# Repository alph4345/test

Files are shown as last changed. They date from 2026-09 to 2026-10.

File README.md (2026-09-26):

# Supercapacitor-powered gadgets

Small games, e-ink displays, blinky jewellery and music toys that charge from
USB-C in minutes and run from a **supercapacitor instead of a LiPo**. The
idea comes from the
[rechargeable supercapacitor Fibonacci earrings](https://lectronz.com/products/rechargeable-supercapacitor-fibonacci-earrings-2).

This repository has:

* **[TrinketCore](hardware/trinketcore)**: an all-in-one 40 × 60 mm trinket
  board with PCBWay order files. It has:
  * pads for two capacitors lying flat on the back;
  * USB-C charging with red "charging" and green "full" LEDs;
  * an RP2040 with 16 MB of flash;
  * a socket for OLED or colour TFT modules (the board reads its charge
    level and can show it);
  * a speaker amplifier, buttons, a wake-up clock and an expansion header.
* **[CapCore](hardware/capcore)**: an open, ready-to-order 21 × 48 mm power
  module (KiCad 7). It has a USB-C charger, capacitor protection, a power
  button, a wake-up clock and a 3.3 V output for your microcontroller.
  Gerbers and JLCPCB assembly files are included.
* **[The burst method](docs/trinket-design-method.md)**: how music boxes,
  games, pets and charms last days to weeks on a capacitor, and how colour
  TFT screens fit in.
* **[Energy budget](docs/energy-budget.md)**: how long a capacitor actually
  runs each kind of gadget, plus a [calculator](tools/energy_calc.py).
* **[Choosing a capacitor](docs/choosing-a-capacitor.md)**: lithium-ion
  capacitors vs. ordinary supercapacitors, part numbers, safety rules.
* **[Buy or build?](docs/buy-or-build.md)**: sourcing options and costs.
* **[Firmware examples](firmware)**: Arduino and MicroPython code for power
  button, sleep/wake, capacitor gauge and shutdown on CapCore, and
  CircuitPython charge-gauge, music-box and e-ink tarot-oracle examples for TrinketCore.

| TrinketCore top | TrinketCore back | CapCore top | CapCore bottom |
|---|---|---|---|
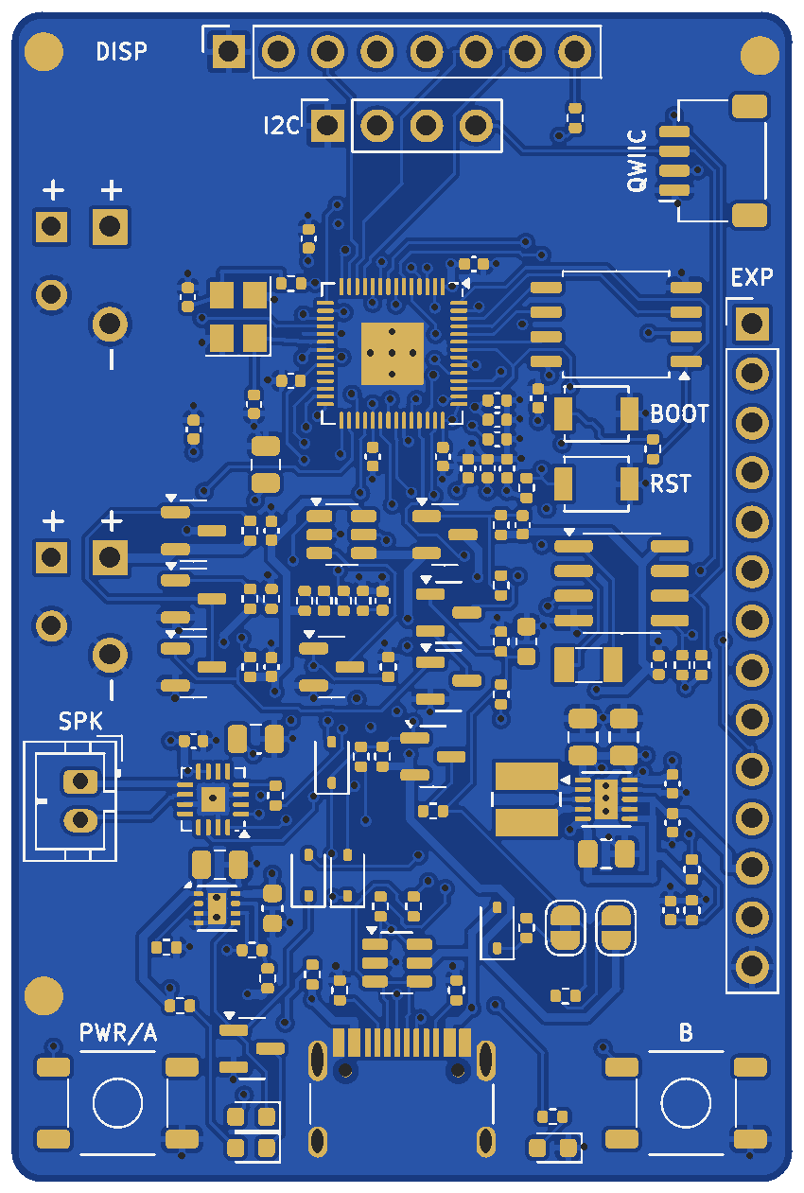
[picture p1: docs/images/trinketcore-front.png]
TrinketCore top
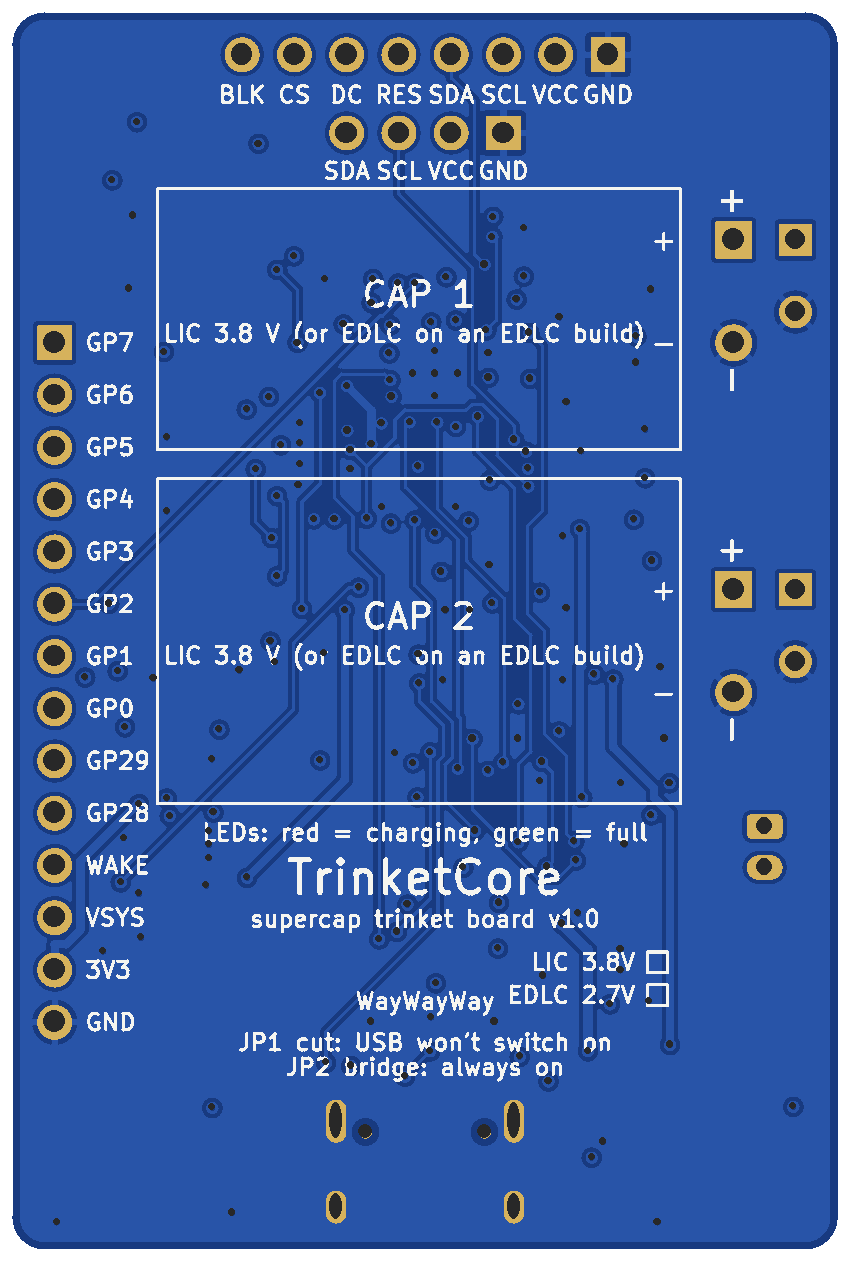
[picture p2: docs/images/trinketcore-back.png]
TrinketCore back
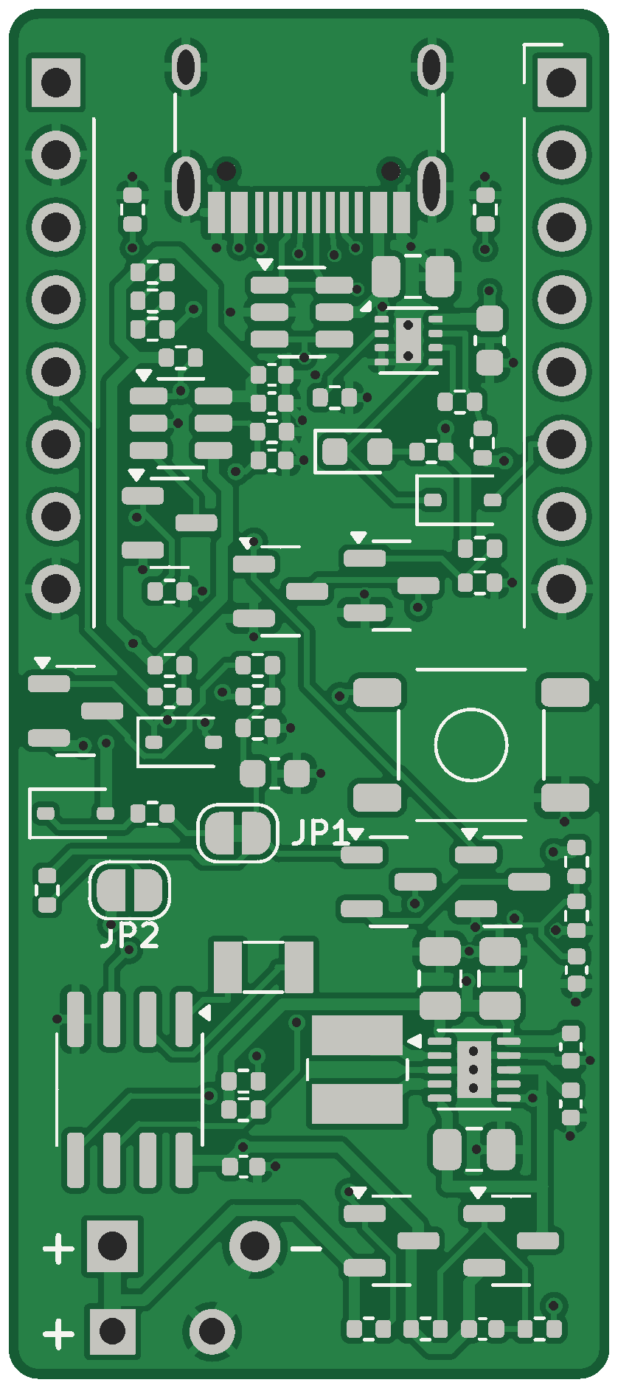
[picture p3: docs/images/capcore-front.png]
CapCore top
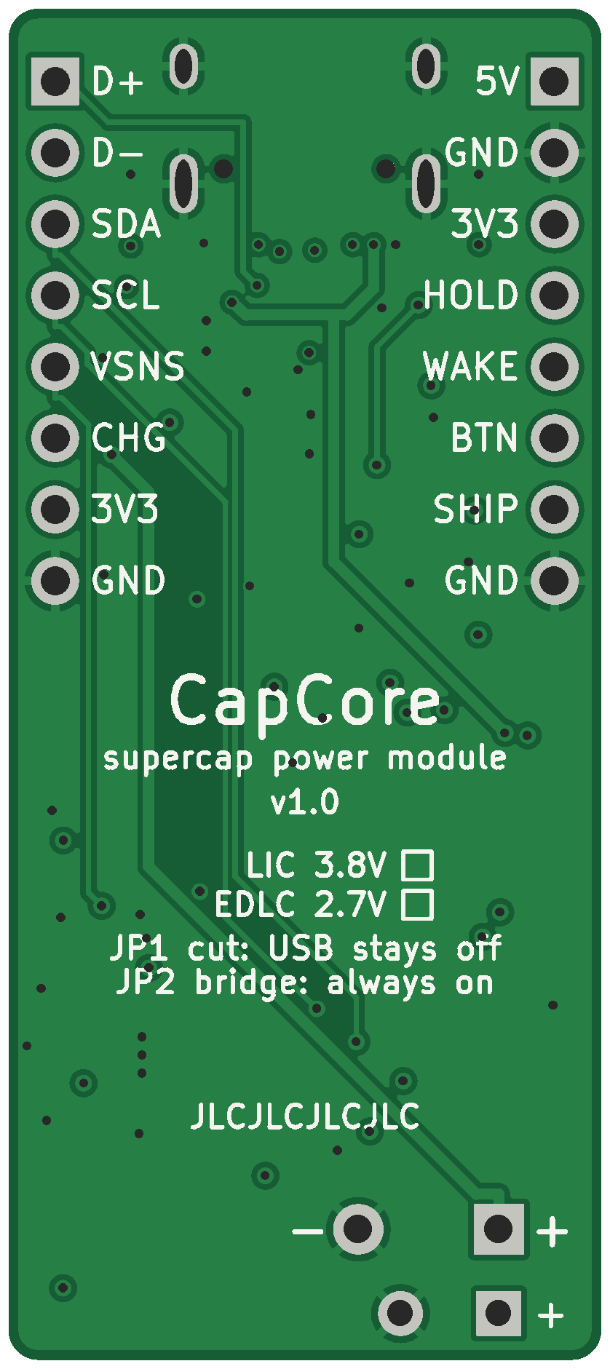
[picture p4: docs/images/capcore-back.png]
CapCore bottom
|  |  |  |  |

## The short answer

* **Capacitors are safe and fast but small.** A 3.8 V lithium-ion capacitor
  (LIC) the size of your fingertip stores ~30 mWh, about a tenth of a
  tiny 100 mAh LiPo. The largest common one (16 × 25 mm) stores ~210 mWh. In
  exchange it charges in minutes, lasts tens of thousands of cycles, and is
  far less of a fire risk. Plain 2.7 V supercapacitors (EDLCs) are essentially
  inert but hold about a tenth as much again for the same size.
* **What that runs, per charge** (with a 120 F LIC, 12.5 × 25 mm):
  LED jewellery ~1.5 days · e-ink display updated hourly ~6 weeks ·
  OLED handheld game ~50 min · MP3 player on a speaker ~15 min.
  E-ink and jewellery are great fits, games work for short sessions, music
  players are a stretch. [Details](docs/energy-budget.md).
* **The electronics matter.** LICs must never go below 2.2 V or above 3.8 V,
  and LiPo chargers (4.2 V) would destroy them. CapCore handles that: it
  charges to 3.71 V, disconnects at 2.61 V and stays off until USB returns.
  Build it for ordinary supercapacitors instead by changing two resistors.

## Quick start

1. Pick a capacitor: [choosing a capacitor](docs/choosing-a-capacitor.md).
2. **For a complete trinket:** order TrinketCore assembled from PCBWay with the
   files in [`hardware/trinketcore/fab`](hardware/trinketcore/fab). See
   [ordering](hardware/trinketcore/README.md#ordering-from-pcbway). Plug in a
   display module, fit the capacitors, and load the
   [CircuitPython examples](firmware/trinketcore).
3. **For your own microcontroller board:** order CapCore from JLCPCB with the
   files in [`hardware/capcore/fab`](hardware/capcore/fab) (see
   [ordering](hardware/capcore/README.md#ordering-from-jlcpcb)), run the
   [bring-up checks](hardware/capcore/README.md#bring-up), and wire it to your
   microcontroller ([Pico, Feather, bare chips](hardware/capcore/README.md#connecting-a-microcontroller)).

## Status

Both designs are complete and machine-checked: each schematic and PCB matches
its netlist pin for pin, and KiCad DRC is clean apart from cosmetic footprint
warnings. **Neither board has been manufactured and tested yet.** Order a
small first batch and follow the bring-up steps before building anything you
depend on.

## Repository layout

```
docs/                   guides and board renders
firmware/               Arduino + MicroPython (CapCore), CircuitPython (TrinketCore)
hardware/trinketcore/   all-in-one board: KiCad project, PCBWay files, generator scripts
hardware/capcore/       power module: KiCad project, JLCPCB files, generator scripts
tools/energy_calc.py    runtime calculator
```

No license file yet. Pick one before sharing the design: for example
CERN-OHL-P-2.0 for the hardware and MIT for the code.

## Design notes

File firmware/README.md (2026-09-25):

# Firmware examples

Two small, dependency-free examples of the firmware side of a
[CapCore](../hardware/capcore) gadget:

| | |
|---|---|
| [`arduino/CapCorePower`](arduino/CapCorePower/CapCorePower.ino) | Arduino sketch for any core with `Wire` (RP2040, ESP32, SAMD, nRF52…) |
| [`micropython/capcore.py`](micropython/capcore.py) + [`main.py`](micropython/main.py) | MicroPython driver + example for a Raspberry Pi Pico |

Both do the same five things:

1. **Raise `HOLD` first thing at boot.** After a button tap the board keeps
   power up for only 1–2 s on its own.
2. **Clear the RTC's alarm/timer flags** (PCF8563 register 0x01) and switch off
   its clock output (register 0x0D). A pending flag keeps the gadget on and
   makes `BTN` read as pressed.
3. **Read the capacitor:** voltage = 2 × `VSENSE`; `CHG` is low while charging.
   `percent()` reports the *energy* left between the cut-off and full, which
   tracks remaining runtime better than voltage does.
4. **Turn off:** wait for the button to be released, then drop `HOLD`. A long
   press (1.5 s) does this in the examples. Also turn off by yourself a
   little above the hardware cut-off so you can save state first.
5. **Sleep and wake:** `sleep_minutes(n)` / `sleepMinutes(n)` sets the
   PCF8563 countdown timer (1–255 minutes), then powers off. The timer
   switches the board back on. `wake_at(h, m)` does the same with the alarm.

`ship_mode()` disconnects the capacitor until USB is plugged in again. Use it
before storing a charged gadget.

## Default wiring (Pico)

| CapCore | Pico | |
|---|---|---|
| 3V3 (J2-3 or J3-7) | 3V3 (pin 36) | and Pico **3V3_EN (pin 37) → GND** |
| GND | GND | |
| HOLD (J2-4) | GP2 | output |
| BTN (J2-6) | GP3 | input, pull-up |
| SHIP (J2-7) | GP6 | output |
| CHG (J3-6) | GP7 | input, pull-up |
| VSENSE (J3-5) | GP26 / ADC0 | |
| SDA / SCL (J3-3 / J3-4) | GP4 / GP5 | I2C0, RTC at 0x51 |

For the EDLC build pass `variant=EDLC` (MicroPython) or change `V_FULL` /
`V_EMPTY` (Arduino).

## Power tips for long runtimes

* Budget with [`tools/energy_calc.py`](../tools/energy_calc.py). A few mA
  saved is often worth more than a bigger capacitor.
* Run the CPU slowly and sleep between frames. On the RP2040 a lower
  `machine.freq()` (MicroPython) or `set_sys_clock_khz()` (C SDK) cuts current a lot.
* For e-ink, don't keep the MCU running between updates: set the RTC timer
  and power the whole board off. Between updates it draws about 5 µA.
* Speakers are the hungriest load. Use headphones, keep the volume down, or
  pick a piezo for chiptune.

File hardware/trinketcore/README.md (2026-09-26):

# TrinketCore: the all-in-one supercapacitor trinket board

TrinketCore puts everything a small rechargeable gadget needs on one
40 × 60 mm board, ready to order assembled from PCBWay:

* **Room for two capacitors.** They lie flat on the back, wired in parallel.
* **USB-C charging**, with a **red "charging" and a green "full" LED**.
* **A socket for an OLED or colour TFT module.** The microcontroller reads
  the capacitor's charge and can show it on the screen.
* **An RP2040 microcontroller** with 16 MB of flash for code, sounds and
  pictures.
* **A speaker amplifier**, two buttons, a user LED, a wake-up clock and an
  expansion header for LEDs, buttons and a lid switch.

The power side is [CapCore](../capcore)'s proven circuit. It cuts off before
the capacitor over-discharges, uses a soft power switch that turns the whole
board off, and has a buck-boost converter that keeps 3.3 V steady as the
capacitor drains.

| Top | Bottom (capacitor bay) |
|---|---|
| TrinketCore top | TrinketCore bottom |

*Renders of the actual Gerber layers. The display plugs into the socket along
the top edge. The capacitors solder into the pads on the left and lie flat
inside the outlines on the back.*

## What's on the board

| | |
|---|---|
| Capacitors | BT1 + BT2 in parallel: one or two 3.8 V lithium-ion capacitors (LIC). **EDLC build:** 2.7 V supercapacitors |
| Charging | USB-C, TI BQ25173, 300 mA: two 220 F capacitors fill in about 30 minutes. **Red LED (CHG)** while charging, **green LED (FULL)** when full (USB plugged in) |
| Protection | disconnects at **2.61 V** (LIC) / **1.96 V** (EDLC) and stays off until USB returns; ship mode for storage |
| Power switch | the whole board is **off between uses (about 5 µA)**. It turns on from button A, a lid/tilt switch on `WAKE`, the clock alarm, or USB. Firmware keeps it on with `HOLD` |
| 3.3 V | TI TPS63031 buck-boost, ~500 mA even from a nearly empty capacitor |
| Microcontroller | Raspberry Pi RP2040, 12 MHz crystal, **16 MB** Winbond flash, USB-C data for programming, BOOT and RESET buttons (SWD is not broken out: the USB bootloader is in ROM) |
| Display | **J4**: socket for SPI TFT/OLED modules (GND VCC SCL SDA RES DC CS BLK), backlight dimmable by PWM. **J5**: 4-pin I²C OLED socket. **J8**: Qwiic/STEMMA QT |
| Charge reading | capacitor voltage on an ADC pin, plus "charging" and "USB present" inputs |
| Sound | MAX98357A I²S class-D amplifier, 9 dB gain, shut down when idle; **J7** speaker connector (JST PH 2.0 or solder the wires) |
| Clock | NXP PCF8563 real-time clock: wakes the board on a timer or alarm (virtual pets, e-ink updates) |
| Buttons | **A / POWER** (turns the board on and is readable by firmware), **B**, BOOT, RESET |
| LEDs | red CHG, green FULL (charging), blue user LED on GP25 |
| Expansion | **J6**, 14 pins: GP0–GP7, GP28–GP29 (analog), `WAKE`, `VSYS`, 3V3, GND |
| Board | 4 layers, 40 × 60 × 1.6 mm, all parts on top, PCBWay standard rules (6/6 mil, 0.3 mm holes) |

## Which display?

The socket fits the common 0.96–1.54″ modules, so you can try several and pick
per product. A screen is the second-biggest power draw after a speaker, so
the firmware uses it in short bursts: wake, show, dim, switch off.

| Display | Colour | Draw (with the RP2040 running) | Good for |
|---|---|---|---|
| 0.96″ SSD1306 OLED, 128 × 64 (SPI on J4 or I²C on J5) | mono | ~35–40 mA; dark screens use less | games, menus, pets |
| 1.3–1.54″ ST7789 IPS TFT, 240 × 240 | **full colour** | ~45 mA at 60 % backlight, ~30 mA dimmed | colour animations, charms, games |
| 1.28″ GC9A01 round TFT, 240 × 240 | **full colour** | about the same as the ST7789 | keychain "digital charms" |
| 1.54″ 200 × 200 or 3.7″ 480 × 280 e-paper module (SSD1681 and similar) | black/white, 4 greys, or black/white/red | nothing between refreshes; ~30 mA for 2–3 s per black/white refresh (~14 s for three-colour) | tarot oracles, badges, pets, clocks: always visible |

**Yes, colour TFTs work well.** The backlight is most of the extra power, so
dim it and switch off after a few seconds. On two 220 F capacitors a colour
charm shown for 10 s, 30 times a day, lasts about four weeks. Played
continuously, a colour game lasts about two hours. See
[the design method](../../docs/trinket-design-method.md) for the numbers.

Module pin orders vary. Modules labelled `GND VCC SCL SDA RES DC CS BLK` plug
straight into J4. Seven-pin OLEDs (`GND VCC D0 D1 RES DC CS`) use the first
seven positions. Others, including many GC9A01 modules (`VCC GND ...`), need
short jumper wires. **Check that GND and VCC line up before plugging in.**

**E-ink works too**, and suits anything that should stay visible: the image
costs no power at all once drawn, so the board can switch fully off. E-paper
modules have a BUSY output where TFTs have a backlight input. Wire them to J4
by function (VCC → 3V3, GND, DIN → MOSI, CLK → SCK, CS, DC, RST → RES) with
BUSY on the BLK pin, which the RP2040 reads on GP13. The
[oracle example](../../firmware/trinketcore/circuitpython/oracle/code.py) shows a
random tarot card this way.

## Runtime per charge

LIC build, 85 % converter efficiency, 5 µA standby
([`tools/energy_calc.py`](../../tools/energy_calc.py)):

| Trinket | 1 × 120 F | 1 × 220 F | 2 × 220 F |
|---|---|---|---|
| Music box: 20 s tune + LEDs (~70 mA), 10 plays a day | 75 plays (8 days) | 138 plays (14 days) | 276 plays (4 weeks) |
| Colour TFT charm: 10 s shows (45 mA), 30 a day | 8 days | 14 days | 4 weeks |
| Virtual pet on e-paper: wakes every 30 min (30 mA × 3 s) | 3 weeks | 6 weeks | 3 months* |
| Tarot oracle on e-paper: a card per press (30 mA × 5 s), 10 a day | 600 draws (2 months) | 1,100 draws* | 2,200 draws* |
| OLED game, continuous (40 mA) | 45 min | 80 min | 2.7 h |
| Colour TFT game, continuous (55 mA) | 33 min | 60 min | 2 h |

\* Beyond a month or two the capacitors' own self-discharge dominates.

## Fitting the capacitors

The two capacitor positions sit along the left edge. **Square pad = +.** Each
position takes a 5.0 mm lead pitch (10–12.5 mm cans) or 3.5 mm (8 mm cans).
Bend 16 mm cans' 7.5 mm leads in slightly. Bend the leads 90° so each can lies
flat on the back inside its outline (`CAP 1`, `CAP 2`), with its leads at the
left edge. Stick a strip of Kapton tape under each can, and glue or strap
large cans.

* One capacitor is fine: fit either position.
* Two capacitors must be **the same type** (both LIC, or both EDLC on an EDLC
  build). Sizes may differ.
* Good choices: Eaton HS1225-3R8127-R (120 F, 12.5 × 25 mm) or HS1625-3R8227-R
  (220 F, 16 × 25 mm). See [choosing a capacitor](../../docs/choosing-a-capacitor.md).

> **Never fit a 2.7 V supercapacitor to a board built with the LIC values.**
> It would be charged to 3.71 V and can vent. Tick the build box on the back,
> and measure the charge voltage before fitting capacitors (see
> [Bring-up](#bring-up)).

## Pinout

**J4 display socket** (top edge, pin 1 = square pad, left):
GND · 3V3 · SCK (GP10) · MOSI (GP11) · RES (GP12) · DC (GP9) · CS (GP8) · BLK (GP13 via 100 Ω)

**J5 I²C OLED socket**: GND · 3V3 · SCL (GP17) · SDA (GP16).
**J8 Qwiic**: GND · 3V3 · SDA · SCL. The same bus as the clock (address 0x51),
with 4.7 kΩ pull-ups.

**J6 expansion** (right edge, pin 1 at the top): GP7 · GP6 · GP5 · GP4 · GP3 ·
GP2 · GP1 · GP0 · GP29 · GP28 · WAKE · VSYS · 3V3 · GND. The order matches the
RP2040's pins, which keeps the tracks from crossing; the back silkscreen labels
every pin.

* `WAKE`: pull to GND to switch the board on (lid, tilt, reed or vibration
  switch). For a **lid** that may stay open, put a 1 µF capacitor in series
  with the switch and a 22 MΩ resistor across that capacitor. Opening the
  lid then sends one wake pulse, and the board can still switch itself off.
* `VSYS`: the capacitor voltage (2.6–3.7 V), on only while the board runs.
  Use it for vibration motors or LED strips that tolerate it.
* GPIO pins drive LEDs directly, up to ~8 mA each through a resistor.

**J7 speaker**: 8 Ω, 0.5–1 W. **GPIO map**: see the
[firmware README](../../firmware/trinketcore/README.md#pin-map).

## LEDs and power states

| LED | Meaning |
|---|---|
| red **CHG** | charging |
| green **FULL** | USB plugged in and the capacitors are full |
| red and green blinking alternately | charger fault (for example a capacitor wired backwards, or overheating) |
| blue | yours (GP25) |

With USB plugged in the board also switches on, so a gauge can show charging
progress. Cut jumper **JP1** on the back if plugging in should only charge.
Bridge **JP2** for gadgets without a power button (always on above the
cut-off).

| State | Drain from the capacitors | Leaves the state when… |
|---|---|---|
| Running | your load ÷ ~85 % | firmware drops `HOLD` |
| Off | ~5 µA (clock running) | button A, `WAKE`, clock alarm/timer, USB |
| Cut-off / ship mode | leakage only | USB is plugged in |

## Ordering from PCBWay

Everything is in [`fab/`](fab):

| File | Upload / use |
|---|---|
| `trinketcore-gerbers.zip` | the PCB (Gerbers + drill) |
| `pcbway-bom-lic.csv` (or `-edlc.csv`) | assembly BOM for your build |
| `pcbway-centroid.csv` | pick-and-place positions (mm, origin at the bottom-left corner, same as the Gerbers) |
| `trinketcore-assembly-top.pdf`, `-back.pdf` | assembly drawings, if PCBWay asks |
| `parts-list.csv` | every part, including the ones you fit yourself |

1. On pcbway.com choose **PCB Instant Quote → Quick-order PCB** and upload
   `trinketcore-gerbers.zip`. It should read **40 × 60 mm** and **4 layers**.
2. Board settings:
   * Material FR-4, thickness **1.6 mm**, any solder mask colour.
   * Min track/spacing **6/6 mil**, min hole size **0.3 mm**.
   * Surface finish: **ENIG is recommended** because the RP2040 has 0.4 mm-pitch
     pads. HASL lead-free usually works too.
   * Order number: the back has a `WayWayWay` placeholder where PCBWay can
     print it. Tell them in the notes, or pick the remove-order-number option.
3. Tick **Assembly service**: turnkey, **top side only**, about
   **102 SMD parts (44 unique lines)**, no through-hole parts. Upload
   `pcbway-bom-lic.csv` and `pcbway-centroid.csv`.
4. Paste this note:
   *"BT1, BT2, J4–J7, JP1–JP2: do not populate (customer fits
   capacitors and connectors). J8 and all other parts: assemble as per BOM.
   Please confirm pin 1 of U2, U3, U4, U5, U6, U7, U8 and the LED polarity
   against the silkscreen before assembly."*
5. PCBWay's engineers review the files, source the parts, and email if a part
   needs a substitute. Resistors and capacitors may be any brand with the same
   value, size and tolerance. Approve their placement confirmation photos.

**Rough cost** (prices change, so trust the quote): about US$25–50 for five
4-layer boards, plus assembly (setup ~US$30–50, parts ~US$8–12 per board
with the RP2040, flash and amplifier). Five assembled boards typically land
around US$100–180 before shipping. Most of that is fixed, so ten cost little
more.

The same files work at other assembly houses (the BOM has manufacturer part
numbers, and LCSC numbers where known).

## Bring-up

Before fitting the capacitors:

1. Plug in USB-C. The red and green LEDs may flicker (nothing to charge yet),
   and the board switches on.
2. Measure between the square BT1 pad and GND: about **3.7 V** is the LIC build,
   **2.6 V** the EDLC build.
3. The computer should show an `RPI-RP2` drive (blank flash starts the
   bootloader). Install CircuitPython and try the
   [charge gauge](../../firmware/trinketcore) with a display on J4.

Then unplug USB, fit the capacitors (**square pad = +**), and plug USB back
in: red while charging, green when full. Unplug and press A: the board runs
for about 5 s, or longer if firmware raises `HOLD`. A new capacitor that
arrives below the cut-off keeps the board off until it has charged past it.

## Design files

| File | |
|---|---|
| `trinketcore.kicad_pro/.kicad_sch/.kicad_pcb` | KiCad 7 project |
| `trinketcore-schematic.pdf` | schematic |
| `TrinketCore.kicad_sym`, `TrinketCore.pretty/` | project symbols and footprints |
| `trinketcore.ses` | autorouter result that `route_pcb.py` rebuilds the board from |
| `scripts/` | the generators |

As with CapCore, the board is generated from code:

```
cd hardware/trinketcore/scripts
python3 gen_footprints.py
python3 gen_schematic.py && python3 check_netlist.py
python3 check_place.py
FREEROUTING_JAR=/path/to/freerouting-1.9.0.jar python3 route_pcb.py --autoroute
python3 check_netlist.py --pcb && python3 export_fab.py && python3 render.py
```

`netlist.py` is the single source of truth: parts, values, manufacturer part
numbers and every connection. Autorouting needs Java and
[Freerouting](https://github.com/freerouting/freerouting) 1.9.0 (under
`xvfb-run` on a headless machine); without `--autoroute` the board is rebuilt
from the committed `trinketcore.ses`. The crystal and the power fan-outs are
drawn by hand in `preroute.py`, and a small grid router (`maze.py`) finishes
whatever Freerouting leaves open.

**Verification status:** the schematic and PCB are checked pin-for-pin against
`netlist.py` (378 pins). KiCad DRC with PCBWay's limits reports no errors and
no unconnected items, only one warning: the USB-C footprint differs from the
library copy because its silkscreen was trimmed at the board edge. The routing
is automatic, so some tracks take detours a hand layout wouldn't. The board
has **not been built and tested yet**: treat the first order as a prototype run
and follow the bring-up steps.

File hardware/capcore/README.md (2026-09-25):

# CapCore: supercapacitor power module

CapCore is a 21 × 48 mm board that does the power side of a small gadget, with
a supercapacitor where a LiPo would normally go. Plug in USB-C and it charges
the capacitor. Press the button and it turns your circuit on and feeds it a
steady 3.3 V. When the capacitor is empty it turns everything off and stays
off until USB comes back.

| Top | Bottom |
|---|---|
| CapCore top | CapCore bottom |

*Renders of the actual Gerber layers. The capacitor is not shown; it solders into the pads at the bottom left.*

## What it does

| | |
|---|---|
| Input | USB-C, 5 V (5.1 kΩ CC pull-downs, so any USB-C charger works), ESD-protected (USBLC6-2SC6) |
| Charger | TI BQ25173: 300 mA constant current, then constant voltage. Red LED on while charging |
| Capacitor | **LIC build:** 3.8 V lithium-ion capacitor, charged to 3.71 V. **EDLC build:** 2.7 V supercapacitor, charged to 2.62 V |
| Cut-off | TI TPS3808: disconnects the capacitor at **2.61 V** (LIC) / **1.96 V** (EDLC) and latches off until USB returns |
| Ship mode | Firmware can disconnect the capacitor completely (for storage or shipping). Only USB wakes it |
| Output | 3.3 V from a TI TPS63031 buck-boost: stays at 3.3 V whether the capacitor is above or below 3.3 V. About 500 mA available near the cut-off, more when full |
| Power button | Press to turn on; firmware keeps power with `HOLD` and drops it to turn off |
| Wake-up clock | NXP PCF8563 real-time clock on I²C (address 0x51). Its alarm or timer can turn the gadget on, e.g. for an e-ink update once an hour |
| Monitoring | `VSENSE` = capacitor voltage ÷ 2 for your ADC; `CHG` low while charging |
| USB data | D+/D− from the USB-C port go to the header, so one port can charge *and* program/talk to your microcontroller |
| Standby drain | ~5 µA when off with the clock running; only leakage after a cut-off or in ship mode |
| Board | 4 layers, 21 × 48 mm, all parts on top, two 8-pin 0.1″ headers 0.7″ apart (breadboard-friendly, like a Raspberry Pi Pico) |

Two build variants share one PCB and differ only in two resistors:

| Variant | For | R4 | R13 | Charges to | Cuts off at |
|---|---|---|---|---|---|
| **LIC** (default) | 3.8 V lithium-ion capacitors (Eaton HS series etc.) | 120 k | 330 k | 3.71 V | 2.61 V |
| **EDLC** | ordinary 2.7 V supercapacitors | 75 k | 470 k | 2.62 V | 1.96 V |

> **Never fit a 2.7 V supercapacitor to a board built with the LIC values.** It
> would be charged to 3.71 V, well past its rating, and can vent. Tick the
> variant box on the back of the board when it arrives, and measure the charge
> voltage before fitting the capacitor (see [Bring-up](#bring-up)).

## Pinout

Pin 1 of both headers is at the USB-C end. The names are printed on the back.

| Pin | Left header (J2) | Direction | Right header (J3) | Direction |
|---|---|---|---|---|
| 1 | **VBUS**: 5 V from USB (silk: 5V) | out* | **D+** from USB-C | ↔ |
| 2 | **GND** | | **D−** from USB-C | ↔ |
| 3 | **3V3**: regulated output | out | **SDA**: RTC, 4.7 k pull-up to 3V3 | ↔ |
| 4 | **HOLD**: drive high to stay on | in | **SCL**: RTC, 4.7 k pull-up to 3V3 | in |
| 5 | **WAKE**: pull low to turn on | in | **VSENSE**: capacitor voltage ÷ 2 (only while on) | out |
| 6 | **BTN**: reads low while the button is pressed | out, needs pull-up | **CHG**: low while charging | out, needs pull-up |
| 7 | **SHIP**: pulse high for ship mode | in | **3V3**: regulated output | out |
| 8 | **GND** | | **GND** | |

\* VBUS can also be used as a 5 V *input* instead of the USB-C port. Never
connect both at once.

Directions are from CapCore's point of view: *in* means your microcontroller
drives it. `BTN` and `CHG` are read through diodes, so enable the internal
pull-up on those microcontroller pins. Their "low" is the diode drop (about
0.5 V), which any 3.3 V microcontroller reads as low.

## How it works

```
USB-C ──ESD──┬── BQ25173 charger ── VCAP ─┬─ capacitor (BT1)
             │                            │
             │               Q1 master switch (off below the cut-off, or in ship mode)
             │                            │
             │                          VAON ── supervisor, RTC, wake logic (always on, ~5 µA)
             │                            │
             │               Q5 load switch (on while EN_SYS is high)
             │                            │
             │                          VSYS ── TPS63031 buck-boost ── 3V3 ── your circuit
             │                            └──── VSENSE (÷2)
             └── Q2: USB turns Q1 back on after a cut-off
```

* **Master switch (Q1).** The capacitor only reaches the rest of the board
  through Q1. The supervisor (U3, TPS3808) keeps Q1 on while the capacitor is
  above the cut-off. Below it, Q1 opens. The supervisor then loses power too,
  so Q1 stays open: the capacitor sees only leakage and cannot be
  over-discharged. Plugging in USB turns Q1 on again (Q2). Once the capacitor
  has charged back above the cut-off, the supervisor takes over.
* **Load switch (Q5).** Your circuit is powered while `EN_SYS` is high. It
  goes high from the **button** (SW1), the **RTC alarm or timer**, the
  **WAKE** pin, **USB** (jumper JP1, bridged by default), **HOLD** from your
  firmware, or permanently if **JP2** is bridged. C8 keeps `EN_SYS` up for
  about 1–2 s after a button press so your firmware can raise `HOLD`.
* **Supervisor gate (Q8).** Q6 turns the load switch on only through Q8, and
  Q8 is driven by the supervisor. Below the cut-off nothing can turn the
  gadget on, not even USB. The charger then gets the capacitor back up before
  your circuit starts drawing from it.
* **Charger.** The BQ25173 regulates the capacitor to
  0.8 V × (1 + R4/R5). R5 returns to the charger's /PG pin, so the divider
  draws nothing when USB is unplugged. Charge current is 300 V / R3
  (1 kΩ → 300 mA). A smaller R3 charges faster, up to 800 mA, but the charger
  gets hot and throttles itself.

### Jumpers

| Jumper | Default | Change it to… |
|---|---|---|
| **JP1 USB-ON** | bridged | **cut** it if plugging in USB should only charge, not switch the gadget on |
| **JP2 ALWAYS-ON** | open | **bridge** it for gadgets without a power button (jewelry, badges): they run whenever the capacitor is above the cut-off |

### Power states

| State | What is on | Drain from the capacitor | Leaves the state when… |
|---|---|---|---|
| Running | everything | your load ÷ ~85 % efficiency | `HOLD` goes low and nothing else holds `EN_SYS` |
| Off | supervisor, RTC | ~5 µA | button, RTC alarm/timer, `WAKE`, USB (JP1) |
| Cut-off | nothing | leakage (< 1 µA) | USB is plugged in |
| Ship mode | nothing | leakage (< 1 µA) | USB is plugged in |

## Firmware rules

See [`firmware/`](../../firmware) for Arduino and MicroPython examples. The essentials:

1. **Raise `HOLD` as the very first thing at boot.** C8 only keeps power up for about 1 s (EDLC) to 2 s (LIC) after a button tap.
2. **Clear the RTC flags early.** The RTC's interrupt holds the gadget on (and makes `BTN` read low) until you clear its alarm/timer flag (write 0 to register 0x01). Also write 0 to register 0x0D to turn off the RTC's clock output; that saves about 1 µA.
3. **To turn off:** wait for the button to be released, then drive `HOLD` low. Power drops within ~0.5 s. It can't turn off while USB is plugged in with JP1 bridged, or with JP2 bridged.
4. **To sleep until later:** set a PCF8563 alarm or countdown timer with its interrupt enabled, then drop `HOLD`.
5. **Watch `VSENSE`:** capacitor voltage ≈ 2 × VSENSE. Save your state and power off yourself a little above the cut-off (e.g. at 2.75 V on an LIC); the hardware cut-off is abrupt.
6. **Ship mode:** drive `SHIP` high. Everything switches off, and only USB brings it back. Use it before storing or posting a charged gadget.

## Connecting a microcontroller

Wire `3V3` and `GND` to your board's 3.3 V rail, **bypassing its own regulator**:

* **Raspberry Pi Pico / Pico W:** CapCore 3V3 → Pico 3V3 (pin 36), and tie
  Pico **3V3_EN (pin 37) to GND** to switch off the Pico's own regulator. The
  Pico's USB port still works for programming. CapCore's D+/D− can only reach
  the RP2040 through the Pico's test pads (TP2/TP3).
* **Adafruit Feather (and similar):** CapCore 3V3 → Feather 3V pin, Feather **EN to GND**.
* **Bare chips / your own board** (RP2040, ATtiny, nRF52, ESP32-C3 modules…):
  run them straight from 3V3, and wire D+/D− to the chip's USB pins if it has them.
* **Seeed XIAO and other boards without a regulator-enable pin:** check the
  board's documentation before feeding 3.3 V into its 3V3 pin.

Then wire `HOLD`, `BTN`, `CHG` and `SHIP` to spare GPIOs, `VSENSE` to an ADC
pin, and `SDA`/`SCL` to I²C. Radios with big current peaks (ESP32 Wi-Fi,
~350–500 mA) need a large, low-ESR capacitor. Bluetooth LE parts like the
nRF52 are a much better match.

## Fitting the capacitor

BT1 takes radial through-hole capacitors with a **5.0 mm** (10–12.5 mm cans)
or **3.5 mm** (8 mm cans) lead pitch. **The square pads are +.** Cans with a
7.5 mm pitch (16 mm diameter) need their leads bent in, or short wires. The can
can stand upright, lie flat over the board (the sleeve is insulated; add a
strip of Kapton tape to be safe), or be folded flat past the bottom edge. See
[choosing a capacitor](../../docs/choosing-a-capacitor.md) for sizes and part
numbers.

## Ordering from JLCPCB

Everything needed is in [`fab/`](fab):

| File | What it is |
|---|---|
| `capcore-gerbers.zip` | Gerbers + drill files; upload this |
| `jlcpcb-bom-lic.csv` / `jlcpcb-bom-edlc.csv` | assembly BOM for the variant you want (they differ in R4 and R13 only) |
| `jlcpcb-cpl.csv` | pick-and-place positions (same for both variants) |
| `parts-list.csv` | every part, including the ones you fit yourself |
| `capcore-assembly-top.pdf` | assembly drawing |

1. Upload `capcore-gerbers.zip`. The site should detect 4 layers and
   21 × 48 mm. Keep 1.6 mm thickness. Any colour works. For
   *Remove Order Number* choose *Specify a location*: there is a
   `JLCJLCJLCJLC` placeholder on the back.
2. Turn on **PCB Assembly** (top side). Upload the BOM for your variant and `jlcpcb-cpl.csv`.
3. On the parts page every line should match its LCSC number. About seven
   are *Extended* parts (usually the USB-C socket, inductor, button, USBLC6,
   BQ25173, TPS3808 and TPS63031), each with a small one-time setup fee.
4. **Check the placement preview before paying.** The positions come straight
   from KiCad. Confirm that every IC's pin-1 dot sits on the pin-1 corner of its
   footprint (U1–U5), the transistors (Q1–Q8) and diodes (D1–D4, cathode bar)
   match the silkscreen, and the USB-C socket opens towards the board edge.
   Rotate any part that is off in the web viewer.
5. BT1 (the capacitor), J2/J3 (headers) and the solder jumpers are not in the
   BOM; you fit them yourself.

Prices change often, so trust the live quote. As a rough guide, five
assembled boards come to something like US$50–80 before shipping. Most of that
is fixed setup, stencil and extended-part fees, so 10–20 boards cost little
more in total.

## Bring-up

Do this **before** fitting the capacitor:

1. Plug in USB-C. The red LED may glow or flicker (there is nothing to charge).
2. Measure between the BT1 pads (square = +): about **3.7 V** means the LIC
   build and about **2.6 V** the EDLC build. If it reads 3.7 V, do not fit a
   2.7 V supercapacitor.
3. With JP1 bridged (the default), `3V3` should appear on the header a moment
   after USB is plugged in.

Then unplug USB and solder the capacitor, **square pad = +**. Plug USB back in
and let it charge; the LED turns off when it is full. Unplug USB and press the
button: 3V3 should appear for ~1–2 s and then drop, because nothing is holding
`HOLD` high yet. A new capacitor that arrives below the cut-off voltage keeps
the gadget off until it has charged past the cut-off. That is intended.

## Design files

| File | |
|---|---|
| `capcore.kicad_pro/.kicad_sch/.kicad_pcb` | KiCad 7 project; opens in KiCad 7 or newer |
| `capcore-schematic.pdf` | schematic as a PDF |
| `CapCore.kicad_sym`, `CapCore.pretty/` | project symbol and footprint libraries |
| `capcore.ses` | autorouter result that `route_pcb.py` rebuilds the board from |
| `scripts/` | the generators, below |

The design is generated from code, so the schematic and PCB can't drift apart:

```
scripts/netlist.py        single source of truth: parts, values, LCSC numbers, nets
scripts/gen_symbols.py    symbol library (CapCore.kicad_sym)
scripts/gen_schematic.py  schematic; then check_netlist.py proves it matches netlist.py
scripts/gen_pcb.py        outline, stack-up rules, placement, silkscreen
scripts/preroute.py       hand-planned copper: USB-C escape, buck-boost loop, ground vias
scripts/route_pcb.py      Freerouting + grid-router finish, ground pours, DRC
scripts/export_fab.py     Gerbers, drill, BOM/CPL, PDFs
scripts/render.py         the board images above
```

To change something, edit `netlist.py` (and the layout dictionaries if you
add parts), then run:

```
cd hardware/capcore/scripts
python3 gen_schematic.py && python3 check_netlist.py
python3 check_place.py
FREEROUTING_JAR=/path/to/freerouting-1.9.0.jar python3 route_pcb.py --autoroute
python3 check_netlist.py --pcb && python3 export_fab.py && python3 render.py
```

This needs KiCad 7's Python module (`pcbnew`) and `kicad-cli`, plus
`pip install shapely cairosvg pillow`. Autorouting also needs Java and
[Freerouting](https://github.com/freerouting/freerouting) 1.9.0 (run under
`xvfb-run` on a headless machine). Without `--autoroute` the board is rebuilt
from the committed `capcore.ses`.

**Verification status:** the schematic and PCB are checked pin-for-pin against
`netlist.py` (203 pins). KiCad DRC reports no errors and no unconnected items,
only three warnings: the headers and the USB-C footprint differ from the
library copies because their silkscreen was trimmed at the board edge. The
board has **not been built and tested yet**. Treat the first order as a
prototype run and follow the bring-up steps.

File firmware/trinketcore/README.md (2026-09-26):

# TrinketCore firmware (CircuitPython)

Examples for the [TrinketCore](../../hardware/trinketcore) board. They use
CircuitPython because its built-in display (`displayio`) and sound
(`synthio`, `audiobusio`) support make trinkets quick to write.

| Example | What it does |
|---|---|
| [`charge_gauge`](circuitpython/charge_gauge/code.py) | Wakes, shows the charge level on the display for a few seconds, dims, switches off. Stays on and shows progress while charging. |
| [`music_box`](circuitpython/music_box/code.py) | Opening the lid plays a short synthesised music-box tune with LEDs that pulse on each note, then switches the whole board off. |
| [`oracle`](circuitpython/oracle/code.py) | A digital oracle: each press draws a random tarot card and shows it on an e-ink screen with a small charge icon, then switches the board off. The card stays on screen with no power. [`make_cards.py`](circuitpython/oracle/make_cards.py) turns your card art into e-ink images. |
| [`lib/trinketcore.py`](circuitpython/lib/trinketcore.py) | Board support: power hold/off, charge level, charging and USB status, RTC wake-up timer, speaker, pin names. |

## Getting started

1. **Install CircuitPython.** A new board with blank flash starts in the USB
   bootloader by itself and shows up as a drive called `RPI-RP2`. Otherwise
   hold **BOOT**, tap **RESET**, then release BOOT. Drag on a CircuitPython
   UF2 for any RP2040 board. The *Raspberry Pi Pico* build works and uses
   2 MB of the flash. A 16 MB build such as *Pimoroni Pico LiPo (16MB)* lets
   you use all of it for sounds and pictures.
2. Copy `lib/trinketcore.py` into `CIRCUITPY/lib/`, and one example's
   `code.py` to the root of `CIRCUITPY`.
3. For the charge gauge, also copy from the
   [Adafruit library bundle](https://circuitpython.org/libraries):
   `adafruit_display_text`, plus your display's driver
   (`adafruit_st7789`, `adafruit_st7735r`, `adafruit_displayio_ssd1306`, or
   the community `gc9a01`). Set `DISPLAY = ...` at the top of `code.py`.
4. For the oracle, copy `adafruit_ssd1681` and `adafruit_display_text`, and a
   `cards` folder made with `python3 make_cards.py my_art cards` (needs
   Pillow on your computer). A black-and-white deck of 78 cards takes about
   0.4 MB; a black/white/red deck takes about 3 MB, so use a 16 MB build.

The first line of every `code.py` is `import trinketcore`. It raises `HOLD`
at once: after a button press the board powers itself for only about 4–6 s.

## The pattern that makes a capacitor last

Every example follows the same four steps:

1. **Wake** from a button, the lid switch or the RTC timer. The whole board
   was off, drawing about 5 µA.
2. **Do one short burst**: show the screen for a few seconds, or play a
   15–30 s tune.
3. **Dim, shut the amplifier down** (`AMP_EN` low), and turn LEDs off as
   soon as they're not needed.
4. **Switch everything off** with `tc.power_off()`, or `tc.sleep_minutes(n)`
   to wake again later (virtual pets, e-ink updates).

`tc.percent()` is the energy left between the cut-off and full, which
tracks remaining runtime. `tc.low()` turns true a little above the hardware
cut-off, so you can save state and play a "charge me" sound before the
board switches itself off.

## E-paper modules

E-paper modules (1.54″ 200 × 200 with an SSD1681 controller, such as the
Waveshare 1.54″ V2 or WeAct 1.54″) have a BUSY output instead of a
backlight. Wire them to J4 by function: VCC → 3V3, GND → GND, DIN → MOSI,
CLK → SCK, CS → CS, DC → DC, RST → RES, and BUSY → BLK, which the RP2040
reads on GP13 (`trinketcore.EPD_BUSY`). Always wait for BUSY to clear
before switching off: cutting power mid-refresh leaves a faded image.

## Pin map

| GPIO | Use | GPIO | Use |
|---|---|---|---|
| GP0–GP7 | expansion J6 (LEDs, buttons, sensors) | GP18 | I2S data |
| GP8 | display CS | GP19 | I2S bit clock |
| GP9 | display DC | GP20 | I2S word select |
| GP10 | display SCK | GP21 | amplifier on (high) |
| GP11 | display MOSI | GP22 | CHG (low = charging) |
| GP12 | display reset | GP23 | power button A (low = pressed) |
| GP13 | backlight (PWM) | GP24 | USB power present (low) |
| GP14 | button B | GP25 | user LED (blue) |
| GP15 | SHIP (pulse high = storage mode) | GP26 | HOLD (high = stay on) |
| GP16 / GP17 | I2C SDA / SCL (RTC 0x51, OLED, Qwiic) | GP27 | capacitor voltage ÷ 2 (analog) |
| | | GP28, GP29 | expansion J6, analog |

GP22, GP23 and GP24 are read through diodes: enable the pull-ups (the library
does). The pin map works with MicroPython and Arduino-Pico too, and the logic
is the same as in the CapCore examples in [`../micropython`](../micropython) and
[`../arduino`](../arduino).

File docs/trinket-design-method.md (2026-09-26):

# The burst method: how to make capacitor trinkets last

A supercapacitor stores about a tenth of the energy of a same-size LiPo, but
it charges in minutes and survives tens of thousands of cycles. Trinkets that
last days to weeks per charge all follow the same method. It is built into
[TrinketCore](../hardware/trinketcore) and its
[firmware examples](../firmware/trinketcore).

## The method

1. **Off is the default.** Between uses the whole board is switched off, not
   asleep. TrinketCore draws about 5 µA then, so a capacitor loses almost
   nothing waiting in a drawer. (A microcontroller "sleeping" with its
   display and amplifier powered would draw a thousand times more.)
2. **Wake on an event.** Use a button, a lid or tilt switch on `WAKE`, or
   the clock's timer or alarm for scheduled jobs such as a pet getting
   hungry or an e-ink refresh.
3. **Do one short burst.** Show the screen for a few seconds, or play a
   15–30 s tune.
4. **Spend the burst efficiently:**
   * dim the backlight;
   * keep the volume moderate (speaker power grows with the square of the
     volume);
   * light LEDs at a few mA and only while needed;
   * shut the amplifier down (`AMP_EN` low) the moment the sound ends.
5. **Switch off again** (`power_off()`), or set the clock to wake up later
   (`sleep_minutes()`).
6. **Budget, then size the capacitors.** Multiply energy per burst by bursts
   per day, compare with the capacitors' usable energy, then pick one or two
   capacitors. [`tools/energy_calc.py`](../tools/energy_calc.py) does the
   arithmetic:
   `python3 tools/energy_calc.py --cap lic:220 --active-ma 70 --active-s 20 --per-day 10`.
7. **Show the charge level** as part of each burst: a battery icon for a
   second on the display, or a "sleepy" sound. The green LED shows when
   charging is complete.

Energy per burst = current × 3.3 V × seconds ÷ 0.85. Two 220 F lithium-ion
capacitors hold 1,530 J usable, so a 5 J burst gives about 300 uses per
charge.

## Colour TFT screens

Yes, colour TFTs work. What matters is the **backlight**:

| Display | Typical draw incl. the RP2040 | Two 220 F capacitors |
|---|---|---|
| 1.3–1.54″ ST7789 or 1.28″ GC9A01 colour TFT, backlight 60 % | ~45 mA | 10 s shows, 30 a day: **~4 weeks** · continuous: ~2 h |
| same, backlight dimmed to ~10 % | ~30 mA | continuous: ~3 h |
| 0.96″ SSD1306 OLED (power depends on lit pixels) | ~35–40 mA | continuous: ~2.7 h |
| e-paper (holds its image with no power) | 30 mA for ~3 s per update | updates every 30 min: **months** |

How to use a colour TFT well:

* **Show, dim, off.** Full brightness for a few seconds after a press, then
  ~10 %, then switch the board off (the `charge_gauge` example does this).
* **Keep backgrounds dark.** On a TFT this doesn't change the backlight's
  power, but a dim backlight looks fine with a dark UI. On an OLED dark
  pixels are free.
* **Redraw only what changes**, at 15–20 fps for animations. The RP2040
  sends frames over SPI with DMA, so this is easy.
* **E-ink for anything that should stay visible**, such as a tarot oracle that
  shows the card you drew: the image costs nothing to keep, so the board
  switches fully off after each refresh. A black/white 1.54″ refresh takes
  ~2 s (about 0.6 J per draw including start-up, ~600 draws on one 120 F
  capacitor); three-colour panels take ~14 s. See the
  [oracle example](../firmware/trinketcore/circuitpython/oracle/code.py).
* **Always-visible colour** (a pet that's always showing): use a colour e-paper
  or a memory-in-pixel LCD (JDI LPM013M126A, 8 colours). A memory LCD needs
  a microcontroller that sleeps at a few µA, such as an nRF52 or STM32L0,
  which is a different board. On TrinketCore, use e-paper for always-visible
  screens and TFT/OLED for glance-and-go screens.

## The music box

The most logical design for a music box with LEDs and quick bursts of sound:

1. **Lid opens → board wakes.** A lid switch on `WAKE`, with a 1 µF capacitor
   in series and 22 MΩ across it, sends one wake pulse. The board can still
   switch itself off if the lid is left open. A button works too.
2. **Play one short piece (15–30 s)**, then switch everything off. Closing
   and reopening the lid plays it again.
3. **Synthesise the sound** instead of decoding MP3s. A plucked, bell-like
   note is a sine wave plus two overtones with a fast attack and a ~1 s decay.
   That takes almost no memory or CPU (`synthio` in CircuitPython). Short
   recorded sounds are fine too: 16 MB of flash holds several minutes of
   22 kHz audio.
4. **Moderate volume, efficient speaker.** A 28–40 mm, 8 Ω speaker in a small
   resonant box (the music box itself) is loud at a fraction of a watt. Half
   the volume uses a quarter of the power.
5. **LEDs that pulse on each note** and fade in between, at a few mA each
   through 470 Ω–1 kΩ resistors on GP2–GP5. The eye sees the pulses, the
   capacitor barely notices them.
6. **Check the charge first.** If it's low, play a short falling "charge me"
   chirp instead of the tune and switch off.

Budget: RP2040 ~25 mA, amplifier ~15–40 mA at moderate volume, LEDs ~5–10 mA.
That's roughly 70 mA for 20 s, or **~5.5 J per play**.

| Capacitors | Plays per charge | At 10 plays a day | Charge time (300 mA) |
|---|---|---|---|
| 1 × 120 F (12.5 × 25 mm) | ~75 | ~1 week | ~9 min |
| 1 × 220 F (16 × 25 mm) | ~140 | ~2 weeks | ~16 min |
| 2 × 220 F | ~275 | **~4 weeks** | ~32 min |

To stretch it further:

* **Shorter pieces:** 10 s instead of 20 s doubles the plays.
* **Lower volume.**
* **A slower CPU:** CircuitPython keeps the RP2040 at 125 MHz. An Arduino or
  C sketch at 48 MHz saves ~15 mA.
* **Skip the display**, or show only a 1 s charge icon.

## The same method for the other trinkets

| Trinket | Wake source | Burst | Display | Two 220 F capacitors |
|---|---|---|---|---|
| **Music box** | lid (one-shot) or button | 15–30 s tune + LEDs | none, or 1 s charge icon | ~4 weeks at 10 plays/day |
| **Keychain game** | button A | play session, auto-off after 60 s idle | OLED or colour TFT | 2–3 h of play per charge |
| **Virtual pet** | clock timer (every 15–60 min) + buttons | update state, redraw, off | e-paper: always visible | months (e-paper) · weeks (TFT, only on button press) |
| **Keychain animation / charm** | button or vibration switch on `WAKE` | 5–10 s animation | round GC9A01 colour TFT | ~4 weeks at 30 shows/day |
| **Tarot oracle** | button A, or a shake (vibration switch on `WAKE`) | draw a card: one e-ink refresh, then off | e-paper: the card stays with no power | ~2,200 draws per charge |
| **Badge / photo frame** | clock alarm (daily or hourly) | e-paper refresh | e-paper | months |
| **Desk clock** | clock timer every 1–5 minutes | redraw the time | e-paper (partial refresh) | ~9 days (every minute) · ~6 weeks (every 5 min) |

The rule of thumb stays the same as in the [energy budget](energy-budget.md):
if it sleeps between uses it lasts days to weeks; if it runs continuously,
budget in minutes to hours.

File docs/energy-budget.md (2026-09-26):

# Energy budget: what a capacitor can actually run

Supercapacitors trade energy for safety, lifetime and charging speed.
Before designing a gadget, check that its power draw fits.

## The one formula that matters

A capacitor's voltage falls steadily as it empties, and the electronics stop
at the cut-off voltage. So only the energy between the charge voltage and the
cut-off is usable:

```
E_usable = ½ · C · (V_charge² − V_cutoff²)
```

On CapCore that is 3.71 V → 2.61 V for a lithium-ion capacitor (LIC):
**3.5 J per farad**. For an ordinary 2.7 V supercapacitor (EDLC) it is
2.62 V → 1.96 V: **1.5 J per farad**. The 3.3 V converter is about 85 %
efficient, so:

```
runtime = E_usable × 0.85 / (load current × 3.3 V)
```

For scale: a 30 F LIC (10 × 16 mm) holds **29 mWh**, and the biggest
common one (220 F, 16 × 25 mm) holds **212 mWh**. A tiny 100 mAh LiPo holds
about 370 mWh. Capacitors hold much less energy, but they charge in minutes,
survive tens of thousands of cycles, and are far less of a fire risk than a LiPo
(an ordinary EDLC essentially none).

## Runtime per charge

From [`tools/energy_calc.py`](../tools/energy_calc.py) (85 % efficiency, 5 µA
standby). Charge times are for CapCore's 300 mA charger, from the cut-off to full.

| Gadget | LIC 30 F<br>10×16 mm | LIC 120 F<br>12.5×25 mm | LIC 220 F<br>16×25 mm | EDLC 10 F<br>10×20 mm | EDLC 100 F<br>22×45 mm |
|---|---|---|---|---|---|
| Usable energy | 104 J (29 mWh) | 417 J (116 mWh) | 765 J (212 mWh) | 15 J (4 mWh) | 151 J (42 mWh) |
| Charge time | ~2 min | ~9 min | ~16 min | <1 min | ~4 min |
| LED earrings (~0.8 mA average) | 9.3 h | 37 h | 3 days | 81 min | 13.5 h |
| E-ink badge, RP2040, 1 refresh/day | 71 days* | 282 days* | 518 days* | 13 days | 126 days* |
| E-ink dashboard, RP2040, 1 refresh/hour | 11 days | 44 days* | 80 days* | 39 h | 16 days |
| E-ink, nRF52 + partial refresh, hourly | 40 days | 159 days* | 292 days* | 6 days | 65 days* |
| Game: Sharp memory LCD + low-power MCU (12 mA) | 37 min | 2.5 h | 4.6 h | 5 min | 54 min |
| Game: 0.96″ OLED + RP2040 (35 mA) | 13 min | 51 min | 1.6 h | 2 min | 19 min |
| Game: 1.3″ colour TFT + backlight + RP2040 (50 mA) | 9 min | 36 min | 66 min | 78 s | 13 min |
| Chiptune synth on a small speaker (15 mA) | 30 min | 2 h | 3.6 h | 4 min | 43 min |
| MP3 player to headphones (70 mA) | 6 min | 26 min | 47 min | 56 s | 9 min |
| MP3 player to a small speaker (120 mA) | 4 min | 15 min | 27 min | 32 s | 5 min |

\* Beyond a month or two, the capacitor's own self-discharge takes over
(it isn't in the model), especially for EDLCs. Treat these as best cases and
recharge now and then.

## What that means for your ideas

* **LED jewellery, badges, blinky art: great fit.** Hours to days per charge,
  a one-minute top-up, thousands of cycles. This is what the Fibonacci
  earrings do.
* **E-ink displays: great fit** *if the whole board powers off between
  updates.* E-ink holds its image with no power. Let CapCore's RTC wake the
  gadget, update, and switch everything off again: weeks to months per charge.
* **Handheld games: OK for short sessions.** 15–90 minutes with a 120–220 F
  LIC, then a 10–15 minute charge. Memory-LCD or monochrome OLED games with a
  slow CPU stretch the most.
* **Music players: poor fit.** Audio amplifiers and SD cards draw tens to
  hundreds of mA, so even the largest LIC gives well under an hour. Use
  headphones, keep the volume low, or make a chiptune synth with a piezo
  instead of an MP3 player. For long listening, a supercapacitor is the wrong
  storage.

For colour TFT screens, the music box and the same pattern for every other
trinket, see [the burst method](trinket-design-method.md).

## Try your own numbers

```
python3 tools/energy_calc.py                                   # all presets
python3 tools/energy_calc.py --cap lic:120                     # one capacitor
python3 tools/energy_calc.py --cap lic:50 --ma 25              # 25 mA continuous
python3 tools/energy_calc.py --cap lic:30 --active-ma 40 --active-s 3 --per-day 24
```

Measure your real current with a USB power meter or a multimeter in series
with the 3V3 line. Datasheet "typical" figures are usually optimistic.

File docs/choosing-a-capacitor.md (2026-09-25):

# Choosing a capacitor

CapCore works with two kinds of capacitor. **Decide before you order boards:**
the choice sets two resistors (R4 and R13) at assembly time.

| | Lithium-ion capacitor (LIC) | Supercapacitor (EDLC) |
|---|---|---|
| Voltage window on CapCore | 3.71 V → 2.61 V | 2.62 V → 1.96 V |
| Usable energy per farad | 3.5 J | 1.5 J |
| Capacitance for a given size | high (10×20 mm ≈ 50 F) | low (10×20 mm ≈ 10 F) |
| **Energy for a given size** | **~10× more** | baseline |
| Cycle life | tens of thousands of cycles | hundreds of thousands+ |
| Self-discharge | low | higher (days to weeks to lose a noticeable share) |
| Discharge to 0 V? | **no**: damaged below ~2.2 V | yes, harmless |
| Chemistry | lithium-doped carbon, organic electrolyte | carbon, organic electrolyte, no lithium |
| Fire risk | far below a LiPo, but not zero if abused | negligible |
| Build variant | LIC (R4 120k, R13 330k) | EDLC (R4 75k, R13 470k) |

**Pick an LIC** for almost everything: games, e-ink, anything where runtime
matters. It is what the Fibonacci earrings use (a 40 F, 3.8 V LIC). **Pick an
EDLC** when you want the most inert part available and a few minutes of
runtime is enough.

## Lithium-ion capacitors (3.8 V)

Eaton's HS series is easy to buy one at a time from the big distributors.
Any 3.8 V lithium-ion capacitor works.

| Part | Capacitance | Size (dia × length) | Lead pitch | Usable energy on CapCore | Notes |
|---|---|---|---|---|---|
| HS0814-3R8106-R | 10 F | 8 × 14 mm | 3.5 mm | 35 J | higher internal resistance; keep loads under ~100 mA |
| HS1016-3R8306-R | 30 F | 10 × 16 mm | 5.0 mm | 104 J | good all-rounder for small gadgets |
| HS1020-3R8506-R | 50 F | 10 × 20 mm | 5.0 mm | 174 J | |
| HS1225-3R8127-R | 120 F | 12.5 × 25 mm | 5.0 mm | 417 J | games, e-ink dashboards |
| HS1625-3R8227-R | 220 F | 16 × 25 mm | 7.5 mm (bend leads or wire) | 765 J | largest practical size |

Search [DigiKey](https://www.digikey.com/en/products/result?keywords=Eaton%20HS%203R8)
or [Mouser](https://www.mouser.com/c/?q=Eaton%20HS%203R8) for the part
number. Single pieces cost a few dollars for the small sizes and more for the
large ones, so check current prices. Always read the datasheet of the exact
part you buy.

**Rules for LICs:**

* Keep them between their minimum and 3.8 V. Eaton treats **2.2 V as the
  absolute minimum**. Below that the cell is damaged and can vent. CapCore
  charges to 3.71 V and disconnects at 2.61 V, which leaves room for
  self-discharge while the gadget sits unused.
* **Never charge one with a LiPo charger.** LiPo chargers go to 4.2 V, far
  over the 3.8 V rating.
* A dead-flat gadget still slowly loses charge. **Recharge it within a month
  or two**, and use ship mode before long storage.
* Don't short, crush, puncture or overheat it. A large LIC delivers tens of
  amps into a short.

## Supercapacitors (EDLC, 2.7 V)

Ordinary 2.7 V (or 3.0 V) supercapacitors from any reputable maker work on the
EDLC build: Eaton, Kyocera AVX, Tecate, Vinatech, Samwha and others. The
larger sizes (tens of farads and up) come in 16–22 mm diameter cans.

**Rules for EDLCs:**

* **Never fit an EDLC to a board built with the LIC values.** It would be
  charged to 3.71 V and can vent. Measure the charge voltage at BT1 before
  soldering in the capacitor (see the board's bring-up steps).
* Polarity matters: reversed, it is damaged. The **square pad is +**.
* Don't put two in series on CapCore. Series stacks need balancing, which the
  board doesn't provide.

## Physical fit

BT1 has two footprints in one: **5.0 mm** lead pitch (10–12.5 mm cans) and
**3.5 mm** (8 mm cans). The square pads are **+**. The can can stand upright,
lie flat over the board (the sleeve is insulated; add a strip of Kapton tape
over the parts to be safe), or be folded flat past the bottom edge. Glue or
strap large cans so the leads don't take mechanical stress. For 16 mm and
larger cans, or a capacitor elsewhere in your enclosure, run two short, thick
wires to the pads.

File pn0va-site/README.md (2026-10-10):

# pn0va.com — 2026 build

Rev **2026.08.02**. Four builds — two variants x two URL styles:

| Folder | URLs | |
|---|---|---|
| `with-store/` | `/drops.html` | Flat. Double-click previewable. |
| `with-store-clean/` | **`/drops`** | Folder-per-page. **Must be served.** Upload this one. |
| `no-store/` | `/drops.html` | Same, store removed everywhere |
| `no-store-clean/` | **`/drops`** | Same, store removed everywhere |

### Which one goes on the server

**`*-clean`.** Each page becomes its own folder with an `index.html` inside, so
`pn0va.com/drops` serves `drops/index.html`. That means pages sit one level
deep, so every asset path is **root-relative** (`/style.css`, `/images/...`) —
which is exactly why opening one by double-clicking shows an unstyled page:
`/style.css` resolves to your drive root. To see it on your computer before
uploading, double-click `PREVIEW.cmd` (see *Local preview*).

A `.htaccess` ships with each clean build. It strips trailing slashes, maps
bare paths to their `index.html`, and 301s every old URL — including
`geocache.html` → `/drops`, since that page was renamed, not just re-pathed.

Both are generated by `build.py` from one source, so they cannot drift apart.
**Edit the build script, not the output folders** — re-running wipes and
regenerates both.

```bash
python build.py
```

It needs two things, and finds both on its own:

| | Where |
|---|---|
| The 2026-07-06 build it derives from | `_source/website-fixed/` (bundled here) |
| The brand kit | `Desktop\PN0VA` — the sibling folder. If it isn't there, the snapshot in `_source/brand-kit/` is used |

Change anything in `PN0VA` and re-run; both variants pick it up. The source is
bundled rather than referenced so this folder stays self-contained and the
script keeps working years from now.

### The server

The `.htaccess` needs Apache or LiteSpeed with `AllowOverride All`, the usual
shared-hosting setup. It turns off Apache's own trailing-slash redirect
(`DirectorySlash Off`): the pages are folders served at URLs without a slash,
and the two rules redirected each other forever.

**Turn on HTTPS.** Once `https://pn0va.com` opens with a padlock, use the host's
*Force HTTPS* switch, or uncomment the three lines under `# HTTPS.` near the top
of `.htaccess` (and the `Strict-Transport-Security` line). It ships switched off
only because forcing HTTPS on a site with no certificate takes the site down.

### The Drops map

The street map is **served by the site itself**. Carto began answering
keyless requests with "API key required" tiles, which blanked the map; the
site no longer asks Carto (or anyone else) for anything.

- `maps/drops.pmtiles` holds OpenStreetMap streets, water, parks, buildings
  and names around the drop zones: close-up detail within 4 km of each zone
  and a wider view 30 km out. One file, read in small pieces, so a visitor
  downloads only what they look at. A zone's page shows it as a street map,
  and the globe draws the same streets once it comes in close to a zone.
- `drops-map.js` paints it in the site palette with protomaps-leaflet
  (`vendor/protomaps-leaflet/`, BSD licence), inside the same Leaflet map, so
  the rings, marker, graticule and recenter button are unchanged. The
  streets are red, so the grid, the scale and the landmarks read at a
  glance: highways in the brand red, main roads a shade darker, side
  streets darker again and lanes and paths darkest. Railways are taupe,
  buildings taupe on slate ground, parks a dark olive, water near black,
  and the names bone and linen. The zone is a bone diamond with a red glow,
  inside bone rings at 50, 100 and 250 m; zoomed out, a ring's label gives
  way where it has no room.
- No key, no usage limits, no account. The data is © OpenStreetMap
  contributors (ODbL); the attribution on the map is required and in place.

**The map in this folder** was made 2026-09-28 from OpenStreetMap data of
2026-09-27: 10.8 MB, covering the three San Francisco drop zones. A visitor
who looks at all three downloads about 200 KB of it.

**One map file serves every drop zone, and a new zone gets its map by
itself.** Add the zone to `drops.html` and run `python build.py`. If it is
more than about 3 km from every zone the map was made for, the build first
fetches the area around each zone from the newest daily world map
published by Protomaps (build.protomaps.com), then builds. Each zone gets
its own area, so zones in two cities cost two small areas, not everything
between them. A test zone in Mesa, Arizona added 6 MB to the map and under
30 seconds to the build. A new drop at a zone you already have needs no
map at all. Upload the new `maps/drops.pmtiles` along with the rest of the
folder.

The build needs two Python packages for that, installed once:

```bash
pip install pmtiles requests
```

Without them, or offline, the build carries on with the map it has and names
the zones it doesn't cover; the page shows those on plain ground, and the
globe stops at 64x over them. With no map file at all, it shows the rings
and marker on plain ground plus a link to the location on OpenStreetMap, not
error tiles. `python tools/make-map.py` remakes the map on demand, for
instance to pick up newer streets.

**The server must send parts of files** (HTTP "range requests"). Apache,
LiteSpeed, Netlify, GitHub Pages and Cloudflare all do, and so does the
preview (see *Local preview*). Python's `http.server` does not, and a page
opened by double-clicking cannot read a file in parts at all: both show the
rings on plain ground instead of streets.

### The Drops page: the world, then a drop zone

Drops are left at **drop zones**: places the operator comes back to, with
any number of drops left at each over time. Every drop is in plain sight,
marked with a P_N0VA sticker, and its page shows photos of the spot, so
there are no hints. The Drops page is one page with two screens.

- **The world** (`pn0va.com/drops`): the list of drop zones, each with its
  number and name, when its latest drop was left, how many drops have been
  left there and the latest one's title and first line, and a globe with a
  mark for each. It opens with no zone chosen, the globe turned to where
  the zones are.
  - **Choose a zone in the list** (a click, Enter, or the arrow keys down
    it) and the globe turns to it, the zone in the middle, at the zoom you
    are at: from far off it flies out and back down to that zoom.
  - **Click a zone on the globe** and the globe stays where it is.
  - Either way a prompt opens beside it: how many drops, when the latest
    was left and how long ago, where the zone is, the latest drop's
    number, title and item and the first line of its story, **ZOOM IN** (or
    **ZOOM OUT**, once the globe is as close as it goes), the one thing that
    zooms to a zone, and **OPEN ZONE**. ZOOM IN flies all the way down to
    street level, the scale the zone's own street map opens at. Its ×, Esc
    or a click on bare globe closes the prompt.
  - **OPEN ZONE** is the only way in: the globe dives, flashes, and the
    zone's windows fly in. Pointing at a row only marks its zone on the
    globe, and a double-click on a zone opens nothing.
  - On a phone the globe is too small to carry the prompt, so the chosen
    zone's row opens up underneath instead, with the same (but for where
    it is, which its page shows) and its two buttons the width of the list.
    A second tap on the row closes it.
- **A drop zone** (`pn0va.com/drops#03`): its name, large, under its number
  (ZONE 03 over TELEGRAPH HILL), its coordinates, when its latest drop was
  left and how many there are; its street map, at street level; and along
  the bottom, **the drops left there**, newest first, each with its number,
  title and date, and NEW or CLAIMED. Beside the list, everything about the
  drop chosen in it: **Spot**, the photos of where it was left;
  **Transmission**, its story; and **Item**, the photo of what was left. It
  opens on the newest drop. Choose another in the list (a click, or the
  arrow keys up and down it) and its photos and story show in place.
  **WORLD MAP**, solid red at the head of the top bar, the globe button on
  the street map, Esc, or the browser's Back pulls back out to the globe,
  where that zone is still chosen. On a phone the page scrolls: the street
  map takes half the screen, then the drops, the spot, the chosen one's
  story in full and its item, and WORLD MAP floats at the foot of the
  screen, always in reach.

**The spot's photos.** Each shows its file's name and the date in it, and
the window's head counts them (1/3). The arrows on the photo and a swipe
across it go through them, earliest first and round again from the last,
and so do the left and right arrow keys once the photo or an arrow has the
focus (Tab to it, or click an arrow). A click on the photo opens it full
size. A drop with one photo shows its date in the head instead of a count;
one with none says it has no photo of the spot yet.

**"What is a drop?"**, the small ? in the corner of the top bar, says what
a drop is and what a zone's page shows, for whoever wonders.

On a phone held sideways the list sits beside the globe, as on a desktop,
and a zone's windows sit two by two: the drops beside the spot, the story
beside the item. On any screen too short for a zone's page to fit (under
560px tall), the page scrolls rather than squeezing the street map, and
WORLD MAP floats at its foot there too.

Every zone and every drop has its own address. `pn0va.com/drops#03` opens
on zone 03 and its newest drop; `pn0va.com/drops#003` opens on drop 003, at
the zone it was left at. Choosing a drop on a zone's page puts its address
in the address bar, without adding a step to Back, so a link copied from
there opens on that drop. Back, reload and sharing all work. A zone is
marked **NEW** while its latest drop is in its first week (in the list, in
its prompt, and red on the globe), and that drop is marked NEW in the
zone's own list.

The globe is drawn in the brand palette from `tokens.css`: ember sea, slate
land with built-up areas a shade lighter, ember lakes and rivers, roads in
red (highways brightest), country borders in bone over a dark edge
(thickening as you come in), dashed taupe state lines, ash coasts, a linen
sheen and names, red for the instruments (graticule, rim, pointer, NEW) and
bone for the zone you are on.

It is a map: coast, lakes, rivers, the built-up areas of cities, highways
and main roads, country borders, state and province lines, and the names of
countries, states, cities, peaks and landmarks, each named once there is
room for it. It zooms with its **+** and **−** buttons, the mouse wheel, a
pinch, or the + − 0 keys, from the whole globe down to a city (64 times
closer) anywhere, and near a drop zone on down to street level: within
4 km of a zone as close as its street map opens, and within 30 km close
enough to see its main streets. There the globe draws the street map's own
streets, parks, water and neighbourhood names, so the way down from the
whole Earth to the zone's corner never cuts to another map. The coastline
is redrawn finer as you come in, so its shape holds and only sharpens, and
the grid of latitude and longitude grows finer with it, down to a
thousandth of a degree. The globe button below the zoom buttons goes back
to the whole globe.

Every drop zone has its own mark, which grows as you zoom in. Zones too
close together to tell apart, like the three in San Francisco, sit on a
small ring around the spot they share, each on a thread back to it, in the
order they really lie (Alcatraz on top); zoom in and they move apart onto
their own spots. Point at anything for what it is: a zone's number, name,
how many drops and when the latest was left, and that drop's title, item
and the start of its story; a city's state or country, a peak's height, a
landmark's note. On a touch screen, tap it. Close in, a landmark's name goes
ahead of the city it stands in (at 64x the Colosseum shows over Rome), but
every name gives way to the zones and the prompt, so the landmarks right
beside a zone, like most of San Francisco's, wait until you come in close
enough to give them room. A zone whose drops are all claimed is drawn
hollow.

Its files:

- `drops-world.js`, from `_source/world/`;
- `vendor/world/`: d3-geo, d3-array and topojson-client (ISC licence), about
  60 KB;
- `maps/world/`: the map, from Natural Earth (public domain), at four levels
  of detail, the closer three with rivers, built-up areas and roads. The
  whole globe is one file of 305 KB (109 KB as the `.htaccess` compresses
  it), and the next level, read while the page is idle, one of 1.1 MB
  (390 KB); closer in, the page fetches only the part in view. 22.6 MB in
  308 files. A visitor who zooms all the way in on a zone downloads about
  750 KB of it, compressed (650 KB on a phone), and 250 to 420 KB of the
  street map. `tools/make-world/` made it, and only needs running again for
  newer borders or roads (see the top of `make-world.mjs`);
- `maps/landmarks.json`, from `_source/world/landmarks.json`: 148 landmarks
  around the world, each a name, a position, the zoom it appears from (1 is
  the whole globe, 64 the closest away from the zones) and the note shown
  when pointed at. Add your own the same way and rebuild. At 64x the globe
  shows about 300 m to a pixel, so two landmarks a few streets apart can't
  both show: one a city is plenty.

With reduced motion on, the screens change without the dive or the flights.
With JavaScript off, the world view stays hidden and the page is the zone
frame it always was.

### Adding a drop, or a drop zone

Everything is in `drops.html`, in the brand kit's `drops` folder (or the
snapshot in `_source/brand-kit/drops/`); the comment at its top says the
same. Each zone is a `<section class="dp-zone">`, and the drops left there
are the `<article class="dp-entry">` blocks inside it, newest first. Zones
go newest first too. (A `dp-point` section, from before zones, still
works.)

```html
<section class="dp-zone" data-n="03" data-place="Telegraph Hill"
         data-lat="37.802139" data-lng="-122.4058" data-zoom="17">

  <article class="dp-entry" data-n="004" data-placed="2026.10.12"
           data-title="Back on the Stairs"
           data-item="images/item-004.jpg" data-itemcap="Patch, red on black">
    <p>Its story, a paragraph or two.</p>
  </article>

  <article class="dp-entry" data-n="003" data-placed="2026.07.20" ...>
    ...
  </article>

</section>
```

- **A new drop at a zone you have:** copy an `<article>` into the zone's
  `<section>`, above the drops already there. `data-n` is the drop's number,
  three digits, one count across all the zones; `data-placed` the date;
  `data-title` its name; `data-item` the photo of the item and
  `data-itemcap` its caption. Then write its story.
- **A new zone:** copy a whole `<section>` to the top, with one drop in it.
  `data-n` is the zone's number, two digits; `data-place` its name, which
  heads its page; `data-lat` and `data-lng` where it is, in decimal
  degrees; `data-zoom` how close its street map opens: 17 is street level,
  15 or 16 shows more of the neighbourhood. Either way the map zooms from 8
  out to 19 in.
- **Photos of the spot:** put them in the same `drops/images/` folder,
  named `item`, the drop's number, `_` and the date as MMDDYY:
  `item4_092326.jpg` is drop 004's spot on 2026.09.23. A second photo the
  same day takes a letter after the date (`item4_092326b.jpg`). The build
  finds them and puts them in date order; the page shows each one's name
  and date. JPEG, PNG, WebP, GIF or SVG; about 1600 pixels on the long side
  is plenty. To choose the photos and their order yourself, list them in
  the drop's `data-photos`, separated by spaces
  (`data-photos="images/a.jpg images/b.jpg"`, so no spaces in the names);
  the build leaves that alone.
- **The item photo:** put it in the same folder (JPEG, PNG, WebP, GIF or
  SVG; about 1200 pixels wide is plenty) and name it in `data-item`.

Then run `python build.py`. For a zone in a new place it fetches the street
map first (see *The Drops map*). Nothing else needs touching: the globe, the
lists, the prompts and the zone's page all read these blocks.

### Marking a drop claimed

A drop shows no status unless you give it one. Once you know a drop has been
found, add `data-claimed` with the date to its `<article>` in `drops.html`:

```html
<article class="dp-entry" data-n="001" data-placed="2026.06.15" data-claimed="2026.06.28" ...>
```

and run `python build.py`. On its zone's page the drop is then tagged
**CLAIMED** in the list of drops, in place of NEW, and the head of its item
window says **CLAIMED** with the date (just **CLAIMED** where the window is
too narrow for both). The photos are left alone, so later visitors still
see what was left there. Once every drop at a zone is claimed, the zone
says **CLAIMED** in the world list and in its prompt, and turns hollow on
the globe. `data-claimed` without a date shows **CLAIMED** alone; deleting
it undoes it. Nothing ever says "unclaimed".

Drop 001's story says it was recovered on 2026.06.28, but it is not marked:
add `data-claimed="2026.06.28"` to it if it should show.

## 2026.10.10 update

- **Drop zones.** Drop points are now drop zones, everywhere: the list, the
  prompt's **OPEN ZONE**, the zone's page and its title. Addresses are
  unchanged (`drops#03` for a zone, `drops#003` for a drop).
- **The zone's name heads its page**, large, under its number: ZONE 03
  over TELEGRAPH HILL. "What is a drop?" is rewritten and quieter, a small
  ? in the corner of the top bar.
- **Photos of the spot.** The sticker window is gone. Each drop has a Spot
  window with photos of where it was left, which the build picks up from
  `drops/images/` by their names (`item3_092326.jpg`: drop 003,
  2026.09.23). Arrows, the arrow keys and a swipe go through them; each
  shows its file's name and date. Choosing a drop in the list shows
  everything about it beside the list: Spot, Transmission (narrower now)
  and Item.
- **The street map opens at street level** (zoom 17, from 14 and 15), and
  zooms two steps closer or all the way out to the region. Its streets are
  red, brighter and wider the bigger the road, so the scale and the
  landmarks read at a glance; buildings taupe, parks olive, names bone.
  Its rings are at 50, 100 and 250 m (from 100, 250 and 500), and their
  labels no longer overlap: zoomed out, the inner ones give way.
- **The globe goes down to street level near a zone.** Anywhere else it
  still stops at 64x; within 4 km of a zone it comes on in to the scale
  the zone's street map opens at, and ZOOM IN takes it there, so the globe
  hands over where the street map begins. Close in, it draws the street
  map's own streets, parks, water and neighbourhood names.
- **More on the globe close in:** rivers, cities' built-up areas, highways
  and main roads from Natural Earth, coming in from about 3x; borders in
  bone; and the latitude and longitude grid down to a thousandth of a
  degree. The world map grew from 10.4 to 22.6 MB on the server; what a
  visitor downloads is above.
- **Stronger cursors.** OPEN ZONE has a solid red wedge that steps toward
  what it opens, and WORLD MAP a solid black one pointing back, stepping
  that way when pointed at.

## 2026.10.09 update 3

- **Drop points.** Drops are now left at drop points, places the operator
  comes back to. The world lists the points and the globe shows one mark
  for each. A point's page lists every drop left there, newest first, with
  its number, title, date and NEW or CLAIMED, and shows the chosen one's
  story and item photo. The three drops so far are at three points, one
  each: 03 Telegraph Hill, 02 Island Signal and 01 West Woods.
- **No hints.** Every drop is in plain sight, marked with a P_N0VA sticker.
  The hint photo is gone; a point's page shows the sticker to look for
  instead, and "What is a drop?" says so.
- **Addresses.** `drops#03` is point 03; `drops#003` is drop 003, opened at
  its point, so links to drops from before still work.
- **OPEN POINT** replaces OPEN DROP. The list and the prompt say how many
  drops a point has, when the latest was left, and its title.
- **Item photos in any web format.** The build used to copy only SVG files
  from `drops/images/`; it now copies JPEG, PNG, WebP and GIF photos too.

## 2026.10.09 update 2

- **The list no longer zooms.** Choosing a drop in the list turns the globe
  to it, the drop in the middle, at the zoom you are at: on the whole globe
  it stays the whole globe, and close in it stays close in, flying out and
  back down when the next drop is far away. The prompt's ZOOM IN is what
  takes you close. Choosing a drop on the globe and then another in the
  list no longer pulls you all the way in.

## 2026.10.09 update

- **No drop is chosen when the page opens.** The world opens on the whole
  globe, turned to where the drops are, with no prompt and no row lit.
  Coming back from a drop's page, that drop is still chosen.
- **The list flies to a drop; the globe shows one where it is.** Choosing
  a drop in the list now flies the globe to it: out and across when it is
  far, then down as close as the globe goes (64x), the drop in the middle.
  The way is van Wijk and Nuij's smooth zoom and pan, the one d3 uses, so
  the drop never leaves the screen; it takes half a second to a second
  and a half, by the distance. A click on a drop's point chooses it without moving the globe.
- **ZOOM IN and ZOOM OUT in the prompt.** Beside OPEN DROP: ZOOM IN flies to
  the drop; once there it reads ZOOM OUT and goes back to the whole globe,
  still on the drop. The globe button and the 0 key fly back out the same
  way, a little quicker than flying in.
- **The prompt closes.** Its ×, Esc, or a click on bare globe closes it; on
  a phone, a second tap on the open row.
- **WORLD MAP stands out.** On a drop's page it is solid red with black
  letters (as NEW is), larger, with a back arrow. Where the page scrolls
  (phones, and any screen under 560px tall) it floats at the foot of the
  screen instead of scrolling away with the top bar.
- **Smooth flights on slower phones too.** Close in, two things made each
  frame costly: the globe's light and sheen, a curve spread over a globe
  many times the screen and all but flat there, which now fade out as the
  globe comes in; and the drops' glowing points, now drawn once and
  stamped. Map files that arrive mid-flight are read once the globe is
  still, and the second level of detail is read while the page is idle
  (250 KB as served; asked to save data, or on a slow connection, only
  once the world is pointed at or touched). With the processor slowed
  four times, as on a modest phone, a flight in went from about 6 frames a
  second to about 10 the first time and 15 after; at full speed it runs at
  about 45.

## 2026.10.07 update 2

- **One OPEN DROP.** The bar under the globe, with its second OPEN DROP, is
  gone. On a desktop the prompt by the chosen drop is the way in; on a
  phone, the chosen drop's row.
- **More about each drop, wherever it shows.** The prompt now gives the
  drop's title, when it was placed and how long ago, its coordinates, its
  item and hint, and the first line of its story, above OPEN DROP. Pointing
  at another drop's point shows the same but for where it is and the hint.
  Each row of the list has the title and the first line of the story under
  the name. All of it comes from the drop's record (see *The Drops page*).
  The mouse wheel over the prompt zooms the globe, as it does everywhere
  else on it.
- **Phones, the world.** The prompt no longer covers the small globe: the
  chosen drop's row opens underneath with its details and an OPEN DROP the
  width of the list and 44px tall, and the list scrolls to keep it in view.
  The other rows keep one line of their story. The help line above the list
  is left out; the opened row says what to do. A double tap on a row no
  longer opens the drop: as a row opens the rows round it move, and its
  OPEN DROP could come to rest under the finger for the second tap.
- **Phones, a drop.** The page scrolls. Held to one screen, it left out the
  hint and item photos on every phone under 680px tall (an iPhone in Safari
  among them) and kept the brief to two lines in a box. Now the street map
  takes half the screen, the two photos sit side by side under it, and the
  brief reads in full, in larger type.
- **Phones on their side.** The list and the globe sit side by side, as on
  a desktop, instead of a globe 120px tall over a list too short for a row
  to open in; a drop's photos flank its brief. On a screen wider than a
  phone but short (a large phone on its side, a laptop window halved), a
  drop's page scrolls rather than squeezing its street map: at 932x430 the
  map was 52px tall, and is now 280px.

**Fixed**
- On a short phone, a drop's brief took half the width, beside an empty
  space where the photos had been.

## 2026.10.07 update

- **A drop opens with its OPEN DROP button, and nothing else.** Choosing a
  drop in the list or on the globe turns the globe to it and opens a prompt
  beside it with its name, date and **OPEN DROP**; that button, or the one
  under the globe, opens it. A click on a row, a second click or a
  double-click on a point no longer opens the drop. Pointing at a row marks
  its point without swinging the globe round; a click turns it. From the
  keyboard: the arrows down the list, Enter to reach the prompt's button,
  Enter again to open.
- **A drop's page shows that drop only.** Its list of the other drops, and
  the arrow keys that stepped through them, are gone; the record takes the
  full width. WORLD MAP heads its top bar (40px tall on a phone); the globe
  button on the street map, Esc and Back still go back.
- **Screen changes are quicker, and their after-images always show.**
  Opening a drop took about 2.5 seconds and going back about 2.2; now about
  1.5 and 1.3. The windows fly the About page's flight at twice its speed,
  from nearer the edge. Their after-images were drawn by a timer while they
  flew, and the street map drawing its tiles held that timer up: with the
  processor slowed four times, as on a modest laptop, a drop opened with 10
  after-images across all its windows instead of 70 or more. Each window's
  after-images are now set out the moment it takes off and fade on their
  own, so they always show. About, Blog, Projects and Store use the same
  code and look as they did.
- **Stronger borders, more landmarks.** Country borders are thicker and
  brighter, over a dark edge, and state and province lines clearer. Some
  were missing close in (California-Nevada, Arizona-California,
  Washington-Idaho and 21 more US lines, Quebec-Ontario and others), because
  Natural Earth files them as "statistical" boundaries; the map includes
  them now. 85 landmarks added, 148 in all, each checked against Natural
  Earth's outlines to lie in its country: from Badwater Basin, Delicate Arch
  and Devils Tower to the Nazca Lines, the Alhambra, Meteora, Abu Simbel, the
  Terracotta Army, Ha Long Bay, Borobudur and Milford Sound.
- **+ zooms where you are looking.** It zooms about the chosen drop only
  while the globe still points at it; dragged off to Europe, + goes into
  Europe rather than back toward the drop at the edge of the globe.

**Fixed**
- On a phone, a claimed drop's item window title squeezed its photo tag
  (IMG-B) onto two lines.

## 2026.10.04 update

- **The globe zooms properly, and it is a real map.** Zooming used to enlarge
  one coarse outline: the drop points stayed the same size and the coast
  changed shape as it grew. Now the coastline is redrawn finer at every step
  (Natural Earth's 1:10m), so it only sharpens, and the points grow. It zooms
  to a city (64x, up from 16x) and shows country borders, state and province
  lines, lakes, and the names of countries, states, cities, peaks and 62
  landmarks as there is room for them (see *The Drops page*).
- **Point at anything on the globe for what it is**: a drop's number, name and
  date; a city's state or country; a peak's height; a landmark's note. Tap it
  on a phone.
- **The drop screen's list shows each drop's name**, as the world list does,
  not just its date.
- **Claimed, when you say so**: `data-claimed="YYYY.MM.DD"` on a drop marks it
  claimed on its page, in both lists and on the globe, without covering the
  item photo. Without it nothing shows (see *Marking a drop claimed*).
- **Changing drops flies the windows exactly as the About page does.** They
  flew half as far and faster before, so the after-images hardly showed.
- **Blog and Projects**: choosing a post flies the reader out and back in with
  it, with the same after-images. Each post has its own address to link to
  (`blog#building-with-createjs`). The text is larger (16.5px, was 12.5px), in
  a column a comfortable line long, with the date and reading time under the
  title and the previous and next posts at the end. ← and → change post; ↑ ↓,
  Page Up, Page Down and Space scroll it.
- **Store**: Prev and Next fly the cards out and the next page's in. The
  descriptions are larger: 14px (12.5px before), and 13.5px on phones in four
  lines (11.5px in three).
- **About**: larger text, 15px (12.5px before; 14px on phones, 10px before).
- **Phones, Drops**: bigger buttons on the drop screen (WORLD MAP and each
  drop in the strip 44px tall, the zoom buttons 40px), the globe a little
  smaller to make room, and the drop you are on scrolled into view in the
  strip.

**Fixed**
- **Store, on any screen that needed a second page**: the Prev / Next bar sat
  on top of the site's menu at the top of the screen (it was a `<nav>`, and
  the menu's style pins every `<nav>` there). It is at the bottom now; on a
  phone it shares a line with the cart button instead of sitting under it.
- **Store, short screens** (a phone on its side, a short laptop window): a
  card taller than the space was cut off, ADD TO CART included. When not even
  one card fits, the store now scrolls like any other page.
- **About, on most phones**: the About Me window was cut off at the bottom of
  any screen shorter than about 700px (an iPhone in Safari, for one), with no
  way to scroll to it. The page scrolls now when the two windows don't fit.
- The how-to comment at the top of the Drops page still described
  `data-status`, which does nothing since 2026.09.29. It describes
  `data-claimed` now.

## 2026.10.03 update

- **Every drop has its own point on the globe.** The three San Francisco
  drops were one point marked x3, so pointing at 002 or 001 seemed to do
  nothing. They now sit on a small ring around their spot, and the pointer
  moves to each one.
- **The globe zooms**: + and − buttons at its top left (and the mouse wheel,
  a pinch, or the + − 0 keys), and a globe button back to the whole globe.
  A drop chosen while zoomed in opens as before, and WORLD MAP returns to
  the same zoom.
- **Changing drops animates like choosing one.** Picking a drop in the drop
  screen's list, or with the arrow keys, flies its windows out and back in
  with the new drop. Before, they cut over.
- **The way back is easy to find.** `< WORLD` was a faint line of text. It is
  now a red-framed **WORLD MAP** button at the top of the drop list, and a
  globe button on the street map, under recentre.
- With the street map focused, the arrow keys pan it. They used to pan it and
  change the drop at the same time.

## 2026.09.30 update

- **The Drops page opens on the world.** A globe with every drop and the list
  of drops with their dates; choosing one flies into it on the same page
  (see *The Drops page: the world, then a drop*). Each drop has its own
  address (`drops#003`), and a drop is NEW for its first week.
- **Hemispheres are labelled properly.** The frequency bar said °N and °W
  whatever the drop; south of the equator or east of Greenwich it now says
  °S or °E.
- `page-script.js` can fly windows out as well as in (`pn0vaFly.enter`,
  `exit`, `reset`): the Drops page moves between its screens with it.

## 2026.09.29 update

- **A new drop location gets its street map automatically** when you build
  (see *The Drops map*). `tools/make-map.py` also used to cut one box around
  all the drops for the zoomed-out view; with drops in two cities that box
  covers everything in between (about 1,000 km for San Francisco and
  Arizona). Each drop gets its own area now.
- **Drops no longer have an Open / Claimed status.** The label on each row,
  the chip in the frequency bar and the Open/Recovered tally are gone for
  good. `data-status` in `drops.html` is ignored and can be deleted.
- **The frequency bar is slimmer.** Its Placed and Elapsed readouts kept the
  browser's default list margins, so the bar `drops.css` means to be "about
  70px" was 96px (113px on phones). The map gets the difference. Phones now
  show Elapsed down to 340px wide and Placed from 520px.
- **The About page's window entrance runs on every content page.** The
  windows on Blog, Projects, Drops and Store fly in from the edge they sit
  against, trailing red after-images, as About's always have.
  `page-script.js` does it for any element marked `data-fly`. It stays still
  when the visitor's system asks for reduced motion, and with JavaScript off
  the windows are simply there.

## 2026.09.27 update

**Fixed**
- **The clean builds' `.htaccess` looped on Apache.** Every page, and `/`,
  redirected until the browser gave up ("too many redirects"). Now tested on
  Apache 2.4; see *The server* above.
- **Phones.** Blog and Projects were wider than the screen, so text was cut off
  at the right edge. Drops drew `DROP #003`, the coordinates and the status on
  top of each other, and hid the only "What is a drop?" button.
- **JavaScript off.** Blog and Projects showed two empty frames; they now show
  every entry as one long page.
- **Keyboard.** The start screen only answered clicks, so the home menu could
  not be reached without a mouse or touch screen. Enter and Space work now.
- **Home.** `TAP TO START` now reads `TAP TO ENTER`, with no outline.
- **Projects** shipped with 10 unclosed `<div>`s (a regex in `build_reader`).
- **Store.** Saved carts kept old prices after a price change; buyers came back
  from Square to a full cart; checkout panels showed developer instructions to
  customers; cart lines rendered saved text as HTML. See STORE-SETUP.md.

**Added**
- **`PREVIEW.cmd`: the site on your computer, as the host will show it.**
  Double-click it before uploading: clean addresses, redirects and the
  Drops map all work, with nothing to install (see *Local preview*).
- **The Drops map is self-hosted.** Carto's tiles now say "API key required";
  the streets come from `maps/drops.pmtiles` on your own server instead. Run
  `tools/make-map.py` once to create it (see *The Drops map*).
- A favicon (the P and the sword, cut from the logo), an iPhone home-screen
  icon, and link previews: a shared link to any page shows the full logo.
  Per-page descriptions and canonical URLs; `robots.txt` and `sitemap.xml`.
- Every image link carries a `?v=` stamp taken from the file, so new logo art
  reaches returning visitors at once instead of waiting out their cache.
- Security headers, no folder listings, gzip and cache rules in `.htaccess`.

**Build**
- `_source/brand-kit/` is a snapshot of the PN0VA brand kit, rebuilt from the
  2026-08-19 output. Your real `PN0VA` folder still wins when it sits beside
  this one; the snapshot only lets the build run anywhere else.
- Files are always written with Windows line endings, so a build on any OS is
  byte-identical to a build on yours.
- `tools/make-icons.js` regenerates the icons from `logo/pn0va-logo.svg`.
- `README.pdf` and `STORE-SETUP.pdf` are older than their `.md` files. Run
  `python tools/md2pdf.py` on your PC to refresh them (it uses Windows fonts).

## What changed from the 2026-07-06 build

**Branding**
- Corrected logotype — katakana now **ピー・ノバ** everywhere, including the
  raster art. `logo.svg` is outlined so it needs no font installed; the sprite
  atlas driving the animated homepage logo had its `ーバー` cell repainted to
  `バ` (the glyph cut from the original art, so the font still matches); and
  `logo2.png` / `logo.png` were regenerated from the corrected vector.
- **The no-JS fallback logo is now visible.** `logo2.png` was 100% black,
  displayed on the black homepage with no filter — so with JavaScript off the
  homepage showed nothing at all. It is now red.
- Palette migrated to the brand kit. Body copy came **off pure white onto
  linen** `#E8E2DC`, which is what lets bone `#FFFFFF` mean *you are here*.
  Yellow is gone entirely — state went to bone, the `h3` sub-headings went to
  the chroma. Greys warmed to taupe/ash.
- Fixed the two drifted reds (`#ff1608`, `rgba(255,22,8,.5)`).

**Structure**
- `geocache.html` → **`drops.html`**, and ~550 lines of dead `geo-*` CSS
  stripped out. Nav and home menu rewritten on every page.

**No more CDNs.** The site makes **no external requests** (since 2026.09.27 the
Drops map is served by the site too; see *The Drops map*):
- Press Start 2P is self-hosted from `fonts/` — which also removes the
  `@import`-ordering trap that once stopped the pixel font loading at all.
- CreateJS is vendored to `vendor/` — `index.html` already carried fallback
  code for that CDN failing, which tells you it had.

## The store was rebuilt, not recovered

**`shop.html` did not survive.** (It is `store.html` now — renamed 2026-08-02.) It isn't in `website-fixed.zip`,
`website-clean-urls.zip`, `files (2).zip`, or anywhere on the Desktop. Your
`PROJECT-HISTORY.md` explains why: the dev container reset partway through that
session, the site was restored from the packaged zips, and the shop was layered
back on afterwards — so it only ever existed in a container that no longer
exists.

What ships here is rebuilt from the description in that history, and matches it:

- Card grid, `auto-fill minmax(280px, 1fr)`; 4:3 image, name, glowing price,
  unlimited-length description, ADD TO CART pinned to the card bottom
- Floating CART button with a count badge that pulses on add
- Slide-in panel: qty +/−, remove, subtotal; closes on Esc or backdrop
- Persisted in `localStorage` under **`pn0va-cart`** (same key as the original)
- Items are pure HTML with `data-id` / `data-name` / `data-price`
- `SQUARE INTEGRATION POINT` comment marks where `checkout()` gets replaced;
  the cart is exposed as `cartLines()` and `total()`

Product copy and images are placeholders. **The three `data-id`s are made up** —
if the original shop ever resurfaces, reconcile the ids before going live or
returning customers' saved carts will mismatch.

## Before deploying

1. Replace the placeholder art in `images/store/`, `images/blog/` and
   `images/about/`, and give the drops their photos of the spot and the
   item (see *Adding a drop, or a drop zone*); the two drop placeholders in
   `images/` stand in for any a drop doesn't have. Put it in the source
   (`_source/website-fixed/images/`, the brand kit's `drops/images/`; the
   store placeholders are written by `build.py`), not in the build folders,
   which the next build wipes.
2. Wire up Square — see **STORE-SETUP.md**, which covers the three checkout
   modes, a working serverless endpoint, and what else you need before listing
   anything for real.
3. ~~Regenerate the clean-URL build and add `/drops` to `.htaccess`.~~ **Done:**
   `build.py` writes the `-clean` folders and their `.htaccess`.
4. ~~Fix the stale line in the site's own `CLAUDE.md`.~~ **Done 2026-08-19.**
   `CLAUDE.md`, the blog and projects copy, the `index.html` menu comment and
   the `page-script.js` / `page-style.css` headers all read **JRPG** now. The
   change was made in `_source/website-fixed/` and rebuilt — editing the build
   outputs would have been erased by the next `build.py` run.

## Local preview

**Double-click `PREVIEW.cmd`** (Windows). Pick a build from the list and the
site opens in your browser at `http://localhost:8940`, served the way the web
host will serve it:

- `/drops`-style addresses, plus the redirects and the missing-page rule,
  read from that build's own `.htaccess`;
- the Drops map;
- nothing cached, so after a rebuild a reload shows the new files.

Nothing to install: it runs on the PowerShell that comes with Windows. Leave
its window open while you look around, and close it to stop. To preview a
folder kept somewhere else, such as an unzipped upload, drag the folder onto
`PREVIEW.cmd`. For the phone layout, press F12 in the browser, then
Ctrl+Shift+M.

The first time, Windows may warn that the file came from the internet: click
**More info**, then **Run anyway**. If it still won't run, right-click the
zip you downloaded, choose **Properties**, tick **Unblock**, and unzip again.

On a Mac or Linux, or from a terminal, the same preview is
`python tools/preview.py` (add a build name, e.g. `no-store-clean`, to skip
the list). It needs Python and nothing else. `tools/preview.ps1` is the server
behind `PREVIEW.cmd`; keep the two in step.

If you use `.claude/launch.json` (`site-shop`, `site-noshop`), it runs
Python's plain `http.server`: no clean addresses and no street map. Point it
at `python tools/preview.py with-store --no-browser --port 8940` instead.
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

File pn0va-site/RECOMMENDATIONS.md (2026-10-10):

# pn0va.com — review and recommendations

2026.09.27. Everything below was checked in a real browser (Chromium, desktop
and phone sizes, JavaScript on and off) and, for the server rules, on Apache
2.4. What was fixed is listed in README.md under *2026.09.27 update*; this file
is what's left, and the answers to the security questions.

## Do these first

1. **Upload the new `with-store-clean` (or `no-store-clean`) folder.** The live
   Drops map says "API key required" because Carto now wants a key; the new
   build carries its own map (README, *The Drops map*), so that goes away. The
   upload also replaces the old `.htaccess`, which sends every page into a
   redirect loop on a standard Apache server ("too many redirects"). If
   pn0va.com loads fine today, your host behaves differently from stock
   Apache, but the new file works either way. Upload the `maps` folder too:
   without it the Drops page falls back to rings on plain ground. To check
   the folder on your computer first, double-click `PREVIEW.cmd` (README,
   *Local preview*).
2. **Turn on HTTPS**, then force it (see README, *The server*). This matters
   most for the store: over plain HTTP, someone on the same public Wi-Fi can
   change the page on its way to a buyer, including where Checkout sends them.
3. **Keep the store offline until checkout is set up.** It is in demo mode:
   buyers can fill a cart but cannot pay. Use `no-store-clean` until then.
4. **Replace the template content.** The blog posts, the projects (Task Manager
   App, Weather Dashboard…), the About text and every image are placeholders.
   This is what visitors will notice first.
5. **Add a way to reach you.** About says "get in touch", but there is no email
   or social link anywhere, and a store legally needs contact details in most
   places.

## The logo

**The logo file is up to date.** The image you sent is byte-for-byte the site's
`images/logo2.png`. It is also now the favicon source, the iPhone home-screen
icon and the link-preview image.

**The homepage animation is not an exact copy of it.** The animation is a
separate Adobe Animate export (`script.js` + `images/index_atlas_1.png`) and
has always been composed differently. At the same letter height:

- the letters are about 23% wider, the whole lockup is squashed vertically,
  and the bar runs much further past the P and the A;
- the katakana is larger and tighter and starts right after the sword, where
  your file spreads it across the right side. When ピー・ノーバー became
  ピー・ノバ, only one glyph of the animation was repainted, so the text now
  stops under the V;
- the middle dot is square rather than round.

Three ways forward:

| | What it means | Trade-off |
|---|---|---|
| **A. Re-compose the animation** | Adjust its final frame to match your file exactly | Stays in Adobe Animate; the letters remain a bitmap that looks soft on high-resolution screens |
| **B. Rebuild the intro from `logo.svg`** | Same choreography (bar grows, letters rise, sword drops, katakana fades) in SVG and CSS | Exact match forever, sharp on every screen, about 300 KB lighter; no longer edited in Animate |
| C. Leave it | The animation stays its own variant | The homepage and your logo file differ |

My recommendation is **B**, unless you edit the animation in Animate yourself.

## Security

### Drops: can someone edit its data?

**No, not in a way anyone else would see.** The page is a set of plain files.
A visitor can change what their own browser shows (every browser's developer
tools can), but nothing they do reaches the server or other visitors.

The ways to change what everyone sees:

- your **hosting account** (control panel, FTP, file manager);
- your **domain registrar** (where pn0va.com is registered) and DNS;
- the **computer you build and upload from**;
- the **email** that can reset all of the above.

Use a unique password and two-factor login on each. Use SFTP rather than FTP if
your host offers it.

**Everything on the page is public**, including what the page doesn't display:

- The page source lists every drop zone's exact coordinates (to about
  10 cm), and every drop's photos, caption and story, including claimed ones.
- Files on the server can be fetched even when no page links to them. Folder
  listings are now switched off, but a guessable name like
  `images/item-004.jpg` or `images/item4_092326.jpg` can still be opened.
  Keep a drop's photos out of `drops/images/` until you publish it: the
  build copies everything in that folder.
- **Photos carry where and when they were taken.** A phone writes its GPS
  position, the time and its model into every photo. For a photo of the
  spot that is the zone, which is public anyway, but a photo of the item
  taken at home gives your home away. Take it out before adding the photo:
  on Windows, right-click the photo, *Properties*, *Details*, *Remove
  Properties and Personal Information*, *Create a copy with all possible
  properties removed*; on an iPhone, turn off *Location* under *Options* at
  the top of the share sheet before saving or sending it.
- Never put an answer, code or other secret in the page or its scripts.
  Anything secret, like a story that unlocks over time, needs a small server.

**In the real world:**

- Coordinates plus dates show where you were and when (a spot photo's name
  carries its date, and the page shows it), so keep drop zones away from
  home and work and publish after you've left the area. A zone you return
  to makes your visits easier to predict; vary the times.
- Zone 02's coordinates (drop #002) are 31 m from the centre of Alcatraz
  Island, which is National Park Service land. Leaving items there generally
  needs permission, and many parks have rules on caches.
- A sticker put on a wall, rail or sign can count as graffiti or littering.
  Stuck to the drop itself (its box, bag or tag), it marks the drop without
  marking the place.

**The map** no longer depends on anyone. Carto now answers keyless requests
with "API key required" tiles, so the streets come from a file on your own
server instead (README, *The Drops map*). Visitors' browsers ask no map
company for anything, and no one can change its terms or switch it off.

### Store: how safe is it?

**Safe to browse, not ready to sell.**

- **Card details never touch your site.** Buyers type them on Square's page.
  That's the safest setup a small store can have: there is nothing on your
  server worth stealing.
- **Nobody can pay less than your price.** A visitor can edit a price in their
  browser, but it only changes their own screen. Square charges the payment
  link's price in `link` mode, or your server's price list in `api` mode. I
  tested it: an edited $0.01 price has no effect, and the cart now ignores
  edited prices too.
- **Fixed today:**
  - saved carts kept old prices after you changed one;
  - buyers came back from Square to a full cart;
  - customers saw developer instructions at checkout;
  - text saved in the cart could run as code.
- **Before taking real orders:**
  - choose a checkout mode (STORE-SETUP.md);
  - add real photos;
  - add a refund/returns policy, shipping costs and times, sales tax, and
    contact details;
  - set up Square order notifications and two-factor login on Square.
  - In `api` mode the Square access token lives only on the server, never in
    `store.js`.
- **`?paid=1` is not proof of payment.** It is just the address Square sends
  buyers back to, and anyone can type it. Ship orders from Square's
  notifications or dashboard.

### The server

The fixed `.htaccess` also:

- stops folder listings;
- stops other sites loading yours inside a frame to trick clicks;
- sends the standard browser-protection headers;
- has the HTTPS switch ready to turn on.

A full Content-Security-Policy is worth adding once you know which outside
scripts you'll use (Square, analytics); adding it now risks breaking them.

## Page by page
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

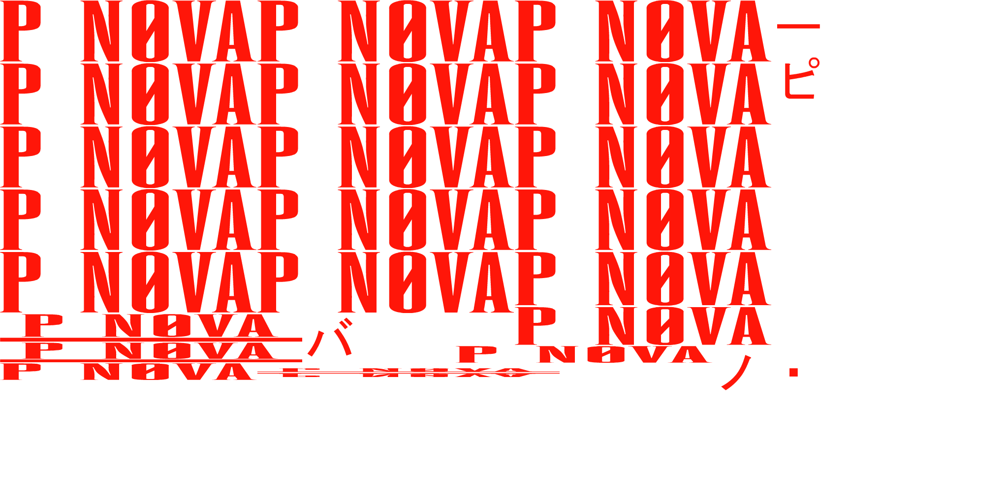
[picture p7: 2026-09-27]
pn0va-site/_source/brand-kit/logo/index_atlas_1.png

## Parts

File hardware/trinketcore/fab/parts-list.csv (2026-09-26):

Ref | Value (LIC build) | Value (EDLC build) | Manufacturer | MPN | Footprint | LCSC | Assembled | Notes
BT1 | LIC 3.8V | EDLC 2.7V |  |  | Supercap_Pads |  | no (you fit it) | your lithium-ion capacitor; lies flat on the back (not assembled)
BT2 | LIC 3.8V | EDLC 2.7V |  |  | Supercap_Pads |  | no (you fit it) | your lithium-ion capacitor; lies flat on the back (not assembled)
C1 | 4.7uF | 4.7uF | Samsung Electro-Mechanics | CL21A475KAQNNNE | C_0805_2012Metric | C1779 | yes | charger input
C2 | 10uF | 10uF | Samsung Electro-Mechanics | CL10A106KP8NNNC | C_0603_1608Metric | C19702 | yes | charger output
C3 | 10nF | 10nF | Samsung Electro-Mechanics | CL05B103KB5NNNC | C_0402_1005Metric | C15195 | yes | ignores millisecond dips from load steps
C5 | 100nF | 100nF | Samsung Electro-Mechanics | CL05B104KO5NNNC | C_0402_1005Metric | C1525 | yes | U3 supply
C6 | 1uF | 1uF | Samsung Electro-Mechanics | CL05A105KA5NQNC | C_0402_1005Metric | C52923 | yes | VAON bulk
C7 | 10nF | 10nF | Samsung Electro-Mechanics | CL05B103KB5NNNC | C_0402_1005Metric | C15195 | yes | soft start
C8 | 4.7uF | 4.7uF | Samsung Electro-Mechanics | CL10A475KO8NNNC | C_0603_1608Metric | C19666 | yes | keeps power on ~4-6 s after a button press so firmware can raise HOLD
C9 | 10uF | 10uF | Samsung Electro-Mechanics | CL21A106KAYNNNE | C_0805_2012Metric | C15850 | yes | regulator input
C10 | 100nF | 100nF | Samsung Electro-Mechanics | CL05B104KO5NNNC | C_0402_1005Metric | C1525 | yes | VINA bypass
C11 | 10uF | 10uF | Samsung Electro-Mechanics | CL21A106KAYNNNE | C_0805_2012Metric | C15850 | yes | regulator output
C12 | 10uF | 10uF | Samsung Electro-Mechanics | CL21A106KAYNNNE | C_0805_2012Metric | C15850 | yes | regulator output
C13 | 100nF | 100nF | Samsung Electro-Mechanics | CL05B104KO5NNNC | C_0402_1005Metric | C1525 | yes | output HF bypass
C14 | 100nF | 100nF | Samsung Electro-Mechanics | CL05B104KO5NNNC | C_0402_1005Metric | C1525 | yes | ADC sample charge
C15 | 100nF | 100nF | Samsung Electro-Mechanics | CL05B104KO5NNNC | C_0402_1005Metric | C1525 | yes | RTC supply
C16 | 15pF | 15pF | Samsung Electro-Mechanics | CL05C150JB5NNNC | C_0402_1005Metric | C1548 | yes | crystal load
C17 | 15pF | 15pF | Samsung Electro-Mechanics | CL05C150JB5NNNC | C_0402_1005Metric | C1548 | yes | crystal load
C18 | 100nF | 100nF | Samsung Electro-Mechanics | CL05B104KO5NNNC | C_0402_1005Metric | C1525 | yes | IOVDD pin 1
C19 | 100nF | 100nF | Samsung Electro-Mechanics | CL05B104KO5NNNC | C_0402_1005Metric | C1525 | yes | IOVDD pin 10
C20 | 100nF | 100nF | Samsung Electro-Mechanics | CL05B104KO5NNNC | C_0402_1005Metric | C1525 | yes | IOVDD pin 22
C21 | 100nF | 100nF | Samsung Electro-Mechanics | CL05B104KO5NNNC | C_0402_1005Metric | C1525 | yes | IOVDD pin 33
C22 | 100nF | 100nF | Samsung Electro-Mechanics | CL05B104KO5NNNC | C_0402_1005Metric | C1525 | yes | IOVDD pin 42
C23 | 100nF | 100nF | Samsung Electro-Mechanics | CL05B104KO5NNNC | C_0402_1005Metric | C1525 | yes | IOVDD pin 49
C24 | 100nF | 100nF | Samsung Electro-Mechanics | CL05B104KO5NNNC | C_0402_1005Metric | C1525 | yes | USB_VDD
C25 | 100nF | 100nF | Samsung Electro-Mechanics | CL05B104KO5NNNC | C_0402_1005Metric | C1525 | yes | ADC_AVDD
C26 | 1uF | 1uF | Samsung Electro-Mechanics | CL05A105KA5NQNC | C_0402_1005Metric | C52923 | yes | VREG_IN
C27 | 1uF | 1uF | Samsung Electro-Mechanics | CL05A105KA5NQNC | C_0402_1005Metric | C52923 | yes | VREG_VOUT
C28 | 100nF | 100nF | Samsung Electro-Mechanics | CL05B104KO5NNNC | C_0402_1005Metric | C1525 | yes | DVDD pin 23
C29 | 100nF | 100nF | Samsung Electro-Mechanics | CL05B104KO5NNNC | C_0402_1005Metric | C1525 | yes | DVDD pin 50
C30 | 10uF | 10uF | Samsung Electro-Mechanics | CL21A106KAYNNNE | C_0805_2012Metric | C15850 | yes | 3V3 bulk at the RP2040
C31 | 100nF | 100nF | Samsung Electro-Mechanics | CL05B104KO5NNNC | C_0402_1005Metric | C1525 | yes | flash supply
C32 | 10uF | 10uF | Samsung Electro-Mechanics | CL21A106KAYNNNE | C_0805_2012Metric | C15850 | yes | amplifier supply
C33 | 100nF | 100nF | Samsung Electro-Mechanics | CL05B104KO5NNNC | C_0402_1005Metric | C1525 | yes | amplifier supply
D1 | RED | RED | Lite-On | LTST-C191KRKT | LED_0603_1608Metric |  | yes | CHG: on while charging
D2 | 1N4148WS | 1N4148WS | Diodes Incorporated | 1N4148WS-7-F | D_SOD-323 | C2128 | yes | USB power turns the gadget on
D3 | 1N4148WS | 1N4148WS | Diodes Incorporated | 1N4148WS-7-F | D_SOD-323 | C2128 | yes | lets the RP2040 read the power button
D4 | 1N4148WS | 1N4148WS | Diodes Incorporated | 1N4148WS-7-F | D_SOD-323 | C2128 | yes | lets the RP2040 read the charge status without back-feeding
D5 | GREEN | GREEN | Lite-On | LTST-C191KGKT | LED_0603_1608Metric |  | yes | FULL: on when charged (USB plugged in)
D6 | 1N4148WS | 1N4148WS | Diodes Incorporated | 1N4148WS-7-F | D_SOD-323 | C2128 | yes | lets the RP2040 see USB power (reads low when plugged in)
D7 | BLUE | BLUE | Lite-On | LTST-C191TBKT | LED_0603_1608Metric |  | yes | user LED (GP25, like a Pico)
J1 | USB-C | USB-C | Korean Hroparts Elec | TYPE-C-31-M-12 | USB_C_Receptacle_HRO_TYPE-C-31-M-12 | C165948 | yes | USB-C receptacle, USB 2.0, 16 pin
J4 | DISPLAY | DISPLAY |  |  | PinSocket_1x08_P2.54mm_Vertical |  | no (you fit it) | SPI TFT/OLED module socket: GND VCC SCL SDA RES DC CS BLK
J5 | I2C OLED | I2C OLED |  |  | PinSocket_1x04_P2.54mm_Vertical |  | no (you fit it) | I2C OLED module socket: GND VCC SCL SDA
J6 | EXPANSION | EXPANSION |  |  | PinHeader_1x14_P2.54mm_Vertical |  | no (you fit it) | expansion header: LEDs, buttons, sensors, lid switch
J7 | SPEAKER | SPEAKER | JST | B2B-PH-K-S(LF)(SN) | JST_PH_B2B-PH-K_1x02_P2.00mm_Vertical |  | no (you fit it) | speaker, 8 ohm (JST PH 2.0 mm, or solder the wires)
J8 | QWIIC | QWIIC | JST | SM04B-SRSS-TB(LF)(SN) | JST_SH_SM04B-SRSS-TB_1x04-1MP_P1.00mm_Horizontal |  | yes | Qwiic / STEMMA QT I2C connector
JP1 | USB-ON | USB-ON |  |  | SolderJumper-2_P1.3mm_Bridged_RoundedPad1.0x1.5mm |  | no (you fit it) | cut to stop USB from turning the gadget on
JP2 | ALWAYS-ON | ALWAYS-ON |  |  | SolderJumper-2_P1.3mm_Open_RoundedPad1.0x1.5mm |  | no (you fit it) | bridge for always-on (no power button)
L1 | 1.5uH | 1.5uH | Taiyo Yuden | NR3015T1R5N | L_3015_Universal | C7497056 | yes | 1.5 uH, 3 x 3 mm shielded, Isat >= 1.5 A
Q1 | AO3401A | AO3401A | Alpha & Omega Semiconductor | AO3401A | SOT-23 | C15127 | yes | master switch: opens below 2.6 V or in ship mode
Q2 | AO3400A | AO3400A | Alpha & Omega Semiconductor | AO3400A | SOT-23 | C20917 | yes | USB power turns Q1 on (wakes from cut-off)
Q3 | AO3400A | AO3400A | Alpha & Omega Semiconductor | AO3400A | SOT-23 | C20917 | yes | keeps Q1 on while the capacitor is healthy
Q4 | AO3400A | AO3400A | Alpha & Omega Semiconductor | AO3400A | SOT-23 | C20917 | yes | SHIP high forces a cut-off (storage mode)
Q5 | AO3401A | AO3401A | Alpha & Omega Semiconductor | AO3401A | SOT-23 | C15127 | yes | load switch with soft start
Q6 | AO3400A | AO3400A | Alpha & Omega Semiconductor | AO3400A | SOT-23 | C20917 | yes | turns the gadget on
Q7 | AO3401A | AO3401A | Alpha & Omega Semiconductor | AO3401A | SOT-23 | C15127 | yes | button / RTC alarm turns the gadget on
Q8 | AO3400A | AO3400A | Alpha & Omega Semiconductor | AO3400A | SOT-23 | C20917 | yes | in series with Q6: nothing turns the gadget on below the cut-off, not even USB
Q9 | AO3400A | AO3400A | Alpha & Omega Semiconductor | AO3400A | SOT-23 | C20917 | yes | lights FULL when the charger releases STAT
R1 | 5.1k | 5.1k | Yageo | RC0402FR-075K1L | R_0402_1005Metric | C25905 | yes | CC1 sink pull-down
R2 | 5.1k | 5.1k | Yageo | RC0402FR-075K1L | R_0402_1005Metric | C25905 | yes | CC2 sink pull-down
R3 | 1k | 1k | Yageo | RC0402FR-071KL | R_0402_1005Metric | C11702 | yes | charge current = 300 V / R3 = 300 mA
R4 | 120k | 75k | Yageo | RC0402FR-07120KL | R_0402_1005Metric | C25750 | yes | charge voltage = 0.8 V x (1 + R4/R5) = 3.71 V
R5 | 33k | 33k | Yageo | RC0402FR-0733KL | R_0402_1005Metric | C25779 | yes | returned to /PG so the divider cannot drain the capacitor without USB
R6 | 1k | 1k | Yageo | RC0402FR-071KL | R_0402_1005Metric | C11702 | yes | charging LED current
R7 | 10M | 10M | Yageo | RC0402FR-0710ML | R_0402_1005Metric | C26082 | yes | Q1 off by default
R8 | 10k | 10k | Yageo | RC0402FR-0710KL | R_0402_1005Metric | C25744 | yes
R9 | 100k | 100k | Yageo | RC0402FR-07100KL | R_0402_1005Metric | C25741 | yes
R10 | 1M | 1M | Yageo | RC0402FR-071ML | R_0402_1005Metric | C26083 | yes | UVLO divider top (1/3)
R11 | 470k | 470k | Yageo | RC0402FR-07470KL | R_0402_1005Metric | C25790 | yes | UVLO divider top (2/3)
R12 | 330k | 330k | Yageo | RC0402FR-07330KL | R_0402_1005Metric | C25778 | yes | UVLO divider top (3/3)
R13 | 330k | 470k | Yageo | RC0402FR-07330KL | R_0402_1005Metric | C25778 | yes | cut-off = 0.405 V x (1 + 1.8M/R13) = 2.61 V
R14 | 1M | 1M | Yageo | RC0402FR-071ML | R_0402_1005Metric | C26083 | yes | RESET pull-up
R15 | 1M | 1M | Yageo | RC0402FR-071ML | R_0402_1005Metric | C26083 | yes | SHIP idles low
R16 | 1M | 1M | Yageo | RC0402FR-071ML | R_0402_1005Metric | C26083 | yes | Q5 off by default
R17 | 100k | 100k | Yageo | RC0402FR-07100KL | R_0402_1005Metric | C25741 | yes | soft start
R18 | 1M | 1M | Yageo | RC0402FR-071ML | R_0402_1005Metric | C26083 | yes | hold-up discharge
R20 | 100k | 100k | Yageo | RC0402FR-07100KL | R_0402_1005Metric | C25741 | yes | firmware keeps power on
R21 | 10k | 10k | Yageo | RC0402FR-0710KL | R_0402_1005Metric | C25744 | yes
R22 | 10k | 10k | Yageo | RC0402FR-0710KL | R_0402_1005Metric | C25744 | yes
R23 | 100k | 100k | Yageo | RC0402FR-07100KL | R_0402_1005Metric | C25741 | yes
R24 | 1M | 1M | Yageo | RC0402FR-071ML | R_0402_1005Metric | C26083 | yes | WAKE idles high
R25 | 1k | 1k | Yageo | RC0402FR-071KL | R_0402_1005Metric | C11702 | yes | external wake input (lid, tilt or reed switch to GND)
R26 | 100k | 100k | Yageo | RC0402FR-07100KL | R_0402_1005Metric | C25741 | yes | capacitor voltage / 2
R27 | 100k | 100k | Yageo | RC0402FR-07100KL | R_0402_1005Metric | C25741 | yes | capacitor voltage / 2
R28 | 4.7k | 4.7k | Yageo | RC0402FR-074K7L | R_0402_1005Metric | C25900 | yes | I2C pull-up
R29 | 4.7k | 4.7k | Yageo | RC0402FR-074K7L | R_0402_1005Metric | C25900 | yes | I2C pull-up
R30 | 1k | 1k | Yageo | RC0402FR-071KL | R_0402_1005Metric | C11702 | yes | full LED current
R31 | 1k | 1k | Yageo | RC0402FR-071KL | R_0402_1005Metric | C11702 | yes | crystal drive limit
R32 | 27 | 27 | Yageo | RC0402FR-0727RL | R_0402_1005Metric |  | yes | USB D+ series resistor
R33 | 27 | 27 | Yageo | RC0402FR-0727RL | R_0402_1005Metric |  | yes | USB D- series resistor
R34 | 1k | 1k | Yageo | RC0402FR-071KL | R_0402_1005Metric | C11702 | yes | BOOT button
R35 | 10k | 10k | Yageo | RC0402FR-0710KL | R_0402_1005Metric | C25744 | yes | RUN pull-up
R36 | 1M | 1M | Yageo | RC0402FR-071ML | R_0402_1005Metric | C26083 | yes | AMP_EN high = on, (L+R)/2 mix; low = shut down
R37 | 100 | 100 | Yageo | RC0402FR-07100RL | R_0402_1005Metric |  | yes | user LED current
R38 | 100 | 100 | Yageo | RC0402FR-07100RL | R_0402_1005Metric |  | yes | backlight drive (PWM on GP13)
SW1 | POWER/A | POWER/A | XKB Connectivity | TS-1187A-B-A-B | SW_TS-1187A_5.1x5.1mm | C318884 | yes | power / wake button, also readable as BTN; diagonal pads 1+4
SW2 | B | B | XKB Connectivity | TS-1187A-B-A-B | SW_TS-1187A_5.1x5.1mm | C318884 | yes | second button (GP14)
SW3 | BOOT | BOOT | Omron | B3U-1000P | SW_SPST_B3U-1000P |  | yes | hold while pressing RESET for the USB bootloader
SW4 | RESET | RESET | Omron | B3U-1000P | SW_SPST_B3U-1000P |  | yes | reset (also forces power-off after ~5 s)
U1 | USBLC6-2SC6 | USBLC6-2SC6 | STMicroelectronics | USBLC6-2SC6 | SOT-23-6 | C7519 | yes | USB ESD protection
U2 | BQ25173DSGR | BQ25173DSGR | Texas Instruments | BQ25173DSGR | WSON-8-1EP_2x2mm_P0.5mm_EP0.9x1.6mm_Vias0.3 | C2942216 | yes | 800 mA linear supercapacitor charger
U3 | TPS3808G01DBVR | TPS3808G01DBVR | Texas Instruments | TPS3808G01DBVR | SOT-23-6 | C19653 | yes | under-voltage supervisor, 0.405 V SENSE threshold
U4 | TPS63031DSKR | TPS63031DSKR | Texas Instruments | TPS63031DSKR | WSON-10-1EP_2.5x2.5mm_P0.5mm_EP1.2x2mm_Vias0.3 | C15516 | yes | 3.3 V buck-boost, 1.8-5.5 V in
U5 | PCF8563T | PCF8563T | NXP | PCF8563T/5,518 | SOIC-8_3.9x4.9mm_P1.27mm | C7440 | yes | real-time clock; its alarm wakes the gadget
U6 | RP2040 | RP2040 | Raspberry Pi | RP2040 | QFN-56-1EP_7x7mm_P0.4mm_EP3.2x3.2mm_Vias0.3 | C2040 | yes | dual Cortex-M0+ microcontroller
U7 | W25Q128JVS | W25Q128JVS | Winbond | W25Q128JVSIQ | SOIC-8_5.23x5.23mm_P1.27mm | C97521 | yes | 16 MB QSPI flash (program, sounds, images)
U8 | MAX98357A | MAX98357A | Analog Devices | MAX98357AETE+T | TQFN-16-1EP_3x3mm_P0.5mm_EP1.23x1.23mm_Vias0.3 |  | yes | I2S class-D speaker amplifier, 9 dB gain
Y1 | 32.768kHz | 32.768kHz | Epson | Q13FC1350000400 | Crystal_SMD_3215-2Pin_3.2x1.5mm | C32346 | yes | 32.768 kHz, 12.5 pF, 20 ppm
Y2 | 12MHz | 12MHz | Abracon | ABM8-272-T3 | Crystal_SMD_3225-4Pin_3.2x2.5mm |  | yes | 12 MHz, 10 pF (the RP2040 reference crystal)

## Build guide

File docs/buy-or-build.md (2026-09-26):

# Buy or build?

You want a board that charges from USB, stores energy in a capacitor
instead of a LiPo, and powers small games, e-ink gadgets and music toys. Here
are your options, cheapest effort first.

## 1. Order TrinketCore from PCBWay (all-in-one, recommended for trinkets)

[`hardware/trinketcore`](../hardware/trinketcore) is a complete gadget board:
two capacitor positions, USB-C charging with charge LEDs, an RP2040 with
16 MB of flash, a display socket, a speaker amplifier, buttons and a wake-up
clock. Upload the Gerber zip, BOM and centroid file to PCBWay and it arrives
assembled. You fit the capacitors, a display module and a speaker.

* **Cost:** roughly US$100–180 for five assembled boards before shipping.
  Most of that is setup and parts; ten boards cost little more in total. Trust
  the live quote.
* **Skill:** soldering two capacitor leads each and a pin socket. Then
  CircuitPython: copy two files to a USB drive.
* **Why:** one board covers the music box, games, pets and charms, so you
  prototype every idea on the same hardware and firmware.

See [ordering from PCBWay](../hardware/trinketcore/README.md#ordering-from-pcbway).

## 2. Order CapCore from JLCPCB (bring your own microcontroller)

This repository contains a complete, ready-to-order design:
[`hardware/capcore`](../hardware/capcore). Upload the Gerber zip, BOM and
placement file, and JLCPCB builds and solders all the small parts. You fit
three things yourself with an ordinary soldering iron: the capacitor and two
pin headers.

* **Cost:** roughly US$50–80 for five assembled boards before shipping; most
  of that is one-time setup fees, so 20 boards cost little more in total.
  Plus a few dollars per capacitor. Prices change, so trust the live quote.
* **Time:** about 1–3 weeks including shipping.
* **Skill:** basic through-hole soldering. The fine-pitch parts (0402
  resistors, 2 × 2 mm chips) really need machine assembly, so don't order bare
  boards unless you have a hot-air station and practice.
* **Why it's worth it:** the 3.8 V lithium-ion capacitors that make these
  gadgets practical need a charger with the right voltage (3.71 V, not a LiPo
  charger's 4.2 V) and a hard cut-off above 2.2 V. Off-the-shelf modules
  rarely do both. CapCore also adds the pieces a gadget needs: power button,
  wake-up timer, 3.3 V regulation and USB data pass-through.

See [`hardware/capcore/README.md`](../hardware/capcore/README.md) for the
ordering steps.

## 3. Off-the-shelf modules

There is no common, cheap, off-the-shelf equivalent for lithium-ion
capacitors. What you will find:

* **Generic "supercapacitor charger / boost" modules** (marketplaces like
  AliExpress and Amazon). They are made for 2.7 V EDLCs and usually lack an
  under-voltage cut-off, a power switch and low standby current. They're
  fine for an EDLC-powered blinky toy. **Do not put a 3.8 V LIC on a module
  unless you know its charge voltage and cut-off.**
* **Energy-harvesting evaluation boards** (for example TI's BQ25570 and
  e-peas' AEM series). They are built to trickle solar energy into
  supercapacitors: excellent parts, but expensive boards, slow to charge from
  USB and not gadget-shaped.
* **LiPo charger/power boards** (Adafruit, SparkFun, most dev boards'
  built-in chargers): **not suitable**. They charge to 4.2 V, which ruins a
  3.8 V LIC.

## 4. Buy the finished jewellery

The [Fibonacci earrings](https://lectronz.com/products/rechargeable-supercapacitor-fibonacci-earrings-2)
that inspired this are a finished product: an ATtiny microcontroller, LEDs
and a 40 F lithium-ion capacitor for many hours per charge. Great as a
reference for what's possible, but not a platform for your own designs.

## 5. Design your own

Everything here is generated from Python scripts
([`hardware/capcore/scripts`](../hardware/capcore/scripts)), so changing the
charge current, cut-off voltage or board shape means editing values and
regenerating. The key parts, if you'd rather start from scratch:

| Job | Part used here | Why |
|---|---|---|
| Charger | TI BQ25173 | 800 mA linear charger whose output voltage is set by two resistors, so it suits supercapacitors |
| Cut-off | TI TPS3808G01 | 2.4 µA supervisor with an adjustable threshold |
| 3.3 V | TI TPS63031 | buck-boost: keeps 3.3 V as the capacitor drains from 3.7 V to 2.6 V |
| Clock / wake-up | NXP PCF8563 | 0.25 µA RTC whose alarm can switch the gadget on |
| ESD | ST USBLC6-2SC6 | protects the USB-C data lines |

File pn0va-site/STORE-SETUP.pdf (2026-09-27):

WEBSITE BUILD 2026 / STORE-SETUP.MD

Store — taking real money

The store works end to end except the last step. Adding, removing, quantities, the subtotal and persistence all function; Checkout currently shows you what would be sent instead of charging anyone.
Everything below is about flipping that last switch.

### The one thing that matters

Your Square access token must never appear in store.js. Anything in that file is public — anyone can read it. A leaked token lets someone issue refunds from your account.
That single constraint is what decides which mode you can use.

### Choose a mode

Open store.js. Near the bottom:

var CHECKOUT = {
mode: "demo", | // "demo" | "link" | "api"
currency: "USD",
links: { "pin-gameboy": "", "key-digivice": "", "plate-custom": "" }, endpoint: "/api/checkout"
};
Mode | Backend needed | Multi-item cart | Good for
demo | none | — | what ships now
link | none | ✗ one item at a time | start here
api | yes, small | ✓ | when one-at-a-time starts costing you sales

Mode "link" — no server, works today
Square calls these Payment Links. Each is a hosted checkout page for one product, and the URL is safe to publish.
1. Square Dashboard → Online → Payment Links → Create
2. Choose Accept a payment (or Sell an item to attach the photo and stock).
3. Set the name and price so they match this page exactly — the customer will compare, and a mismatch reads as a scam.
4. Turn on Collect shipping address if you're posting it.
5. Copy the https://square.link/u/XXXXXXX URL.
6. Paste it against the matching data-id:

mode: "link",
links: {
"pin-gameboy": "https://square.link/u/AbCdEfGh", "key-digivice": "https://square.link/u/IjKlMnOp",
"plate-custom": "https://square.link/u/QrStUvWx"
}

The cart still works for browsing; at checkout it redirects to that product's Square page. If more than one line is in the cart it says so rather than charging the wrong amount.
The limitation is real. Someone buying three pins pays three times, in three transactions, with three shipping fees. That is the moment to move to api.
Mode "api" — a real cart
Needs one server endpoint. Netlify Functions, Vercel, Cloudflare Workers — all have free tiers that comfortably cover a maker store.
P_N0VA | Store — taking real money

It receives { lines, currency } and returns { url }:

// netlify/functions/checkout.js
const { randomUUID } = require("crypto");

// PRICES LIVE HERE, NOT IN THE BROWSER. Never trust a price the client sends — // anyone can edit data-price in devtools and buy a $30 plate for $0.01.
const PRICES = {
"pin-gameboy": { name: "Game Boy Pin", cents: 1800 },
"key-digivice": { name: "Digivice Keychain", cents: 2200 }, "plate-custom": { name: "Custom Art Plate", cents: 3000 } };

exports.handler = async (event) => {
const { lines } = JSON.parse(event.body);

const order = {
idempotency_key: randomUUID(),
order: {
location_id: process.env.SQUARE_LOCATION_ID, line_items: lines.map(l => {
const p = PRICES[l.id];
if (!p) throw new Error("unknown product " + l.id); return {
name: p.name,
quantity: String(Math.max(1, Math.min(99, l.qty | 0))),
base_price_money: { amount: p.cents, currency: "USD" } };
})
},
checkout_options: {
redirect_url: "https://pn0va.com/store?paid=1",ask_for_shipping_address: true
}
};

const res = await fetch(
"https://connect.squareup.com/v2/online-checkout/payment-links", { method: "POST",
headers: {
"Square-Version": "2025-01-23",
"Authorization": `Bearer ${process.env.SQUARE_ACCESS_TOKEN}`, "Content-Type": "application/json"
},
body: JSON.stringify(order)
});

const data = await res.json();
if (!res.ok) return { statusCode: 502, body: JSON.stringify(data) };

return { statusCode: 200, body: JSON.stringify({ url: data.payment_link.url }) };
};

Then set mode: "api". Test against Square's sandbox credentials first — they issue a separate token and card numbers that never move money.
Read that PRICES comment twice. The single most common way small stores get robbed is trusting the price the browser sends. The server must look up its own prices from the product id and ignore whatever arrived.

### Before you list anything real

Legally required in most places - A refund/returns policy, and shipping times, on the page or linked from it. - Sales tax. Square can calculate and collect it — turn it on per location. - A real contact address on the site.
You will regret skipping these - Stock. Nothing here knows what's sold out. Until it does, either mark items sold out by hand or let Square's inventory do it (in link mode, Square hides a sold-out link for you). - Shipping cost. Currently £0/$0. Set it in Square per item or per order. - Order notifications. Square emails you, but set it up deliberately rather than finding out three days later. - A sold-out state on the card. The design has one already — reuse the CLAIMED treatment from Drops: ash, struck through.
Worth doing early - Variants (size, colourway). Neither the cart nor data-id handles these. The cheapest fix is one data-id per variant. - Real photos. The placeholders are obviously placeholders and will kill trust faster than anything else on this list. - og: tags so a link to the store previews with the logo instead of nothing. Currently missing sitewide.

### If Square turns out to be the wrong fit

The cart is deliberately payment-agnostic — cartLines() and total() are all any provider needs.
- Stripe Payment Links — same shape as Square's, often simpler dashboard.
- Shopify Buy Button — heaviest, but inventory/tax/shipping all solved.
- Gumroad / Etsy — they take a cut and own the customer relationship, but you list an item and you're selling the same afternoon.
Swapping means rewriting one function, checkout(). Nothing else in the store knows or cares who takes the money.

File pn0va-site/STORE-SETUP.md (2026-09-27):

# Store — taking real money

The store works end to end **except** the last step. Adding, removing, quantities,
the subtotal and persistence all function; `Checkout` currently shows you what
*would* be sent instead of charging anyone.

Everything below is about flipping that last switch.

---

## The one thing that matters

**Your Square access token must never appear in `store.js`.** Anything in that
file is public — anyone can read it. A leaked token lets someone issue refunds
from your account.

That single constraint is what decides which mode you can use.

---

## Choose a mode

Open `store.js`. Near the bottom:

```js
var CHECKOUT = {
  mode: "demo",          //  "demo" | "link" | "api"
  currency: "USD",
  links: { "pin-gameboy": "", "key-digivice": "", "plate-custom": "" },
  endpoint: "/api/checkout"
};
```

| Mode | Backend needed | Multi-item cart | Good for |
|---|---|---|---|
| `demo` | none | — | what ships now |
| **`link`** | **none** | ✗ one item at a time | **start here** |
| `api` | yes, small | ✓ | when one-at-a-time starts costing you sales |

### Mode `"link"` — no server, works today

Square calls these **Payment Links**. Each is a hosted checkout page for one
product, and the URL is safe to publish.

1. Square Dashboard → **Online → Payment Links → Create**
2. Choose *Accept a payment* (or *Sell an item* to attach the photo and stock).
3. Set the name and price so they **match this page exactly** — the customer
   will compare, and a mismatch reads as a scam.
4. Turn on **Collect shipping address** if you're posting it.
5. Copy the `https://square.link/u/XXXXXXX` URL.
6. Paste it against the matching `data-id`:

```js
mode: "link",
links: {
  "pin-gameboy":  "https://square.link/u/AbCdEfGh",
  "key-digivice": "https://square.link/u/IjKlMnOp",
  "plate-custom": "https://square.link/u/QrStUvWx"
}
```

The cart still works for browsing; at checkout it redirects to that product's
Square page. If more than one line is in the cart it says so rather than
charging the wrong amount.

**The limitation is real.** Someone buying three pins pays three times, in three
transactions, with three shipping fees. That is the moment to move to `api`.

### Mode `"api"` — a real cart

Needs one server endpoint. Netlify Functions, Vercel, Cloudflare Workers — all
have free tiers that comfortably cover a maker store.

It receives `{ lines, currency }`, where each line is just `{ id, qty }`, and
returns `{ url }`:

```js
// netlify/functions/checkout.js
const { randomUUID } = require("crypto");

// PRICES LIVE HERE, NOT IN THE BROWSER. Never trust a price the client sends —
// anyone can edit data-price in devtools and buy a $30 plate for $0.01.
// store.js sends only ids and quantities, but anyone can call this URL
// directly with any body they like, so everything is checked below.
const PRICES = {
  "pin-gameboy":  { name: "Game Boy Pin",     cents: 1800 },
  "key-digivice": { name: "Digivice Keychain", cents: 2200 },
  "plate-custom": { name: "Custom Art Plate",  cents: 3000 }
};

const reply = (statusCode, body) => ({ statusCode, body: JSON.stringify(body) });

exports.handler = async (event) => {
  if (event.httpMethod !== "POST") return reply(405, { error: "POST only" });

  let lines;
  try { ({ lines } = JSON.parse(event.body || "{}")); }
  catch { return reply(400, { error: "bad request" }); }
  if (!Array.isArray(lines) || lines.length === 0 || lines.length > 20)
    return reply(400, { error: "bad cart" });

  const line_items = [];
  for (const l of lines) {
    const p = PRICES[l && l.id];
    if (!p) return reply(400, { error: "unknown product" });
    line_items.push({
      name: p.name,
      quantity: String(Math.max(1, Math.min(99, l.qty | 0))),
      base_price_money: { amount: p.cents, currency: "USD" }
    });
  }

  const order = {
    idempotency_key: randomUUID(),
    order: { location_id: process.env.SQUARE_LOCATION_ID, line_items },
    checkout_options: {
      redirect_url: "https://pn0va.com/store?paid=1",
      ask_for_shipping_address: true
    }
  };

  const res = await fetch(
    "https://connect.squareup.com/v2/online-checkout/payment-links", {
      method: "POST",
      headers: {
        "Square-Version": "2025-01-23",
        "Authorization": `Bearer ${process.env.SQUARE_ACCESS_TOKEN}`,
        "Content-Type": "application/json"
      },
      body: JSON.stringify(order)
    });

  const data = await res.json();
  if (!res.ok) {
    console.error("Square error:", JSON.stringify(data));   // your function logs
    return reply(502, { error: "checkout unavailable" });   // not Square's details
  }
  return reply(200, { url: data.payment_link.url });
};
```

**`?paid=1`.** After payment Square sends the buyer back to `redirect_url`.
The store page sees `?paid=1`, empties that buyer's cart and thanks them. It is
**not** proof of payment: anyone can type it into the address bar. Ship orders
from Square's order notifications or dashboard, never from that page. In `link`
mode, if a payment link lets you choose where buyers land after paying, use the
same URL so their cart clears too.

Then set `mode: "api"`. Test against Square's **sandbox** credentials first —
they issue a separate token and card numbers that never move money.

> **Read that `PRICES` comment twice.** The single most common way small stores
> get robbed is trusting the price the browser sends. The server must look up
> its own prices from the product id and ignore whatever arrived.

---

## Before you list anything real

**Legally required in most places**
- A refund/returns policy, and shipping times, on the page or linked from it.
- Sales tax. Square can calculate and collect it — turn it on per location.
- A real contact address on the site.

**You will regret skipping these**
- **Stock.** Nothing here knows what's sold out. Until it does, either mark
  items sold out by hand or let Square's inventory do it (in `link` mode,
  Square hides a sold-out link for you).
- **Shipping cost.** Currently £0/$0. Set it in Square per item or per order.
- **Order notifications.** Square emails you, but set it up deliberately rather
  than finding out three days later.
- **A sold-out state on the card.** The design has one already — reuse the
  `CLAIMED` treatment from Drops: ash, struck through.

**Worth doing early**
- **Variants** (size, colourway). Neither the cart nor `data-id` handles these.
  The cheapest fix is one `data-id` per variant.
- **Real photos.** The placeholders are obviously placeholders and will kill
  trust faster than anything else on this list.
- ~~**`og:` tags** so a link to the store previews with the logo instead of
  nothing.~~ **Done 2026.09.27** on every page.

---

## If Square turns out to be the wrong fit

The cart is deliberately payment-agnostic — `cartLines()` and `total()` are all
any provider needs.

- **Stripe Payment Links** — same shape as Square's, often simpler dashboard.
- **Shopify Buy Button** — heaviest, but inventory/tax/shipping all solved.
- **Gumroad / Etsy** — they take a cut and own the customer relationship, but
  you list an item and you're selling the same afternoon.

Swapping means rewriting one function, `checkout()`. Nothing else in the store
knows or cares who takes the money.

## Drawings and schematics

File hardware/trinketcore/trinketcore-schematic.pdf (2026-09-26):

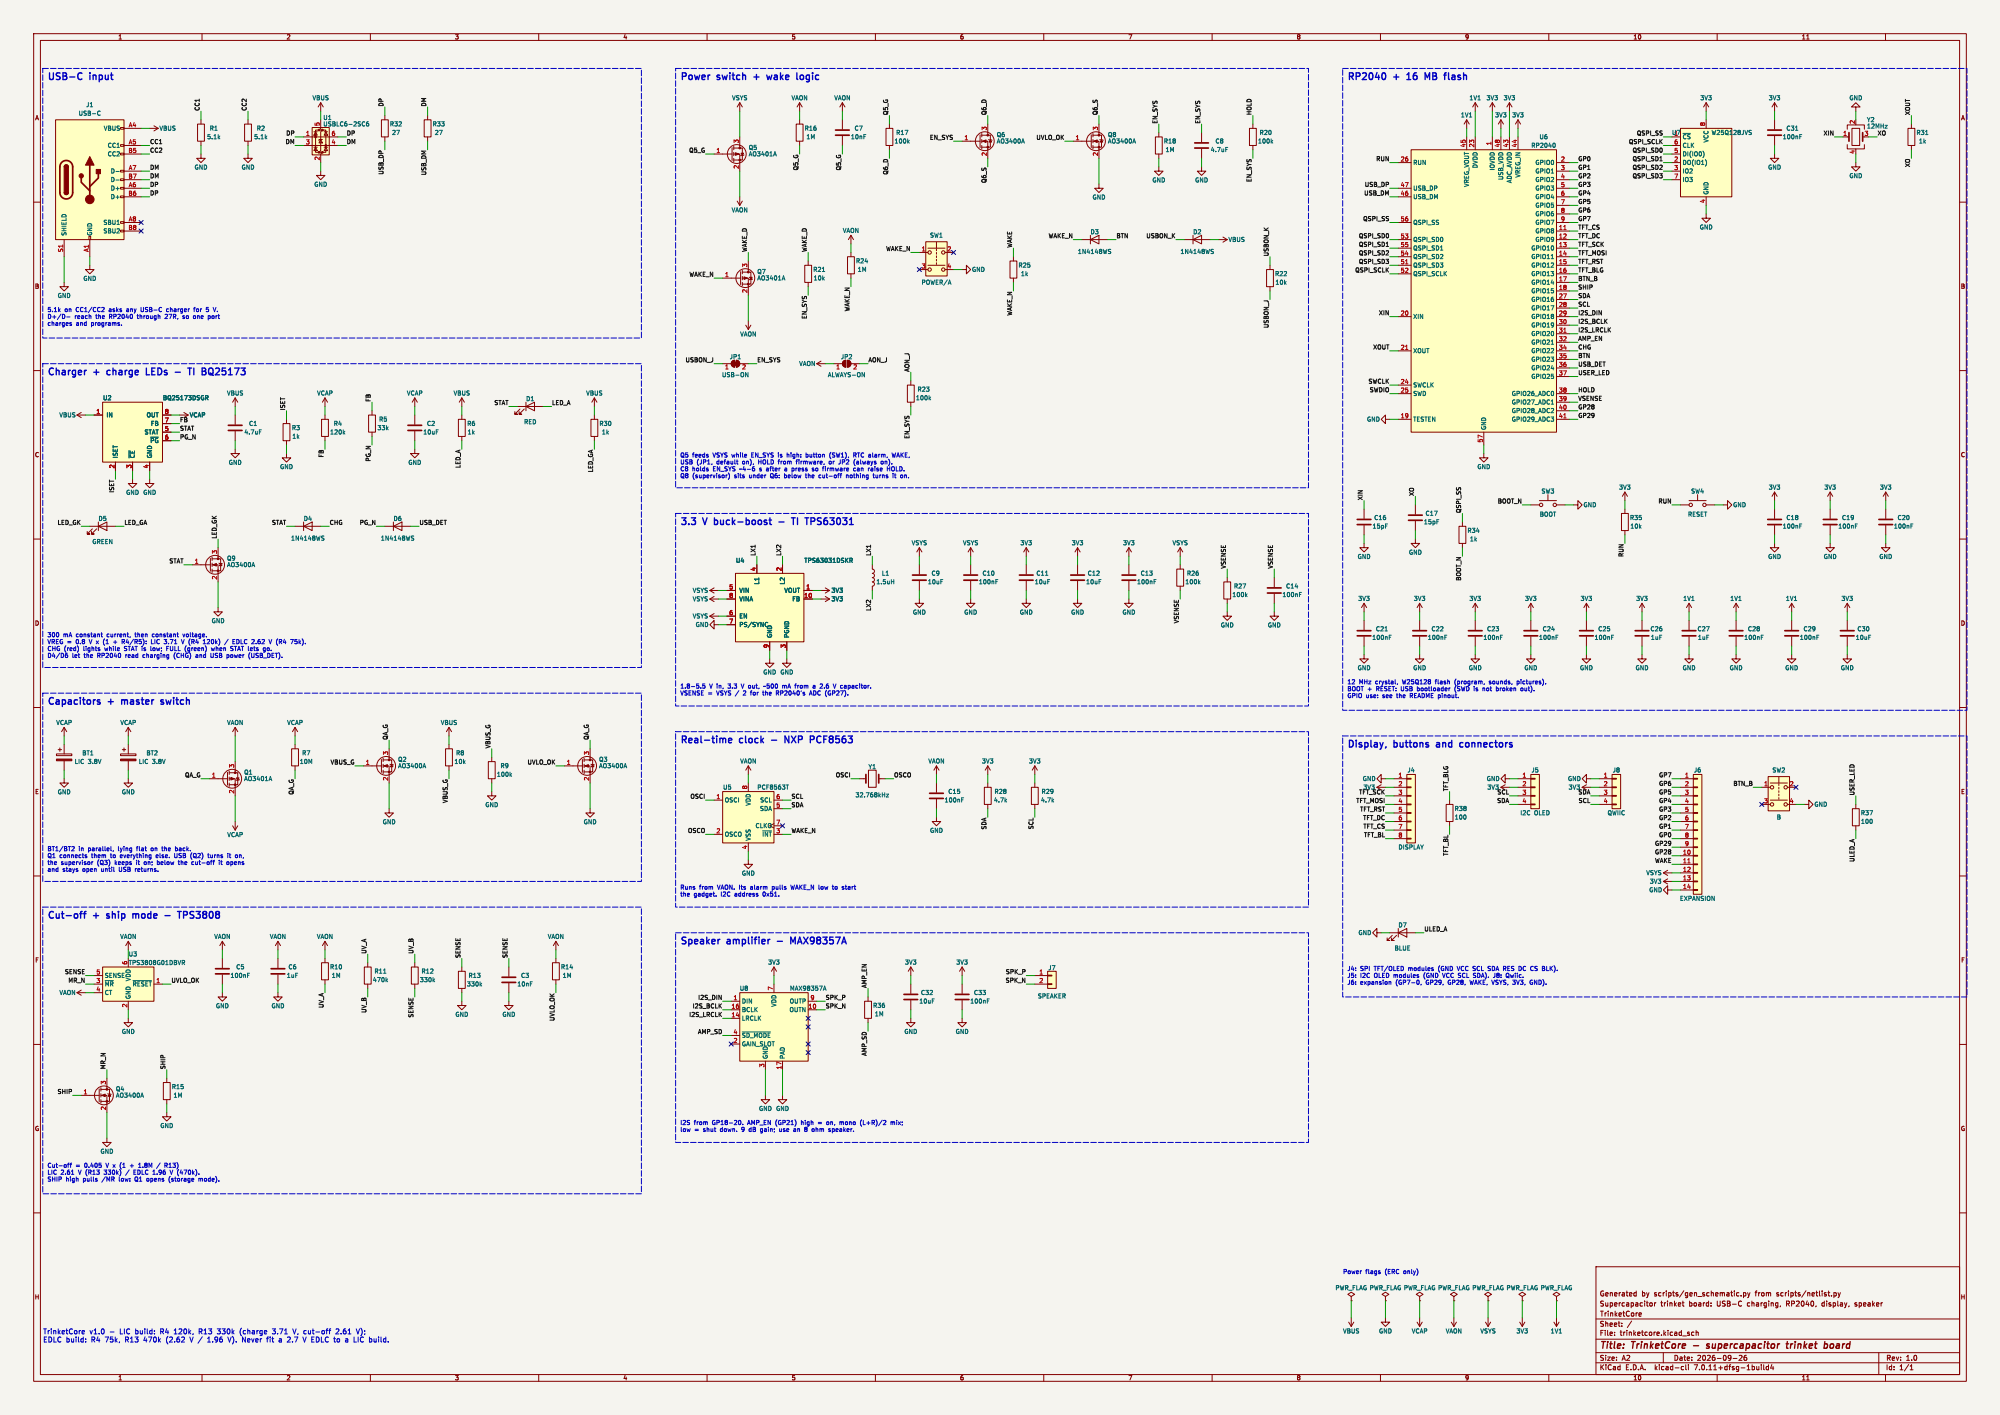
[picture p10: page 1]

Charger + charge LEDs - TI BQ25173

4 STAT 5 ~{PG}6 FB 7 OUT 8 U2 BQ25173DSGR

4 STAT 5 ~{PG}6 FB 7 OUT 8 VCAP

4 VIN 5 EN 6 PS/SYNC 7 VINA 8 GND

4 SDA 5 SCL 6 CLKO 7 VDD

2 ~{MR} 3 CT 4 SENSE 5 VDD

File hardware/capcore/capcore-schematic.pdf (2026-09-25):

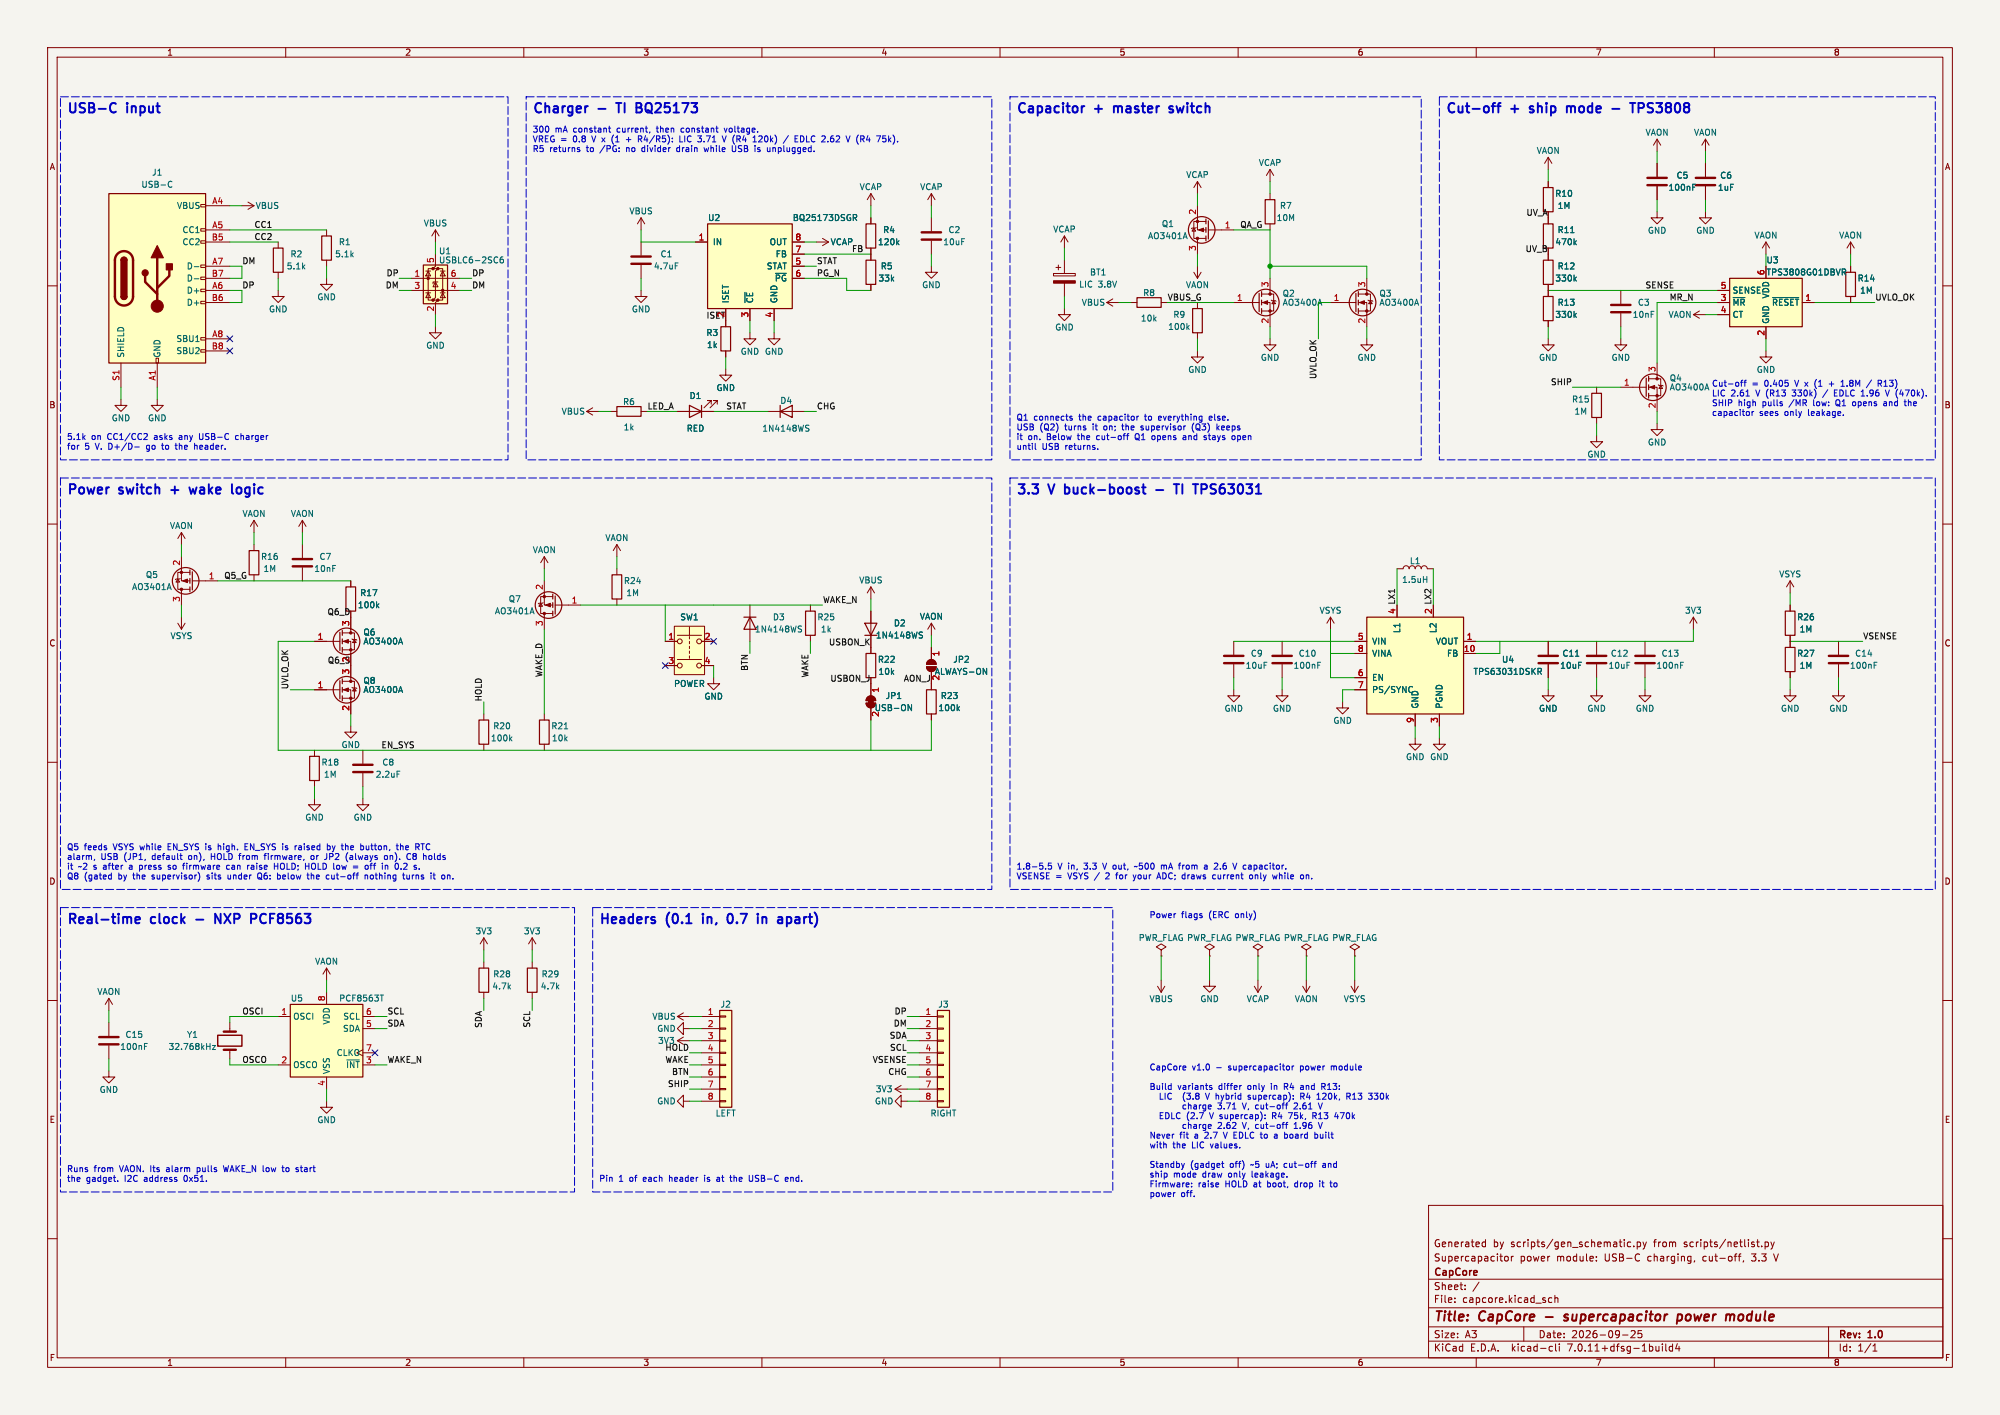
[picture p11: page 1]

4 STAT 5 ~{PG}6 FB 7 OUT 8 U2 BQ25173DSGR

4 STAT 5 ~{PG}6 FB 7 OUT 8 R5

5.1k on CC1/CC2 asks any USB-C charger
until USB returns. Q5 feeds VSYS while EN_SYS is high. EN_SYS is raised by the button, the RTC

Power switch + wake logic

4 VIN 5 EN 6 PS/SYNC 7 VINA 8 GND

4 SDA 5 SCL 6 CLKO 7 VDD

Pin 1 of each header is at the USB-C end.

ship mode draw only leakage. Firmware: raise HOLD at boot, drop it to

File: capcore.kicad_sch Sheet: / CapCore

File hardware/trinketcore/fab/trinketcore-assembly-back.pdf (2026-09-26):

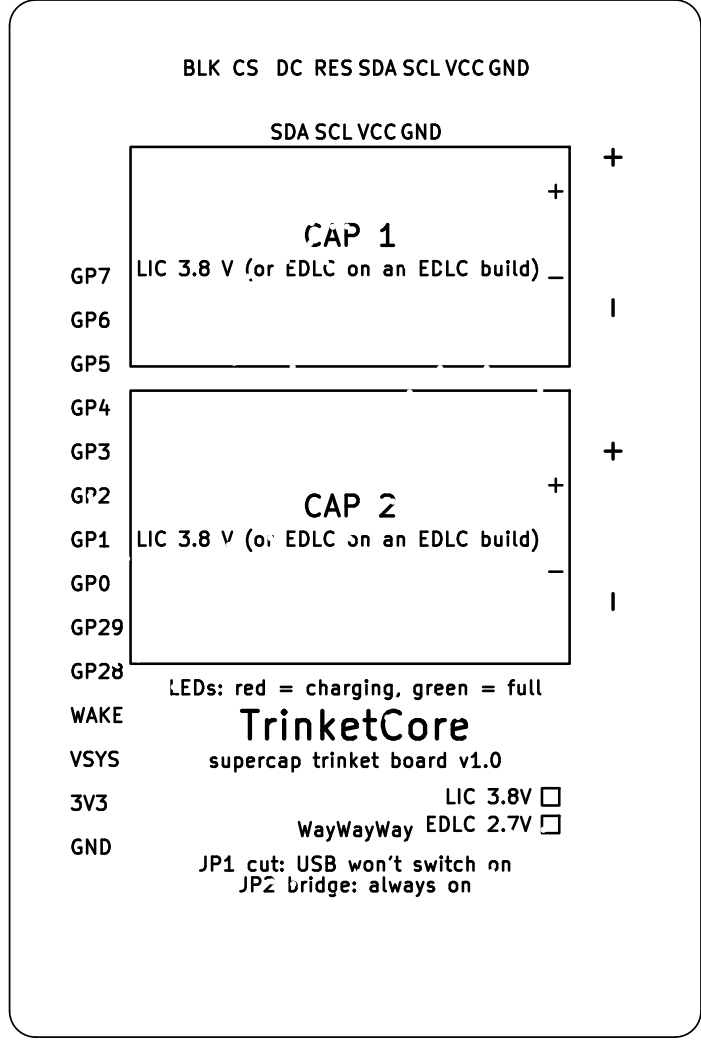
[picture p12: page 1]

JP1 cut: USB won't switch on VCC WAKE

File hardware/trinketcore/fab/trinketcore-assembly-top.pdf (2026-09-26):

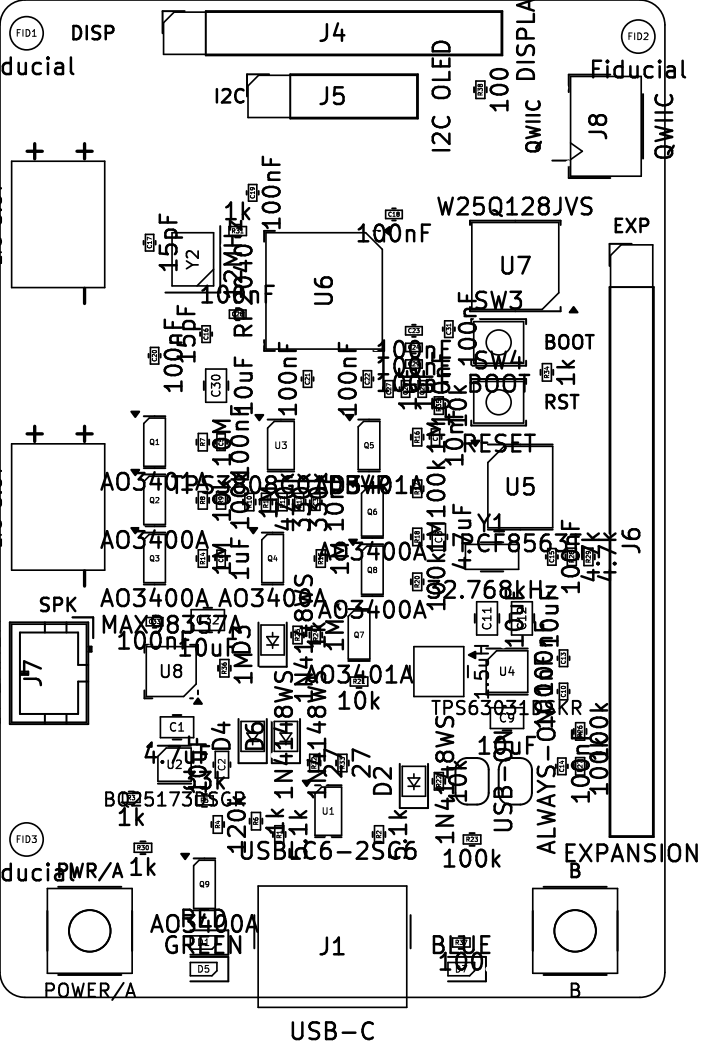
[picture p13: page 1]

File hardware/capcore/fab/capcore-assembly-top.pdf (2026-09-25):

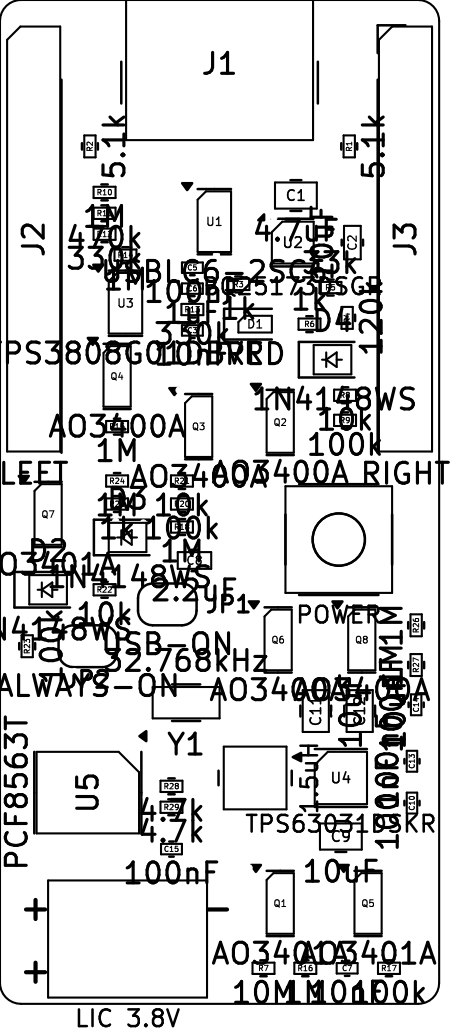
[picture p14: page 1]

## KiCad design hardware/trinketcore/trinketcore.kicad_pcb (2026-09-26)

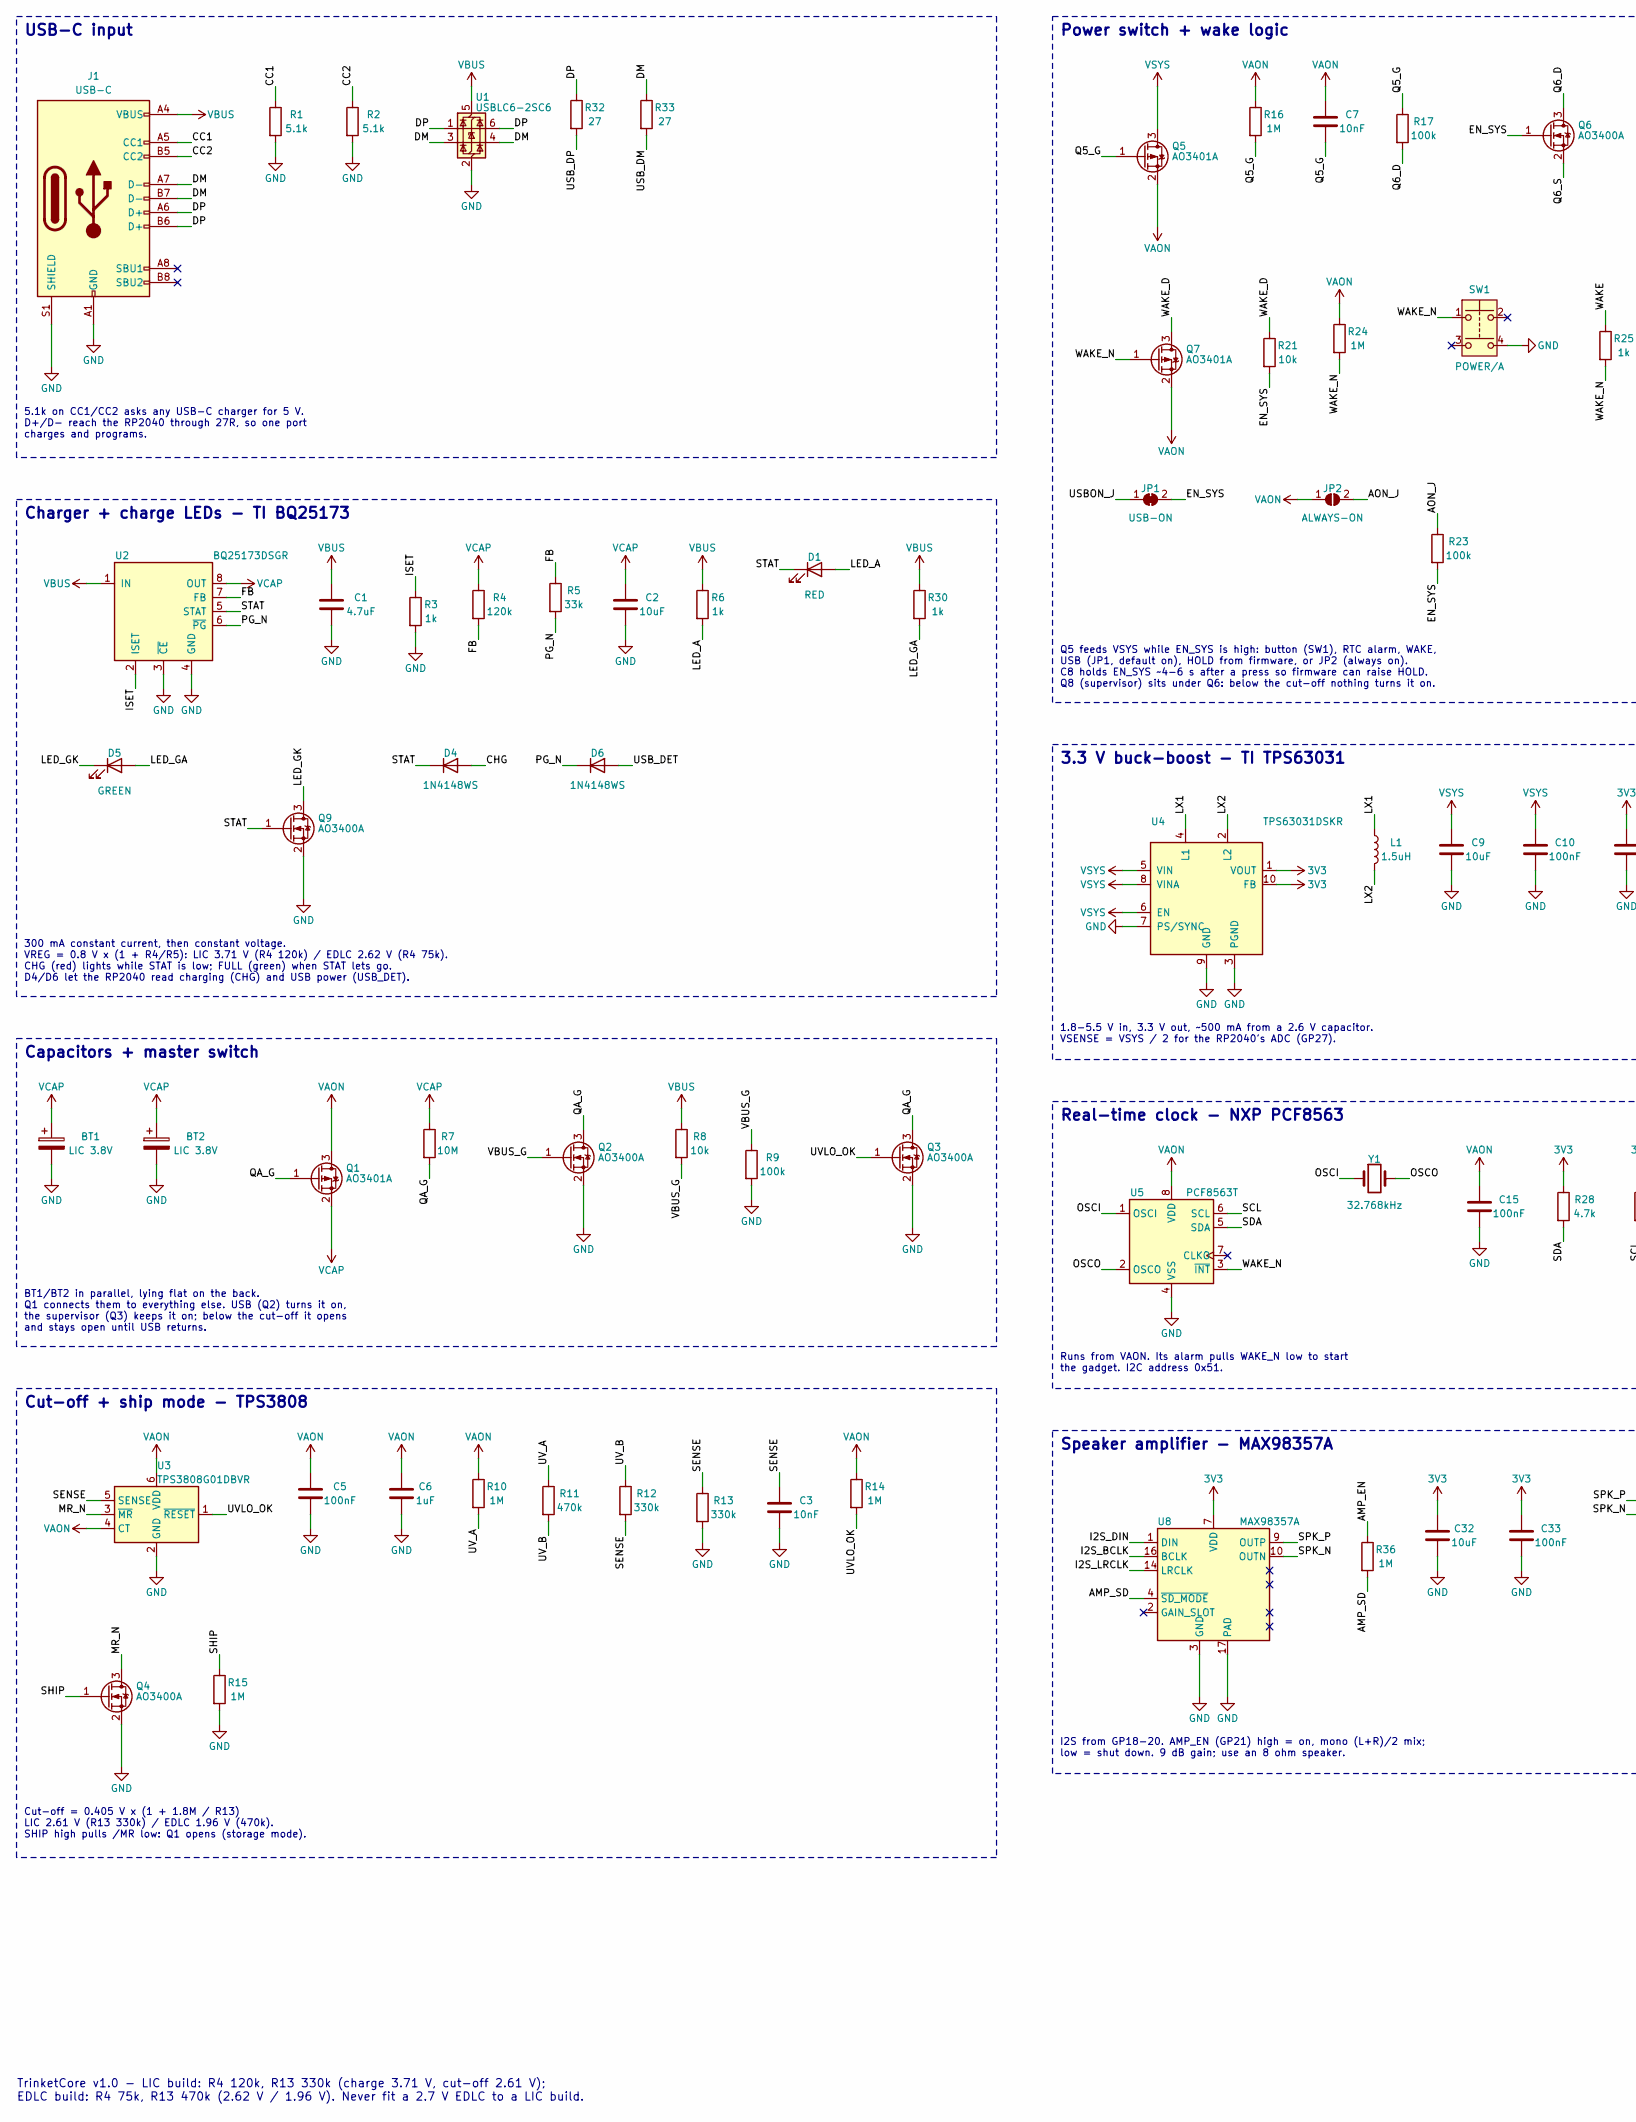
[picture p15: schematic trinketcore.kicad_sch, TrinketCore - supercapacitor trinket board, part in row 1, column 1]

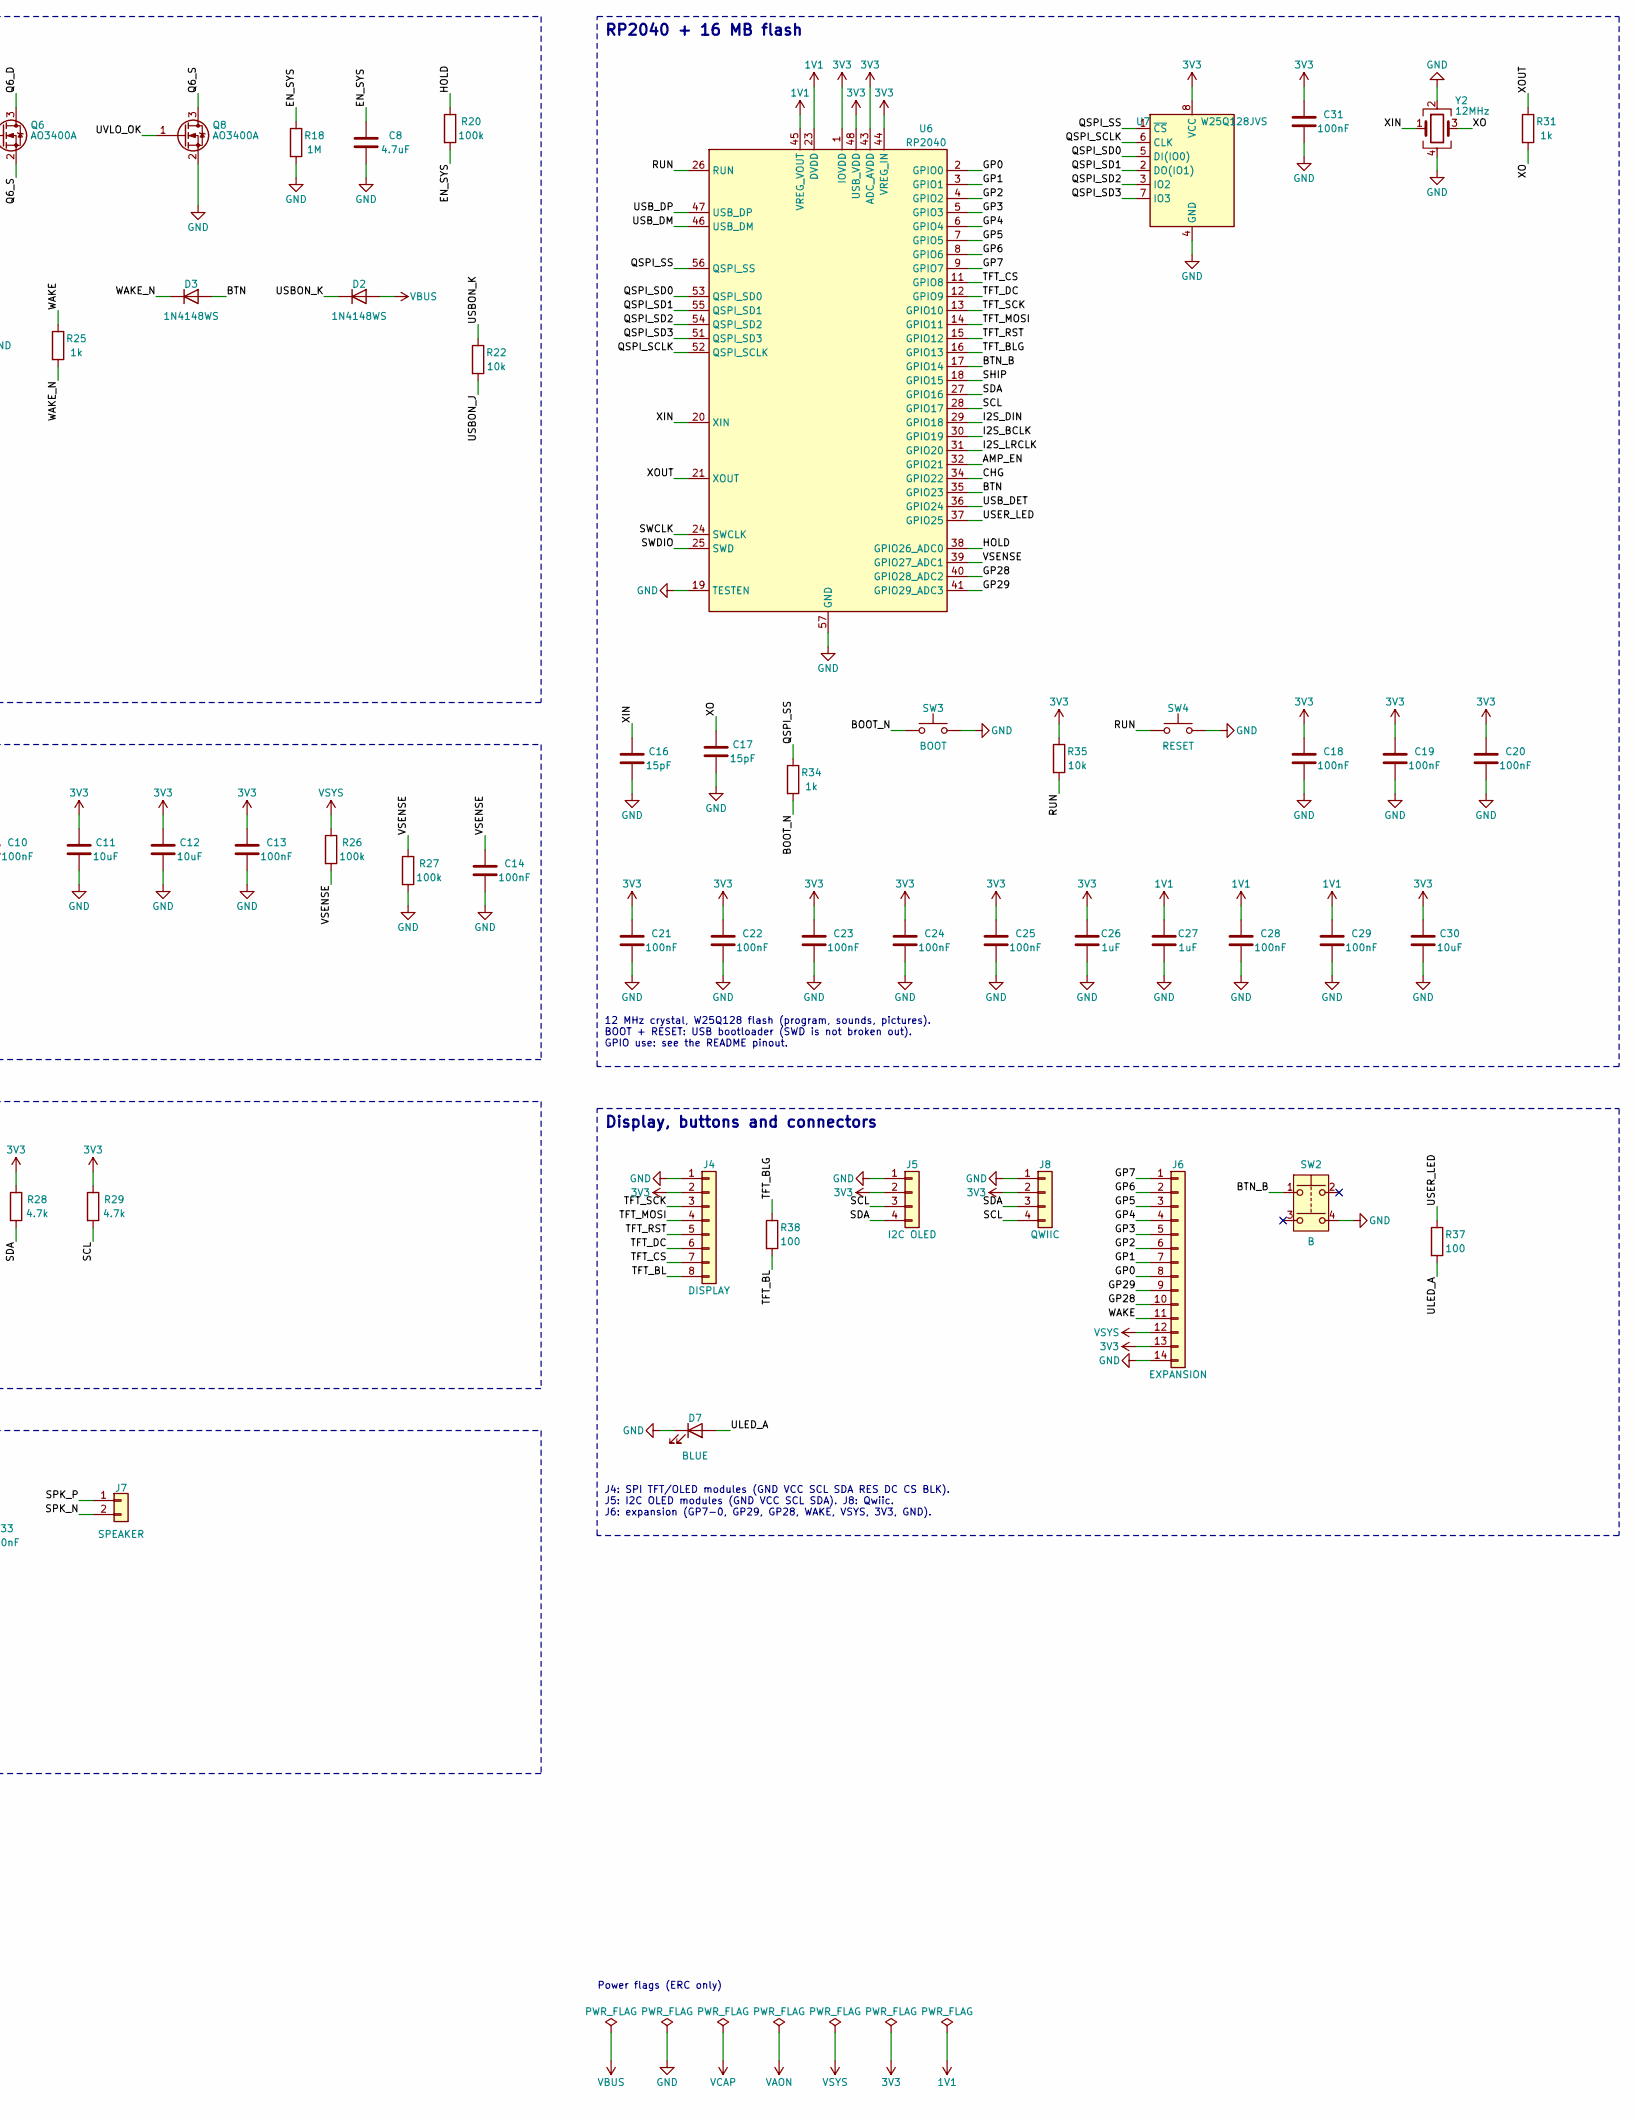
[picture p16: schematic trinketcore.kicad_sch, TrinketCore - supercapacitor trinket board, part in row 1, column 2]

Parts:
BT1, BT2: LIC 3.8V; Supercap_Pads
C1: 4.7uF; C_0805_2012Metric; MPN CL21A475KAQNNNE
C2: 10uF; C_0603_1608Metric; MPN CL10A106KP8NNNC
C3, C7: 10nF; C_0402_1005Metric; MPN CL05B103KB5NNNC
C5, C10, C13, C14, C15, C18, C19, C20, C21, C22, C23, C24, C25, C28, C29, C31, C33: 100nF; C_0402_1005Metric; MPN CL05B104KO5NNNC
C6, C26, C27: 1uF; C_0402_1005Metric; MPN CL05A105KA5NQNC
C8: 4.7uF; C_0603_1608Metric; MPN CL10A475KO8NNNC
C9, C11, C12, C30, C32: 10uF; C_0805_2012Metric; MPN CL21A106KAYNNNE
C16, C17: 15pF; C_0402_1005Metric; MPN CL05C150JB5NNNC
D1: RED; LED_0603_1608Metric; MPN LTST-C191KRKT
D2, D3, D4, D6: 1N4148WS; D_SOD-323; MPN 1N4148WS-7-F
D5: GREEN; LED_0603_1608Metric; MPN LTST-C191KGKT
D7: BLUE; LED_0603_1608Metric; MPN LTST-C191TBKT
J1: USB-C; USB_C_Receptacle_HRO_TYPE-C-31-M-12; MPN TYPE-C-31-M-12
J4: DISPLAY; PinSocket_1x08_P2.54mm_Vertical
J5: I2C OLED; PinSocket_1x04_P2.54mm_Vertical
J6: EXPANSION; PinHeader_1x14_P2.54mm_Vertical
J7: SPEAKER; JST_PH_B2B-PH-K_1x02_P2.00mm_Vertical; MPN B2B-PH-K-S(LF)(SN)
J8: QWIIC; JST_SH_SM04B-SRSS-TB_1x04-1MP_P1.00mm_Horizontal; MPN SM04B-SRSS-TB(LF)(SN)
JP1: USB-ON; SolderJumper-2_P1.3mm_Bridged_RoundedPad1.0x1.5mm
JP2: ALWAYS-ON; SolderJumper-2_P1.3mm_Open_RoundedPad1.0x1.5mm
L1: 1.5uH; L_3015_Universal; MPN NR3015T1R5N
Q1, Q5, Q7: AO3401A; SOT-23; MPN AO3401A
Q2, Q3, Q4, Q6, Q8, Q9: AO3400A; SOT-23; MPN AO3400A
R1, R2: 5.1k; R_0402_1005Metric; MPN RC0402FR-075K1L
R3, R6, R25, R30, R31, R34: 1k; R_0402_1005Metric; MPN RC0402FR-071KL
R4: 120k; R_0402_1005Metric; MPN RC0402FR-07120KL
R5: 33k; R_0402_1005Metric; MPN RC0402FR-0733KL
R7: 10M; R_0402_1005Metric; MPN RC0402FR-0710ML
R8, R21, R22, R35: 10k; R_0402_1005Metric; MPN RC0402FR-0710KL
R9, R17, R20, R23, R26, R27: 100k; R_0402_1005Metric; MPN RC0402FR-07100KL
R10, R14, R15, R16, R18, R24, R36: 1M; R_0402_1005Metric; MPN RC0402FR-071ML
R11: 470k; R_0402_1005Metric; MPN RC0402FR-07470KL
R12, R13: 330k; R_0402_1005Metric; MPN RC0402FR-07330KL
R28, R29: 4.7k; R_0402_1005Metric; MPN RC0402FR-074K7L
R32, R33: 27; R_0402_1005Metric; MPN RC0402FR-0727RL
R37, R38: 100; R_0402_1005Metric; MPN RC0402FR-07100RL
SW1: POWER/A; SW_TS-1187A_5.1x5.1mm; MPN TS-1187A-B-A-B
SW2: B; SW_TS-1187A_5.1x5.1mm; MPN TS-1187A-B-A-B
SW3: BOOT; SW_SPST_B3U-1000P; MPN B3U-1000P
SW4: RESET; SW_SPST_B3U-1000P; MPN B3U-1000P
U1: USBLC6-2SC6; SOT-23-6; MPN USBLC6-2SC6
U2: BQ25173DSGR; WSON-8-1EP_2x2mm_P0.5mm_EP0.9x1.6mm_Vias0.3; MPN BQ25173DSGR
U3: TPS3808G01DBVR; SOT-23-6; MPN TPS3808G01DBVR
U4: TPS63031DSKR; WSON-10-1EP_2.5x2.5mm_P0.5mm_EP1.2x2mm_Vias0.3; MPN TPS63031DSKR
U5: PCF8563T; SOIC-8_3.9x4.9mm_P1.27mm; MPN PCF8563T/5,518
U6: RP2040; QFN-56-1EP_7x7mm_P0.4mm_EP3.2x3.2mm_Vias0.3; MPN RP2040
U7: W25Q128JVS; SOIC-8_5.23x5.23mm_P1.27mm; MPN W25Q128JVSIQ
U8: MAX98357A; TQFN-16-1EP_3x3mm_P0.5mm_EP1.23x1.23mm_Vias0.3; MPN MAX98357AETE+T
Y1: 32.768kHz; Crystal_SMD_3215-2Pin_3.2x1.5mm; MPN Q13FC1350000400
Y2: 12MHz; Crystal_SMD_3225-4Pin_3.2x2.5mm; MPN ABM8-272-T3

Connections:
1V1: C27.1, C28.1, C29.1, U6.23 (DVDD), U6.45 (VREG_VOUT), U6.50 (DVDD)
3V3: C11.1, C12.1, C13.1, C18.1, C19.1, C20.1, C21.1, C22.1, C23.1, C24.1, C25.1, C26.1, C30.1, C31.1, C32.1, C33.1, J4.2, J5.2, J6.13, J8.2, R28.1, R29.1, R35.1, U4.1 (VOUT), U4.10 (FB), U6.1 (IOVDD), U6.10 (IOVDD), U6.22 (IOVDD), U6.33 (IOVDD), U6.42 (IOVDD), U6.43 (ADC_AVDD), U6.44 (VREG_IN), U6.48 (USB_VDD), U6.49 (IOVDD), U7.8 (VCC), U8.7 (VDD), U8.8 (VDD)
AMP_EN: R36.1, U6.32 (GPIO21)
AMP_SD: R36.2, U8.4 (~SD_MODE)
AON_J: JP2.2 (B), R23.1
BOOT_N: R34.2, SW3.1
BTN: D3.2 (A), U6.35 (GPIO23)
BTN_B: SW2.1, U6.17 (GPIO14)
CC1: J1.A5 (CC1), R1.1
CC2: J1.B5 (CC2), R2.1
CHG: D4.2 (A), U6.34 (GPIO22)
DM: J1.A7 (D-), J1.B7 (D-), R33.1, U1.3 (I/O2), U1.4 (I/O2)
DP: J1.A6 (D+), J1.B6 (D+), R32.1, U1.1 (I/O1), U1.6 (I/O1)
EN_SYS: C8.1, JP1.2 (B), Q6.1 (G), R18.1, R20.2, R21.2, R23.2
FB: R4.2, R5.1, U2.7 (FB)
GND: BT1.2, BT2.2, C1.2, C2.2, C3.2, C5.2, C6.2, C8.2, C9.2, C10.2, C11.2, C12.2, C13.2, C14.2, C15.2, C16.2, C17.2, C18.2, C19.2, C20.2, C21.2, C22.2, C23.2, C24.2, C25.2, C26.2, C27.2, C28.2, C29.2, C30.2, C31.2, C32.2, C33.2, D7.1 (K), J1.A1 (GND), J1.A12 (GND), J1.B1 (GND), J1.B12 (GND), J1.S1 (SHIELD), J4.1, J5.1, J6.14, J8.1, Q2.2 (S), Q3.2 (S), Q4.2 (S), Q8.2 (S), Q9.2 (S), R1.2, R2.2, R3.2, R9.2, R13.2, R15.2, R18.2, R27.2, SW1.4, SW2.4, SW3.2, SW4.2, U1.2 (GND), U2.3 (~CE), U2.4 (GND), U2.9 (EP), U3.2 (GND), U4.3 (PGND), U4.7 (PS/SYNC), U4.9 (GND), U4.11 (EP), U5.4 (VSS), U6.19 (TESTEN), U6.57 (GND), U7.4 (GND), U8.3 (GND), U8.11 (GND), U8.15 (GND), U8.17 (PAD), Y2.2, Y2.4
GP0: J6.8, U6.2 (GPIO0)
GP1: J6.7, U6.3 (GPIO1)
GP2: J6.6, U6.4 (GPIO2)
GP3: J6.5, U6.5 (GPIO3)
GP4: J6.4, U6.6 (GPIO4)
GP5: J6.3, U6.7 (GPIO5)
GP6: J6.2, U6.8 (GPIO6)
GP7: J6.1, U6.9 (GPIO7)
GP28: J6.10, U6.40 (GPIO28_ADC2)
GP29: J6.9, U6.41 (GPIO29_ADC3)
HOLD: R20.1, U6.38 (GPIO26_ADC0)
I2S_BCLK: U6.30 (GPIO19), U8.16 (BCLK)
I2S_DIN: U6.29 (GPIO18), U8.1 (DIN)
I2S_LRCLK: U6.31 (GPIO20), U8.14 (LRCLK)
ISET: R3.1, U2.2 (ISET)
LED_A: D1.2 (A), R6.2
LED_GA: D5.2 (A), R30.2
LED_GK: D5.1 (K), Q9.3 (D)
LX1: L1.1, U4.4 (L1)
LX2: L1.2, U4.2 (L2)
MR_N: Q4.3 (D), U3.3 (~MR)
OSCI: U5.1 (OSCI), Y1.1
OSCO: U5.2 (OSCO), Y1.2
PG_N: D6.1 (K), R5.2, U2.6 (~PG)
Q5_G: C7.2, Q5.1 (G), R16.2, R17.1
Q6_D: Q6.3 (D), R17.2
Q6_S: Q6.2 (S), Q8.3 (D)
QA_G: Q1.1 (G), Q2.3 (D), Q3.3 (D), R7.2
QSPI_SCLK: U6.52 (QSPI_SCLK), U7.6 (CLK)
QSPI_SD0: U6.53 (QSPI_SD0), U7.5 (DI(IO0))
QSPI_SD1: U6.55 (QSPI_SD1), U7.2 (DO(IO1))
QSPI_SD2: U6.54 (QSPI_SD2), U7.3 (IO2)
QSPI_SD3: U6.51 (QSPI_SD3), U7.7 (IO3)
QSPI_SS: R34.1, U6.56 (QSPI_SS), U7.1 (~CS)
RUN: R35.2, SW4.1, U6.26 (RUN)
SCL: J5.3, J8.4, R29.2, U5.6 (SCL), U6.28 (GPIO17)
SDA: J5.4, J8.3, R28.2, U5.5 (SDA), U6.27 (GPIO16)
SENSE: C3.1, R12.2, R13.1, U3.5 (SENSE)
SHIP: Q4.1 (G), R15.1, U6.18 (GPIO15)
SPK_N: J7.2, U8.10 (OUTN)
SPK_P: J7.1, U8.9 (OUTP)
STAT: D1.1 (K), D4.1 (K), Q9.1 (G), U2.5 (STAT)
SWCLK: U6.24 (SWCLK)
SWDIO: U6.25 (SWD)
TFT_BL: J4.8, R38.2
TFT_BLG: R38.1, U6.16 (GPIO13)
TFT_CS: J4.7, U6.11 (GPIO8)
TFT_DC: J4.6, U6.12 (GPIO9)
TFT_MOSI: J4.4, U6.14 (GPIO11)
TFT_RST: J4.5, U6.15 (GPIO12)
TFT_SCK: J4.3, U6.13 (GPIO10)
ULED_A: D7.2 (A), R37.2
USBON_J: JP1.1 (A), R22.2
USBON_K: D2.1 (K), R22.1
USB_DET: D6.2 (A), U6.36 (GPIO24)
USB_DM: R33.2, U6.46 (USB_DM)
USB_DP: R32.2, U6.47 (USB_DP)
USER_LED: R37.1, U6.37 (GPIO25)
UVLO_OK: Q3.1 (G), Q8.1 (G), R14.2, U3.1 (~RESET)
UV_A: R10.2, R11.1
UV_B: R11.2, R12.1
VAON: C5.1, C6.1, C7.1, C15.1, JP2.1 (A), Q1.3 (D), Q5.2 (S), Q7.2 (S), R10.1, R14.1, R16.1, R24.1, U3.4 (CT), U3.6 (VDD), U5.8 (VDD)
VBUS: C1.1, D2.2 (A), J1.A4 (VBUS), J1.A9 (VBUS), J1.B4 (VBUS), J1.B9 (VBUS), R6.1, R8.1, R30.1, U1.5 (VBUS), U2.1 (IN)
VBUS_G: Q2.1 (G), R8.2, R9.1
VCAP: BT1.1, BT2.1, C2.1, Q1.2 (S), R4.1, R7.1, U2.8 (OUT)
VSENSE: C14.1, R26.2, R27.1, U6.39 (GPIO27_ADC1)
VSYS: C9.1, C10.1, J6.12, Q5.3 (D), R26.1, U4.5 (VIN), U4.6 (EN), U4.8 (VINA)
WAKE: J6.11, R25.1
WAKE_D: Q7.3 (D), R21.1
WAKE_N: D3.1 (K), Q7.1 (G), R24.2, R25.2, SW1.1, U5.3 (~INT)
XIN: C16.1, U6.20 (XIN), Y2.1
XO: C17.1, R31.2, Y2.3
XOUT: R31.1, U6.21 (XOUT)

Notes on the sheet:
USB-C input
5.1k on CC1/CC2 asks any USB-C charger for 5 V. D+/D- reach the RP2040 through 27R, so one port charges and programs.
Charger + charge LEDs - TI BQ25173
300 mA constant current, then constant voltage. VREG = 0.8 V x (1 + R4/R5): LIC 3.71 V (R4 120k) / EDLC 2.62 V (R4 75k). CHG (red) lights while STAT is low; FULL (green) when STAT lets go. D4/D6 let the RP2040 read charging (CHG) and USB power (USB_DET).
Capacitors + master switch
BT1/BT2 in parallel, lying flat on the back. Q1 connects them to everything else. USB (Q2) turns it on, the supervisor (Q3) keeps it on; below the cut-off it opens and stays open until USB returns.
Cut-off + ship mode - TPS3808
Cut-off = 0.405 V x (1 + 1.8M / R13) LIC 2.61 V (R13 330k) / EDLC 1.96 V (470k). SHIP high pulls /MR low: Q1 opens (storage mode).
Power switch + wake logic
Q5 feeds VSYS while EN_SYS is high: button (SW1), RTC alarm, WAKE, USB (JP1, default on), HOLD from firmware, or JP2 (always on). C8 holds EN_SYS ~4-6 s after a press so firmware can raise HOLD. Q8 (supervisor) sits under Q6: below the cut-off nothing turns it on.
3.3 V buck-boost - TI TPS63031
1.8-5.5 V in, 3.3 V out, ~500 mA from a 2.6 V capacitor. VSENSE = VSYS / 2 for the RP2040's ADC (GP27).
Real-time clock - NXP PCF8563
Runs from VAON. Its alarm pulls WAKE_N low to start the gadget. I2C address 0x51.
Speaker amplifier - MAX98357A
I2S from GP18-20. AMP_EN (GP21) high = on, mono (L+R)/2 mix; low = shut down. 9 dB gain; use an 8 ohm speaker.
RP2040 + 16 MB flash
12 MHz crystal, W25Q128 flash (program, sounds, pictures). BOOT + RESET: USB bootloader (SWD is not broken out). GPIO use: see the README pinout.
Display, buttons and connectors
J4: SPI TFT/OLED modules (GND VCC SCL SDA RES DC CS BLK). J5: I2C OLED modules (GND VCC SCL SDA). J8: Qwiic. J6: expansion (GP7-0, GP29, GP28, WAKE, VSYS, 3V3, GND).
Power flags (ERC only)
TrinketCore v1.0 - LIC build: R4 120k, R13 330k (charge 3.71 V, cut-off 2.61 V); EDLC build: R4 75k, R13 470k (2.62 V / 1.96 V). Never fit a 2.7 V EDLC to a LIC build.

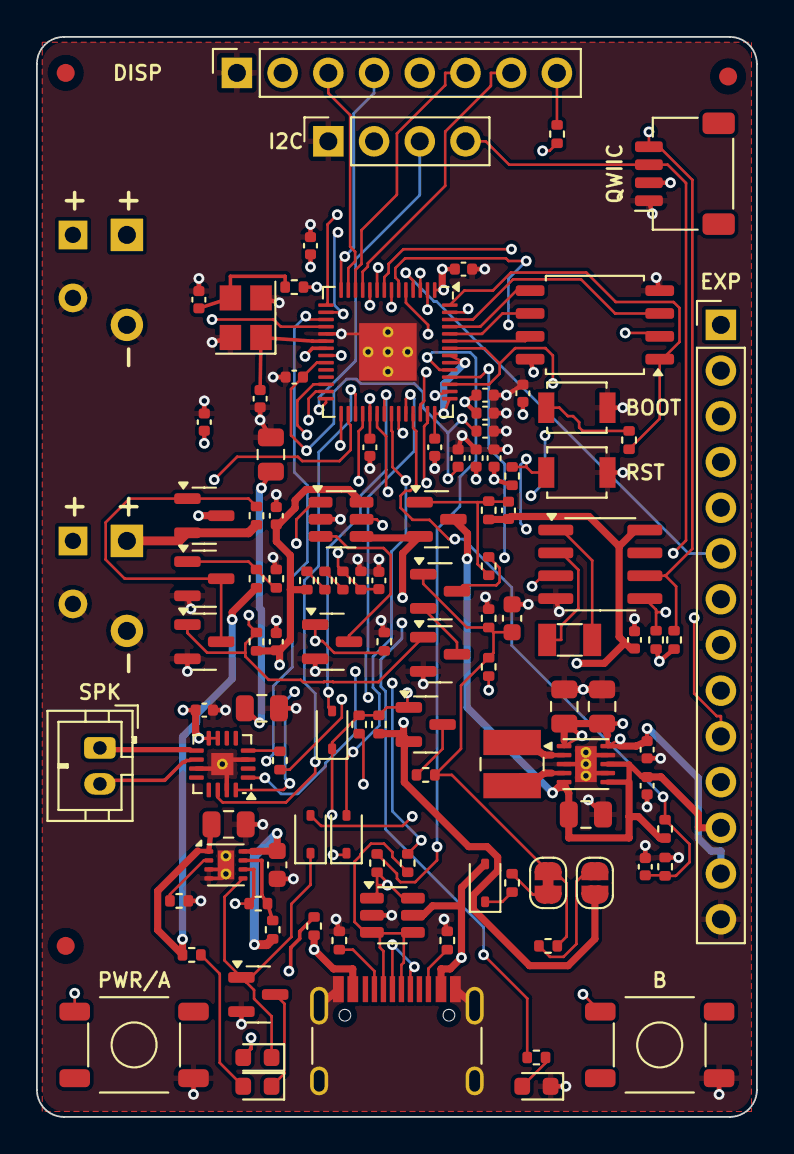
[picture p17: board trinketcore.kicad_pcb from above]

Board: 4 copper layers, 40.0 x 60.0 mm, 113 parts (0 on the bottom side), 87 nets.

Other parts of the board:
FID1, FID2, FID3: Fiducial; Fiducial_1mm_Mask2mm

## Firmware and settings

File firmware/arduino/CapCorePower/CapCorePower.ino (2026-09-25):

// CapCorePower.ino: power management for a gadget running on a CapCore board.
//
// Shows everything the board expects from firmware:
//   * raise HOLD immediately so the gadget stays on after a button tap,
//   * clear the RTC flags (a pending alarm/timer holds power on and makes BTN read low),
//   * read the capacitor voltage and charge status,
//   * long-press the button to turn off,
//   * sleep for N minutes and let the RTC timer wake the gadget up again,
//   * ship mode for storage.
//
// Written for any Arduino core with Wire (RP2040, ESP32, SAMD, nRF52, AVR at 3.3 V).
// Change the pin numbers below to match your wiring.

#include <Wire.h>

// ---- wiring --------------------------------------------------------------
const int PIN_HOLD = 2;      // CapCore J2-4, output: high = stay on
const int PIN_BTN = 3;       // CapCore J2-6, input with pull-up: low = button pressed
const int PIN_SHIP = 6;      // CapCore J2-7, output: pulse high = ship mode
const int PIN_CHG = 7;       // CapCore J3-6, input with pull-up: low = charging
const int PIN_VSENSE = A0;   // CapCore J3-5, analog: capacitor voltage / 2
// SDA/SCL (CapCore J3-3/J3-4) go to your board's default I2C pins.

// ---- capacitor -----------------------------------------------------------
// LIC build: charges to 3.71 V, hardware cut-off at 2.61 V.
// EDLC build: charges to 2.62 V, hardware cut-off at 1.96 V.
const float V_FULL = 3.71;
const float V_EMPTY = 2.61;
const float V_SHUTDOWN = 2.75;   // power off cleanly a little above the hard cut-off

const float ADC_VREF = 3.3;      // CapCore's 3V3 rail feeds the MCU (ESP32: calibrate)
int adcBits = 10;                // raised to 12 below where the core supports it

// ---- PCF8563 real-time clock (I2C address 0x51) --------------------------
const uint8_t RTC_ADDR = 0x51;
const uint8_t REG_CTRL2 = 0x01;   // bit3 AF, bit2 TF, bit1 AIE, bit0 TIE
const uint8_t REG_CLKOUT = 0x0D;  // bit7 FE: 0 = CLKOUT off (saves ~1 uA)
const uint8_t REG_TIMER_CTRL = 0x0E;
const uint8_t REG_TIMER = 0x0F;

bool wokeByRtc = false;

uint8_t rtcRead(uint8_t reg) {
  Wire.beginTransmission(RTC_ADDR);
  Wire.write(reg);
  Wire.endTransmission(false);
  Wire.requestFrom(RTC_ADDR, (uint8_t)1);
  return Wire.available() ? Wire.read() : 0;
}

void rtcWrite(uint8_t reg, uint8_t value) {
  Wire.beginTransmission(RTC_ADDR);
  Wire.write(reg);
  Wire.write(value);
  Wire.endTransmission();
}

// ---- CapCore helpers ------------------------------------------------------
float capVolts() {
  // VSENSE sits behind 1 Mohm + 1 Mohm and a 100 nF capacitor; one slow read is fine.
  long sum = 0;
  for (int i = 0; i < 8; i++) sum += analogRead(PIN_VSENSE);
  float vsense = (sum / 8.0) * ADC_VREF / ((1 << adcBits) - 1);
  return 2.0 * vsense;
}

int capPercent() {
  // Energy left between the cut-off and full, which is what runtime depends on.
  float v = constrain(capVolts(), V_EMPTY, V_FULL);
  return (int)(100.0 * (v * v - V_EMPTY * V_EMPTY) / (V_FULL * V_FULL - V_EMPTY * V_EMPTY));
}

bool charging() { return digitalRead(PIN_CHG) == LOW; }
bool buttonDown() { return digitalRead(PIN_BTN) == LOW; }

void powerOff() {
  // The power switch stays on while the button is held: wait for release first.
  while (buttonDown()) delay(10);
  digitalWrite(PIN_HOLD, LOW);
  delay(3000);
  // Still running? USB is plugged in with jumper JP1 bridged (or JP2 is bridged),
  // which keeps the gadget on. Idle quietly until that changes.
  while (true) {
    delay(1000);
    if (buttonDown()) {            // a press brings us back to life
      digitalWrite(PIN_HOLD, HIGH);
      return;
    }
  }
}

void sleepMinutes(uint8_t minutes) {
  // PCF8563 countdown timer at 1/60 Hz. When it expires, TF pulls /INT low,
  // which switches CapCore back on.
  rtcWrite(REG_TIMER_CTRL, 0x00);   // stop timer
  rtcWrite(REG_TIMER, minutes);
  rtcWrite(REG_CTRL2, 0x01);        // TIE = 1, clear AF/TF, level interrupt
  rtcWrite(REG_TIMER_CTRL, 0x83);   // TE = 1, source = 1/60 Hz
  powerOff();
}

void shipMode() {
  // Disconnects the capacitor completely; only USB power brings the board back.
  // Use before storing or posting a charged gadget.
  while (buttonDown()) delay(10);
  digitalWrite(PIN_SHIP, HIGH);
  delay(2000);
  digitalWrite(PIN_SHIP, LOW);      // only reached while USB is plugged in
}

// ---- sketch ----------------------------------------------------------------
void setup() {
  // 1) Keep the power on. Do this before anything slow.
  pinMode(PIN_HOLD, OUTPUT);
  digitalWrite(PIN_HOLD, HIGH);
  pinMode(PIN_SHIP, OUTPUT);
  digitalWrite(PIN_SHIP, LOW);
  pinMode(PIN_BTN, INPUT_PULLUP);
  pinMode(PIN_CHG, INPUT_PULLUP);
#if defined(ARDUINO_ARCH_RP2040) || defined(ARDUINO_ARCH_ESP32) || defined(ARDUINO_ARCH_SAMD) || \
    defined(ARDUINO_ARCH_NRF52) || defined(ARDUINO_ARCH_STM32)
  analogReadResolution(12);
  adcBits = 12;
#endif

  // 2) Find out why we woke up and release the RTC interrupt.
  Wire.begin();
  uint8_t ctrl2 = rtcRead(REG_CTRL2);
  wokeByRtc = ctrl2 & 0x0C;          // AF or TF set
  rtcWrite(REG_CTRL2, 0x00);         // clear flags, interrupts off -> releases WAKE
  rtcWrite(REG_CLKOUT, 0x00);        // clock output off
  rtcWrite(REG_TIMER_CTRL, 0x00);    // timer off

  Serial.begin(115200);
  delay(200);
  Serial.print(wokeByRtc ? "Woke from RTC timer. " : "Woke from button/USB. ");
  Serial.print("Capacitor ");
  Serial.print(capVolts(), 2);
  Serial.print(" V (");
  Serial.print(capPercent());
  Serial.println(charging() ? "%, charging)" : "%)");

  if (wokeByRtc) {
    // Example: an e-ink dashboard would refresh here, then sleep again.
    // updateDisplay();
    sleepMinutes(60);
  }
}

void loop() {
  static unsigned long pressedAt = 0;

  if (!charging() && capVolts() < V_SHUTDOWN) {
    Serial.println("Capacitor low, powering off. Plug in USB to charge.");
    // saveGame(); showChargeMeScreen();
    powerOff();
  }

  // Long-press (1.5 s) to turn off.
  if (buttonDown()) {
    if (pressedAt == 0) pressedAt = millis();
    if (millis() - pressedAt > 1500) {
      Serial.println("Bye");
      powerOff();
      pressedAt = 0;
    }
  } else {
    pressedAt = 0;
  }

  // Your game / music / display code goes here.
  delay(20);
}

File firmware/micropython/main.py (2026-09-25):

# Example main.py for a Raspberry Pi Pico (3V3_EN tied to GND) on a CapCore.
# Wiring: HOLD->GP2, BTN->GP3, SHIP->GP6, CHG->GP7, VSENSE->GP26, SDA->GP4, SCL->GP5.
from capcore import CapCore  # first import, so HOLD goes high within milliseconds

cc = CapCore()

import time  # noqa: E402

print("woke by", "RTC" if cc.woke_by_rtc else "button/USB")
print("capacitor %.2f V, %d %%%s" % (cc.cap_volts(), cc.percent(), ", charging" if cc.charging() else ""))

if cc.woke_by_rtc:
    # e-ink style: do the periodic job, then sleep again
    # update_display()
    cc.sleep_minutes(60)

pressed = None
while True:
    if cc.low():
        print("capacitor low: saving and powering off")
        cc.power_off()
    if cc.button():
        pressed = pressed or time.ticks_ms()
        if time.ticks_diff(time.ticks_ms(), pressed) > 1500:   # long press = off
            cc.power_off()
            pressed = None
    else:
        pressed = None
    # game / display / audio work goes here
    time.sleep_ms(20)

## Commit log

2026-09-25 Add CapCore supercapacitor power module and guides
    CapCore is a 21 x 48 mm, 4-layer KiCad 7 board that charges a
    supercapacitor from USB-C and powers small gadgets from it instead of
    a LiPo:
    - BQ25173 charger: 300 mA, 3.71 V for 3.8 V lithium-ion capacitors
    (LIC build) or 2.62 V for 2.7 V EDLCs (EDLC build; R4/R13 differ)
    - TPS3808 latching cut-off at 2.61 V / 1.96 V plus a ship mode; only
    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
    [capcore-B_Cu.gbl, capcore-B_Mask.gbs, capcore-B_Silkscreen.gbo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]
2026-09-26 Add TrinketCore all-in-one board (work in progress)
    TrinketCore is a 40 x 60 mm, 4-layer board for supercapacitor trinkets. It
    holds the capacitors, charges them over USB-C with red/green charge LEDs, and
    adds an RP2040 with 16 MB flash, a display socket that reads the charge level,
    a speaker amplifier, buttons and a wake-up clock. It reuses CapCore's power
    chain.
    This checkpoint has the netlist, schematic, placement, generator scripts,
    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
    [parts-list.csv, pcbway-bom-edlc.csv, pcbway-bom-lic.csv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]
2026-09-26 TrinketCore: pin map that routes without crossings (work in progress)
    The first autoroute left four connections open. Three of them were at the
    RP2040, where the expansion header took GP0..GP7 in the opposite order to the
    chip's pins, and USB_DET had to cross GP26/GP27 on the bottom row. The fourth
    was the speaker output, hemmed in by a ground via.
    - J6 now runs GP7..GP0, GP29, GP28 (pin 1 at the top), matching the pin order.
    - Bottom row: CHG GP22, button A GP23, USB_DET GP24, user LED GP25 (unchanged),
    HOLD GP26, VSENSE GP27, J6 analog GP28/GP29. Display DC/CS swap to GP9/GP8.
    - The amplifier's ground pins tie into its exposed pad instead of vias, and the
    RP2040 decoupling capacitors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
    [trinketcore.kicad_pcb, trinketcore.kicad_sch]
2026-09-26 Add e-ink tarot oracle; routing fixes (work in progress)
    - firmware/trinketcore/circuitpython/oracle: each press draws a random tarot
    card on a 1.54" SSD1681 e-paper module with a charge icon, then switches the
    board off (the card stays on screen with no power). make_cards.py turns card
    art into dithered 1-bit or black/white/red BMPs with the card's name.
    - trinketcore.EPD_BUSY: e-paper BUSY reads on J4's BLK pin (GP13).
    - READMEs and the design-method guide cover e-ink wiring and runtimes.
    - route_pcb.py: the finisher now sees open connections at SMD pads (the
    report parser only matched "PTH pad"), rips up tracks around boxed-in pads
    and routes them first, and 1V1 uses the default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
    [trinketcore.kicad_pcb, trinketcore.kicad_sch]
2026-09-26 TrinketCore: second-pass autoroute session (work in progress)
    The grid-router finish, pours and checks follow.
    Claude-Session: https://claude.ai/code/session_01V89YvrQurcttiFbkgcTPH9
    [trinketcore.kicad_pcb]
2026-09-26 TrinketCore: hand-routed crystal corner (work in progress)
    The crystal's 1 k resistor now faces the crystal, the XIN capacitor turns so
    its signal pad faces the crystal, and pin 22's capacitor moves onto the 3V3
    plane to clear the way. XIN and XO are drawn by hand on F.Cu and XOUT hops
    over XIN on In2.Cu, so the autorouter no longer has to untangle them.
    The board is being re-routed.
    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
    [trinketcore.kicad_pcb]
2026-09-26 TrinketCore: second-pass session for the new crystal corner (work in progress)
    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
    [trinketcore.kicad_pcb]
2026-09-26 TrinketCore: free the RP2040's top escape lanes (work in progress)
    C18 and C19, the decoupling capacitors for pins 1 and 10, move to the
    chip's corners on their own plane vias, so the GPIO and display tracks can
    leave the top row in parallel. The second Freerouting pass gets 40 passes
    and the grid router a wider rip-up radius. The board is being re-routed.
    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
    [trinketcore.kicad_pcb]
2026-09-26 TrinketCore: second-pass session, free escape lanes (work in progress)
    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
    [trinketcore.kicad_pcb]
2026-09-26 TrinketCore: fully routed board and PCBWay files
    The board now routes completely: two Freerouting passes, then the grid
    router closes the last three connections (LED_A and the speaker pair).
    KiCad DRC with PCBWay's limits reports no errors and no unconnected items,
    only the cosmetic USB-C footprint warning, and the schematic and PCB match
    netlist.py pin for pin (378 pins).
    - fab/: Gerbers + drill (zip for upload), PCBWay BOMs for the LIC and EDLC
    builds (44 lines, 102 parts), pick-and-place, assembly drawings, parts list.
    - trinketcore-schematic.pdf and board renders in docs/images.
    - check_netlist.py treats unnetted mechanical pads (J8's mounting tabs) as a
    note instead of a problem.
    -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
    [parts-list.csv, pcbway-bom-edlc.csv, pcbway-bom-lic.csv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]
2026-09-27 Add favicon, link previews and per-page meta; cache-bust images
    The logo only appeared on the home page. Every page now carries:
    - a favicon (P + sword monogram cut from the logo vector, .svg + .ico)
    and an apple-touch-icon;
    - og:/twitter: tags with a 1200x630 preview of the full lockup, so a
    shared link shows the logo instead of bare text;
    - its own meta description and canonical URL.
    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
2026-09-27 Fix phone layouts, no-JS Blog/Projects and keyboard start
    Blog / Projects
    - Phones: the reader's 1fr column grew to fit the one-line post strip,
    so the page was 786-945px wide on a 390px screen with text cut off at
    the right. minmax(0,1fr) keeps it on screen.
    - build_reader cut each sub-page at the first </div>, which dropped the
    closing tag of every .project wrapper (10 unclosed divs on Projects).
    Sub-pages are now matched to their own closing tag.
    - Lists had no styles and fell back to the pixel font at 16px with
    overlapping lines; they now match the body copy.
    - With JS off both pages showed two empty frames. The entries are no
    longer in a hidden div; CSS hides them only while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
2026-09-27 Store: re-price saved carts, clear cart after payment, safer checkout
    - A saved cart kept the name and price it was saved with. Returning
    visitors saw an old price after it changed (Square would charge the
    new one) and kept products that had been removed. Carts are now ids
    and quantities, re-priced from the products on the page at each load.
    - Cart lines were built with innerHTML from localStorage, so markup
    stored there ran on the page. Values now go in as text.
    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
2026-09-27 .htaccess: fix redirect loops, harden headers, add robots and sitemap
    Tested on Apache 2.4 with AllowOverride All. The shipped .htaccess
    sent every page into an endless redirect ("too many redirects"):
    - /drops: mod_dir added a trailing slash, the strip-slash rule took it
    off again, forever. Fixed with DirectorySlash Off.
    - / and every 404: Apache serves / from index.html internally, which
    matched the index.html -> / redirect. That rule now fires only when
    the visitor typed /index.html (THE_REQUEST).
    Also:
    - Options -Indexes, so /images/ can't list every uploaded file
    (including photos for a drop that isn't published yet).
    - nosniff, Referrer-Policy, frame-ancestors/X-Frame-Options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
2026-09-27 Docs: 2026.09.27 update notes, recommendations and security review
    README: what changed, the server requirements (AllowOverride All,
    DirectorySlash) and how to switch on HTTPS; fixed stale lines (the
    with-shop preview folder, images/shop, the clean-URL step build.py
    already does, "zero external requests" while Drops loads Carto tiles).
    RECOMMENDATIONS.md: what to do first, the state of the logo and the
    homepage animation, answers on how safe Drops and the Store are, and
    remaining page-by-page improvements.
    STORE-SETUP: og: tags are done.
    Claude-Session: https://claude.ai/code/session_01PgSAvoVVMWV8AY5nugqWL2
2026-09-28 Build: say when the Drops map needs making again
    One map file covers every drop, so it only needs remaking when a drop
    lands outside the area it was cut for. make-map.py now records the drop
    coordinates in the file; build.py reads them back (standard library
    only) and names any drop more than detail_km - 1 km from all of them,
    or says there is no map file yet.
    Tested: current drops, no warning; a drop in Los Angeles, warned by
    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
2026-09-28 Preview: double-click PREVIEW.cmd to see a build as the host serves it
    The -clean builds link to /style.css and /drops, so double-clicking one
    shows a bare page, and the Drops map needs a server that sends parts of
    files. Testing meant uploading.
    PREVIEW.cmd lists the builds (or takes a folder dragged onto it) and
    serves the chosen one at http://localhost:8940, then opens the browser.
    It needs nothing installed: tools/preview.ps1 runs on the PowerShell
    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
2026-09-29 Drops: new locations map themselves; no open/claimed; windows fly in
    A new drop location now gets its street map when you build. build.py
    checks every drop against the map before building and, when one is
    outside it, runs tools/make-map.py first. Tested with a drop added at
    33.390226, -111.868363 (Mesa, Arizona) in a copy of the site: build.py
    alone fetched the area (16.8 MB map, up from 10.8) and the page drew the
    streets there. make-map.py also cut one box around all the drops for
    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
2026-09-30 Drops: a world view first, then the drop, on one page
    The Drops page now opens on the world: the list of drops with their dates
    beside a globe with a point for each, after the destination screen the
    owner pointed to. Pointing at a drop turns the globe to it; choosing one
    flashes the row, dives the globe in, flies the list off, cuts on a red
    flash and flies the drop's windows in. < WORLD (at the head of the drop's
    list), Esc or Back fly them out and pull the globe back out.
    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
2026-10-03 Drops: a point for every drop, globe zoom, animated drop changes, WORLD MAP
    - Every drop has its own point on the globe. Drops too close to tell apart
    (the three in San Francisco were one "x3" point) sit on a small ring
    around the spot they share, each on a thread back to it, in the order
    they really lie; zooming in eases them into place.
    - The globe zooms: + and - buttons, a whole-globe button, the mouse wheel,
    a pinch, and the + - 0 keys, up to 16x (past that the 1:50m coastline
    turns to polygons). Long turns while zoomed in rise out on the way.
    - Changing drops on the drop screen (its list or the arrow keys) flies the
    record's windows out and back in, as choosing one from the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
2026-10-07 Drops: open a drop with OPEN DROP only; one drop per page; quick flights
    World view
    - Choosing a drop (list row, arrow keys, or its point on the globe) turns
    the globe to it and opens a prompt beside it with its name, date and
    OPEN DROP. That button, or the bar's, is the only way into a drop: rows
    are buttons now, and a second click or double-click on a point opens
    nothing. Pointing at a row marks its point instead of turning the globe.
    Enter on a row moves to the prompt's button; Enter again opens.
    - + zooms about the chosen drop only while the globe still points at it.
    Drop page
    - Shows one drop: drops.js's list is hidden and the arrow keys no longer
    step through drops. WORLD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
2026-10-09 Drops: ZOOM IN / ZOOM OUT labels follow where the globe is heading
    A short turn at 64x dips a hair below 64x mid-way, and the opened row's
    button (visible while the globe moves, on a phone) flickered from ZOOM OUT
    to ZOOM IN and back. The label now follows the zoom a turn is heading for.
    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
2026-10-11 Globe streets without closePath; quick zooms add up; nav fits tablets; README
    - The globe no longer closes each ring of its street map, land and lakes
    with closePath(): fill() closes them anyway, and Chrome's closePath()
    costs time in proportion to the whole path built so far. Over the
    streets' thousands of shapes at a cache's city that came to half a
    second a frame, which stalled OPEN CACHE from there and the pull back
    out (world to cache took 3.1 s with a 0.95 s frame; now 1.3 s, as
    before this round, its longest frame 0.12 s).
    - Quick presses of + and - each count: a press while a zoom is under
    way steps on from where that zoom is going, not from where it has got.
    - A flying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
2026-10-11 Globe names: one cheap pass per frame, on-screen duplicates only; README
    - The globe's names are no longer looked through with d3.geoDistance and
    fresh lower-case strings for every name on Earth in every frame. Each
    name's unit vector and key are worked out once; a frame keeps only those
    within the screen's own reach round the globe (and 1.2 radians, as
    before), three multiplications each. With the processor slowed four
    times, the flight to a chosen cache runs about twice as smoothly on a
    phone (11-12 frames a second to 20-22).
    - A name is said once among those on the screen, so one of the same name
    far off no longer hides it: Albany, California shows at San Francisco
    (Albany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
